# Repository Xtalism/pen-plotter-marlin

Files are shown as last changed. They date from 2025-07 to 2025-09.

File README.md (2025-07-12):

# Marlin CNC Pen Plotter

A custom Marlin firmware configuration for a 2-axis CNC pen plotter build. This project adapts the popular Marlin 3D printer firmware to control a pen plotting machine capable of drawing vector graphics and designs.

## Demonstration

https://github.com/user-attachments/assets/9c6dd8f6-1e95-47f4-82c9-25f74d2d10c8

## Features

- **2-Axis Control**: Precise X/Y movement for drawing applications
- **Servo Pen Control**: Automated pen lift/lower mechanism using servo motor
- **G-code Compatible**: Standard G-code interpretation for drawing commands
- **RAMPS 1.6 Based**: Uses standard 3D printer electronics (RAMPS 1.6 EFF)
- **PlatformIO Support**: Easy compilation and uploading using PlatformIO

## Hardware Requirements

- **Controller**: Arduino Mega 2560 with RAMPS 1.6 shield
- **Stepper Motors**: 2x stepper motors for X and Y axes
- **Servo Motor**: 1x servo for pen lift mechanism (connected to pin P0)
- **Stepper Drivers**: Compatible stepper motor drivers (A4988, DRV8825, etc.)
- **Power Supply**: 12V power supply for motors
- **Mechanical Frame**: Custom pen plotter frame (see blueprints/)

## Project Structure

```text
├── Marlin/                 # Modified Marlin firmware source code
├── gcode/                  # Example G-code files for testing
├── documentation/          # Project documentation (PDF)
├── blueprints/            # Hardware blueprints and schematics (PDF)
├── buildroot/             # Build tools and dependencies
├── platformio.ini         # PlatformIO configuration file
└── README.md              # This file
```

## Setup and Installation

### Prerequisites

1. Install [PlatformIO](https://platformio.org/) or use VS Code with PlatformIO extension
2. Clone this repository to your local machine

### Building and Uploading

1. Open the project in PlatformIO
2. Connect your Arduino Mega 2560 via USB
3. Build and upload the firmware:

   ```bash
   pio run --target upload
   ```

### Configuration

The main configuration is already set up for the pen plotter, but you may need to adjust:

- **Steps per mm**: Calibrate for your specific mechanical setup
- **Travel speeds**: Adjust drawing and travel speeds in `Configuration.h`
- **Servo angles**: Fine-tune pen up/down positions (currently S20 for down, S120 for up)

## Usage

### G-code Commands

The plotter responds to standard G-code commands:

- `G1 X## Y##`: Linear move to coordinates
- `G2/G3`: Circular/arc movements
- `M280 P0 S##`: Servo control (pen up/down)
  - `M280 P0 S20`: Pen down (drawing)
  - `M280 P0 S120`: Pen up (travel)
- `G28`: Home axes
- `G90`: Absolute positioning
- `G91`: Relative positioning

### Example Drawing Sequence

```gcode
M280 P0 S20        ; Pen up
G28 X Y            ; Home X and Y axes
G90                ; Absolute positioning
G1 F6000           ; Set feed rate
G1 X10 Y10         ; Move to start position
M280 P0 S120       ; Pen down
G1 X50 Y10         ; Draw line
G1 X50 Y50         ; Draw line
G1 X10 Y50         ; Draw line
G1 X10 Y10         ; Draw line (complete square)
M280 P0 S20        ; Pen up
```

## Sample Files

Check the `gcode/` directory for example drawing files. The included `UACJ.g` file demonstrates complex curved drawing using G2 arc commands.

## Documentation

- **Hardware Plans**: See `blueprints/blueprints.pdf` for mechanical drawings
- **Technical Documentation**: See `documentation/documentation.pdf` for detailed setup instructions

## Troubleshooting

### Common Issues

1. **Pen not lifting/lowering properly**
   - Check servo connections (should be connected to pin P0)
   - Adjust servo angle values in G-code (S20 for down, S120 for up)
   - Verify servo power supply

2. **Incorrect movement scaling**
   - Calibrate steps per mm in `Configuration.h`
   - Check belt tension and mechanical backlash

3. **Communication issues**
   - Verify baud rate settings (typically 250000)
   - Check USB cable and connections

## Contributing

This is a specialized firmware configuration. When making changes:

1. Test thoroughly with sample G-code
2. Document any configuration changes
3. Update this README if adding new features

## License

This project is based on Marlin firmware and inherits its GPL v3.0 license. See `LICENSE` file for details.

## Acknowledgments

- Based on [Marlin Firmware](https://github.com/MarlinFirmware/Marlin)
- Adapted for CNC pen plotting applications
- Thanks to the RepRap and maker communities for hardware designs

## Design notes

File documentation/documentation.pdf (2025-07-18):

# AUTONOMOUS UNIVERSITY OF CIUDAD JUAREZ ´

### MULTIDISCIPLINARY DIVISION OF CIUDAD UNIVERSITARIA

## DEPARTMENT OF INDUSTRIAL AND MANUFACTURING ENGINEERING

# Pen Plotter CNC

# Motors and Controllers

## Team Members:

## Manuel Pi˜na Olivas - 201060 Francisco Javier Hern´andez Guti´errez - 201215 Brenda Lizeth Mu˜noz Silva - 201820 Josu´e Jim´enez Ram´ırez - 201133 Luis Armando Enciso Nava - 215766

## Instructor:

## Mario Jim´enez Jim´enez

## July 15, 2025

# Contents

1 Introduction | 4
2 Objectives | 4
3 Theoretical Framework | 4
4 Requirements | 4
5 Implementation | 9
6 Results | 12
7 Conclusion | 13
8 Appendices | 14

# List of Figures

1 | WeMos Mega WiFi R3 ATmega2560 + ESP8266 32MB | | 4
2 | Ramps 1.6 | | 5
3 | 17HD48002H-22B | | 5
4 | SG90 | | 6
5 | RepRapDiscount 12864 | | 6
6 | DRV8825 | | 7
7 | Korad KD3005D | | 7
8 | Marlin Firmware | | 7
9 | PlatformIO | | 8
10 | VSCode | | 8
11 | Inkscape | | 8
12 | Pronterface | | 9
13 | Mini CNC Plotter Kit | | 9
14 | SolidWorks Design | 10
15 | Diagram made in Fritzing | 10
16 | Motor connections with Ramps 1.6 | 11
17 | Laser tool extension for Inkscape | 11
18 | Pronterface user interface | 12
19 | Results | 12
20 | Results | 13

# 1 Introduction

In this project, we will build a simple CNC machine to draw the logo of the Autonomous University of Ciudad Ju´arez (UACJ) on paper. We will use stepper motors to move a pencil, pen, or marker with precision, controlled by an Arduino board and configured with the respective Marlin firmware.

# 2 Objectives

Design and build a CNC machine controlled by Arduino and Marlin firmware, capable of autonomously drawing the UACJ logo on paper, using two stepper motors for the x and y axes, and a servomotor for the z axis.

## 2.1 Specific Objectives

- Design the mechanical structure of the CNC, ensuring stability and precision.
- Implement stepper motor control using Arduino.
- Configure the system using Marlin firmware.
- Generate G-code from a design in Inkscape.
- Test and calibrate the machine to ensure proper operation and precision.

# 3 Theoretical Framework

## 3.1 What is a CNC machine?

CNC (Computer Numerical Control) is an automated machine system that works with programmed commands or functions, whose instructions are stored on a storage disk. It is a machine tool used for:

- Machining parts from various materials.
- Automated processes.
- Computer programming.
- Computer control.

# 4 Requirements

## 4.1 Hardware

## 4.1.1 Microcontroller

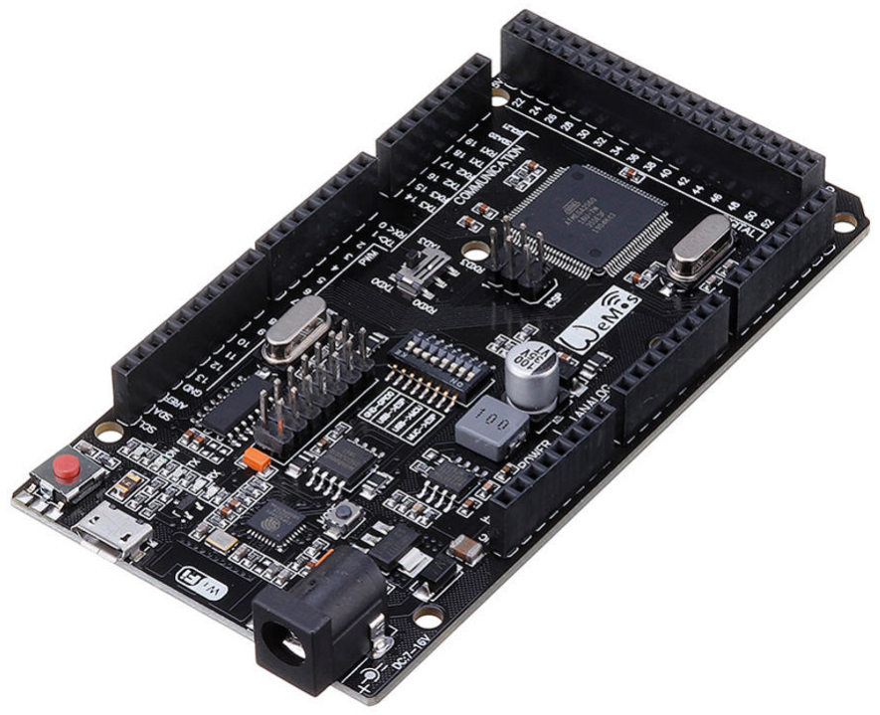
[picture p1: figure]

Figure 1: WeMos Mega WiFi R3 ATmega2560 + ESP8266 32MB.

The Arduino is an open-source electronic board based on a reprogrammable microcontroller. It is designed to facilitate the development of electronic projects through the connection of various sensors, actuators, and other devices through its digital and analog input and output pins.

## 4.1.2 Expansion Board

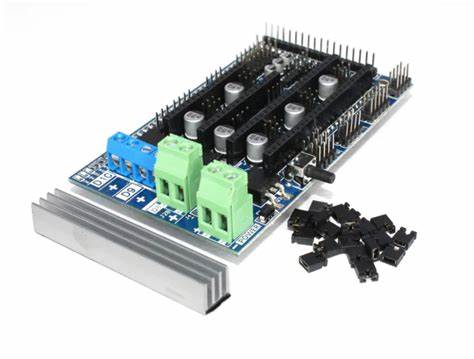
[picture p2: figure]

Figure 2: Ramps 1.6.

## The Ramps 1.6 expansion board is designed to be mounted on an Arduino Mega 2560. Its

main function is to facilitate the connection and control of up to five stepper motors independently, corresponding to the X, Y, Z axes and two extruders (E0 and E1). This board is commonly used in 3D printers and CNC machines, as it allows the integration of drivers such as A4988 or DRV8825, in addition to other components such as switches, fans, and thermistors.

## 4.1.3 Stepper Motor

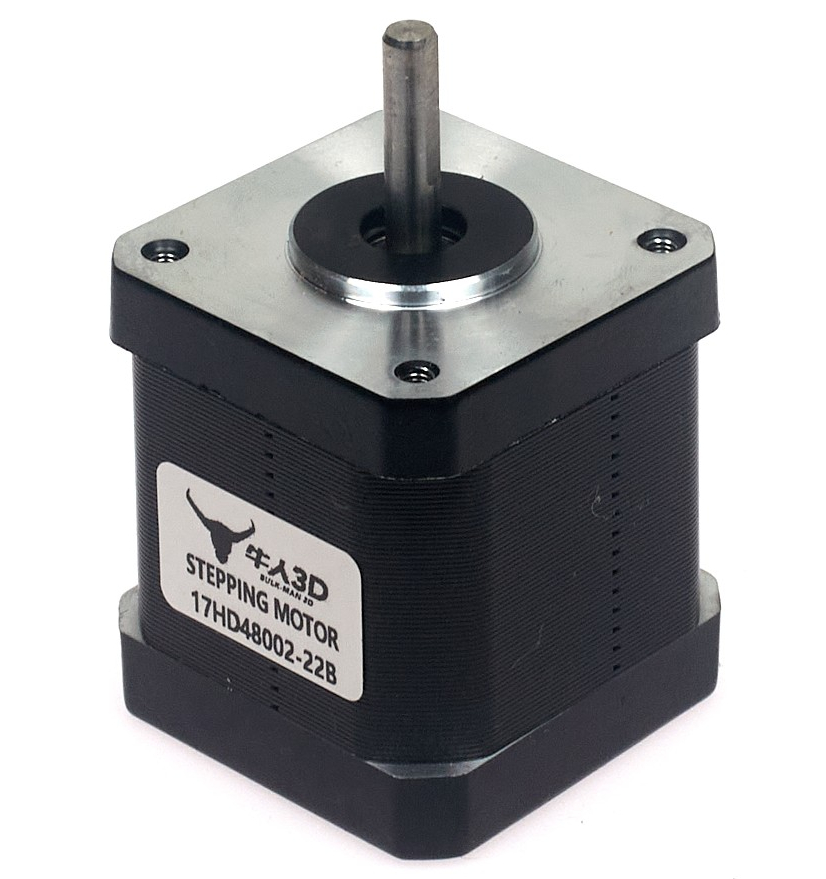
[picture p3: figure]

Figure 3: 17HD48002H-22B.

It is a NEMA 17 type stepper motor, ideal for precision applications such as CNC machines. It offers a step angle of 1.8° (200 steps per revolution) and operates with a current of 1.5 A per phase. Its compact size and good torque make it suitable for moving the x, y, and z axes of the project with high precision.

## 4.1.4 Servomotor

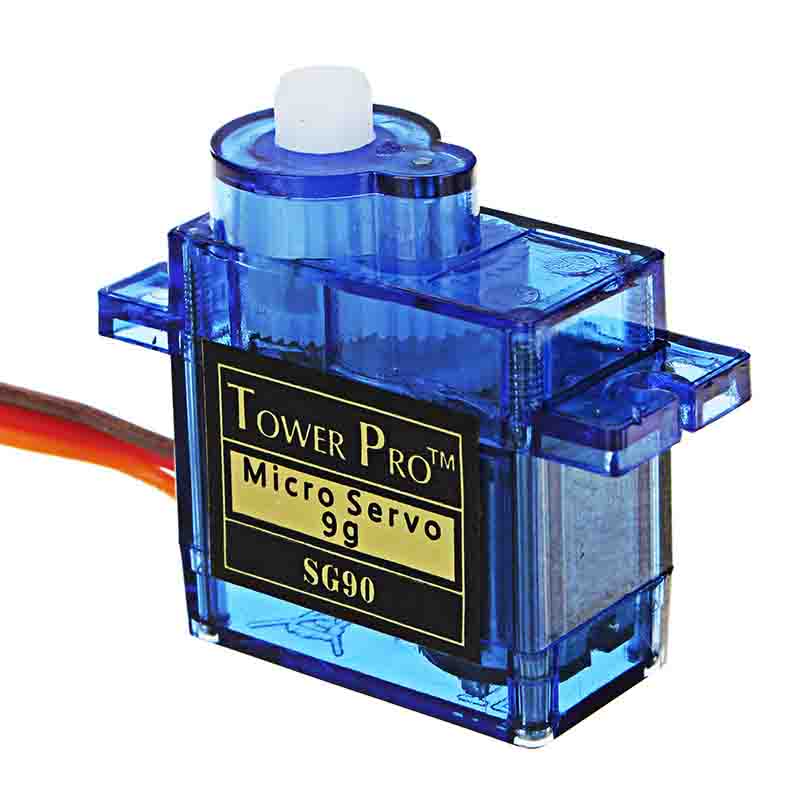
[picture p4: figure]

Figure 4: SG90.

The SG90 servomotor is a compact and lightweight actuator commonly used in robotics. It operates on 4.8–6V and rotates about 180°, controlled by PWM signals. In this project, it lifts and lowers the pen, allowing the CNC to draw or move without marking the paper.

## 4.1.5 Display Screen

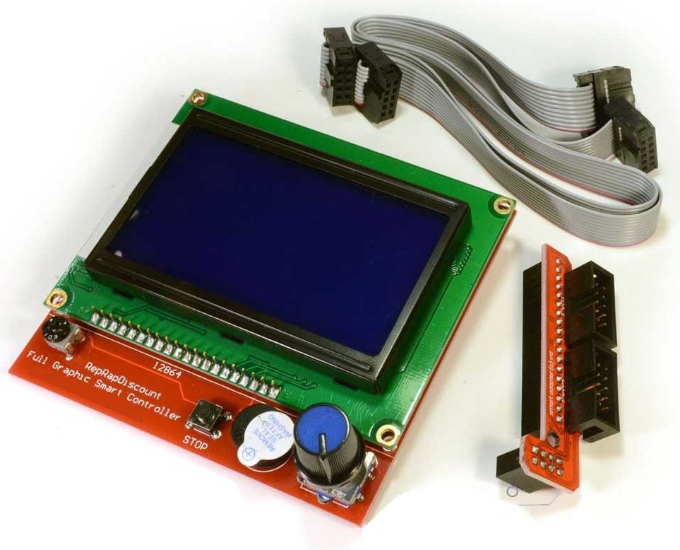
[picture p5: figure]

Figure 5: RepRapDiscount 12864.

It is a complete module that includes a 128×64 pixel dot matrix LCD screen, an SD card reader, and a rotary encoder. This device allows controlling a 3D printer or CNC machine autonomously, without the need for a computer, displaying process information and facilitating navigation through the firmware menu.

## 4.1.6 Drivers

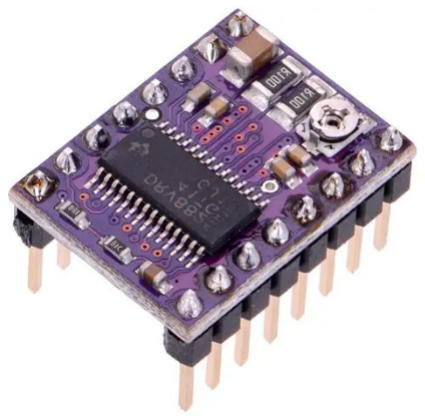
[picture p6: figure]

Figure 6: DRV8825.

The DRV8825 driver is a bipolar stepper motor controller, which is used to control stepper motors, especially in applications that require high precision and movement resolution, such as 3D printers and CNC machines.

## 4.1.7 Adjustable Power Supply

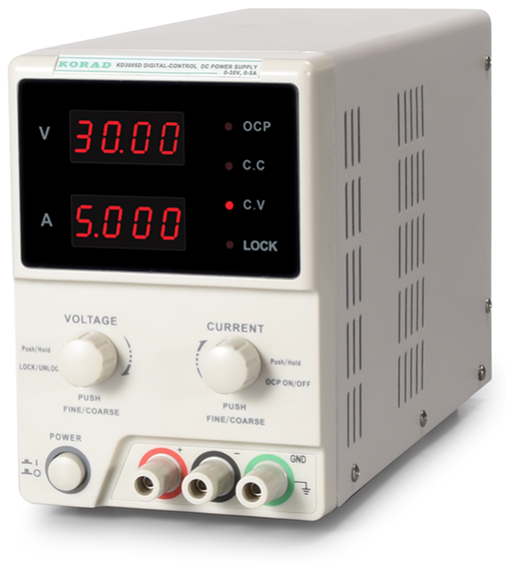
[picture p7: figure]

Figure 7: Korad KD3005D.

The Korad KD3005D power supply is a versatile instrument designed for various electronic applications. It features an adjustable voltage range of up to 30V and a maximum current of 5A.

## 4.2 Software

## 4.2.1 Marlin Firmware

Figure 8: Marlin Firmware.

Marlin is an open-source firmware widely used to control 3D printers, CNC machines, laser engravers, and plotters. It is responsible for interpreting G-code commands and converting them into physical movements, controlling motors, servos, and sensors. It is compatible with boards such as RAMPS or SKR, and allows easy configuration of parameters such as axes, limits, and servomotors.

## 4.2.2 PlatformIO

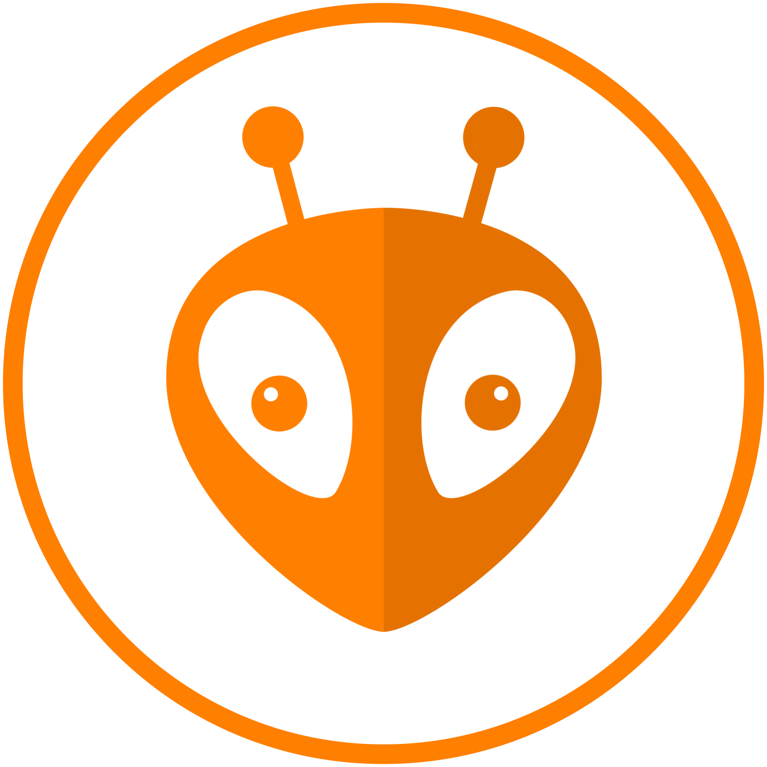
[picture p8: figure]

Figure 9: PlatformIO.

PlatformIO is an open-source development environment used with Visual Studio Code to program microcontrollers. It allows compiling and uploading firmware like Marlin quickly and in an organized manner.

## 4.2.3 VSCode

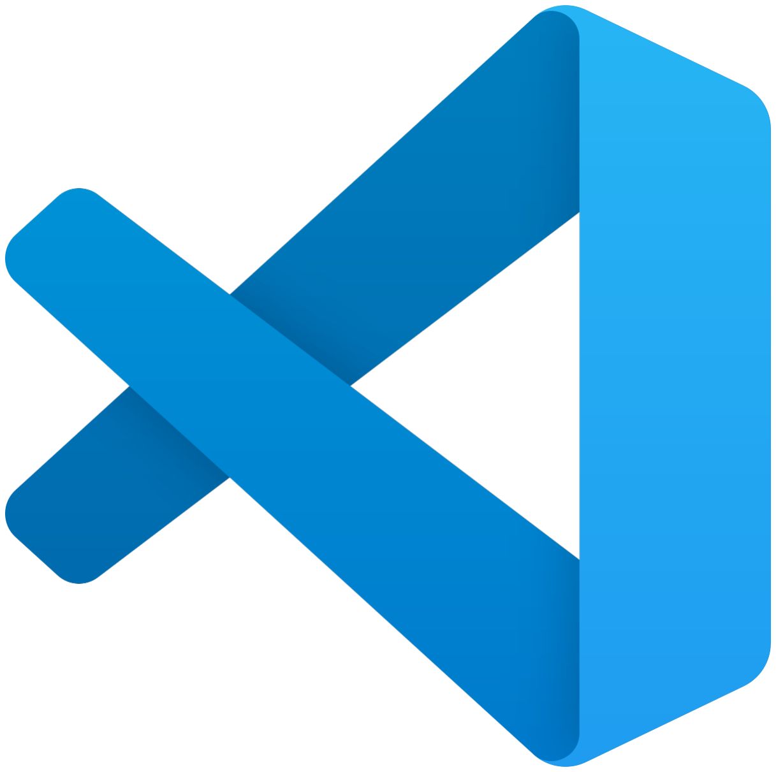
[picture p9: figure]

Figure 10: VSCode.

Visual Studio Code (VS Code) is a lightweight and cross-platform code editor developed by Microsoft. It is widely used by programmers thanks to its speed, customization, and support for extensions.

## 4.2.4 Inkscape

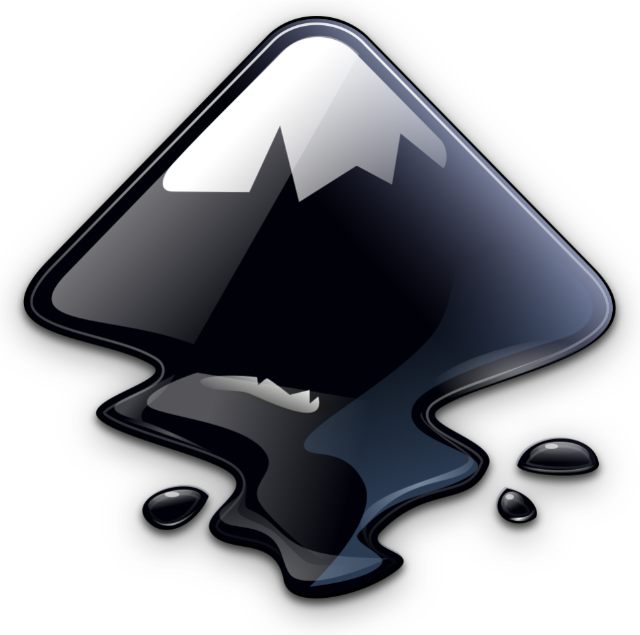
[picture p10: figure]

Figure 11: Inkscape.

Inkscape is an open-source vector graphics design software, used to create and edit images in SVG format.

## 4.2.5 Pronterface

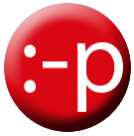
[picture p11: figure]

Figure 12: Pronterface.

Pronterface is a graphical interface of the Printrun program, used to control 3D printers and CNC machines from a computer. It allows sending G-code commands, moving axes, controlling temperature (in 3D printers), and monitoring the machine’s status in real time.

# 5 Implementation

## 5.1 Structure

We had an already built structure made of pressed wood, which was adapted according to the needs that arose during the project development. In particular, modifications were made to the axes and the arrangement of the motors within the structure was changed.

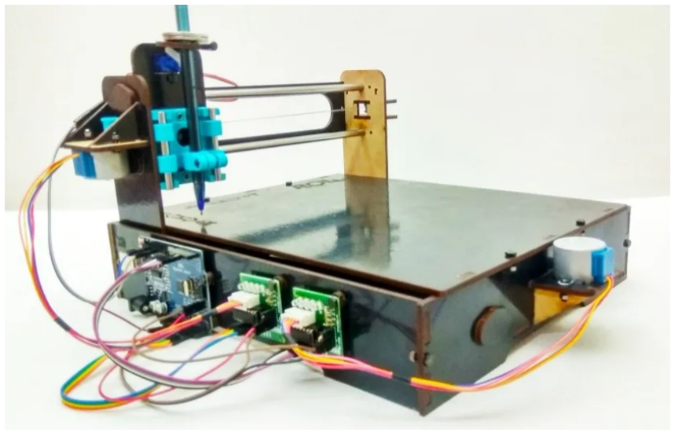
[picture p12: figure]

Figure 13: Mini CNC Plotter Kit.

## 5.2 Motor Assembly

The structure design was created in SolidWorks according to the requested structure.

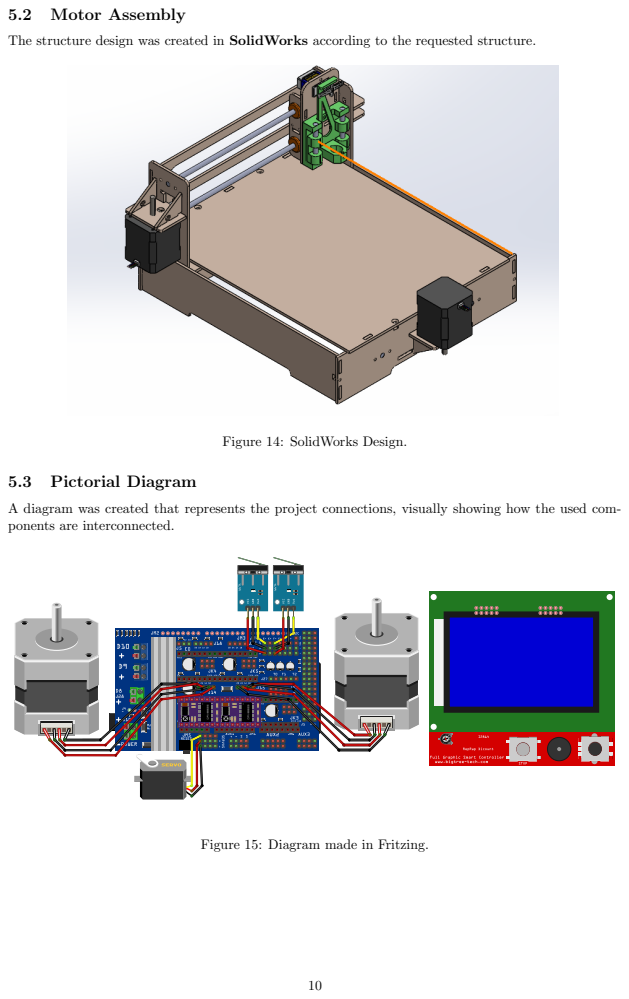
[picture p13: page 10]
5.3 Pictorial Diagram

Figure 14: SolidWorks Design.

A diagram was created that represents the project connections, visually showing how the used com-
ponents are interconnected.

Figure 15: Diagram made in Fritzing.

## 5.4 Motor Testing and Connection

After generating the G-code, a test was performed with the NEMA 17 stepper motors. Using the RepRapDiscount controller, it was possible to start and stop work directly from the SD card. Additionally, this controller allows easy adjustment of parameters such as motor position and speed.

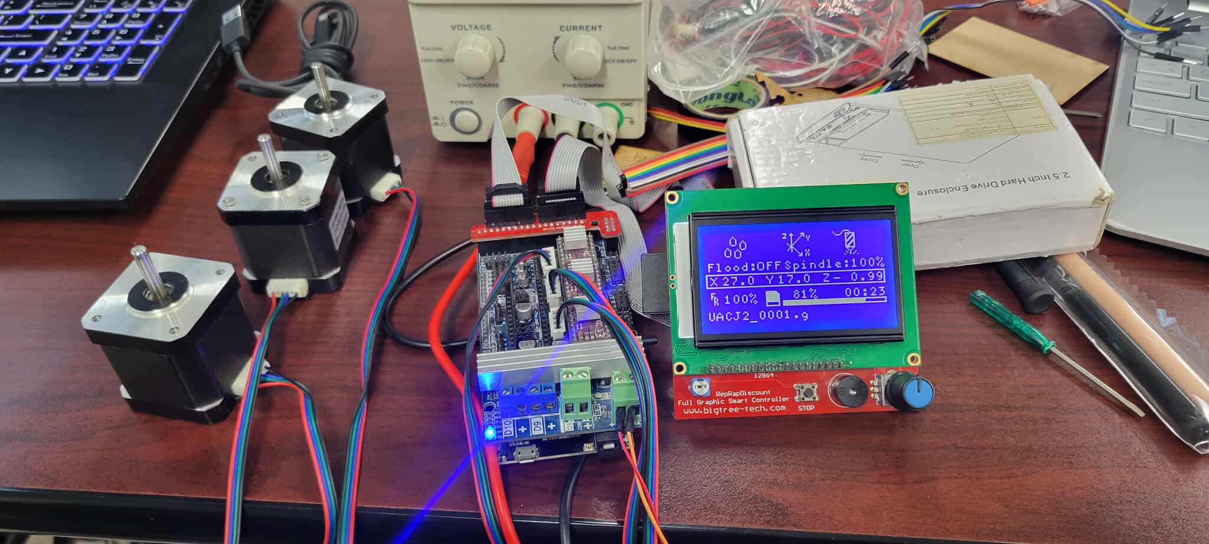
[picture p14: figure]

Figure 16: Motor connections with Ramps 1.6.

## 5.5 G-code Generation

During the project, Inkscape software was used to design vector graphics. Then, with the help of the J Tech Photonics Laser Tool extension, we converted these designs into G-code, which can be interpreted by the intelligent graphic controller RepRapDiscount 12864. This controller works together with stepper motors and Marlin firmware, allowing the motors to perform the necessary movements for engraving with precision.

At the bottom, the offset is defined, which corresponds to the distance difference between the limit switch and the tool tip (in this case, a pen).

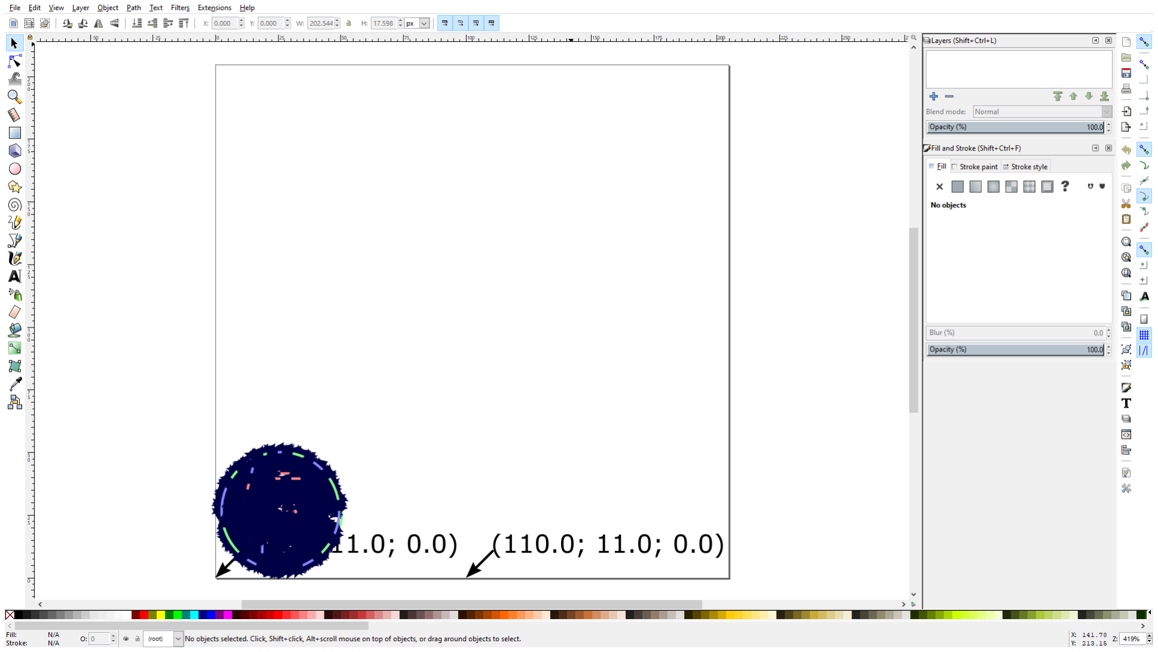
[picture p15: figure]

Figure 17: Laser tool extension for Inkscape.

## 5.6 Pronterface Graphical Interface

The Pronterface tool was used, which helps us manipulate our CNC machine in real time, usually used in 3D printer applications, since it has extruder calibration and other tools that conventional CNC does not have.

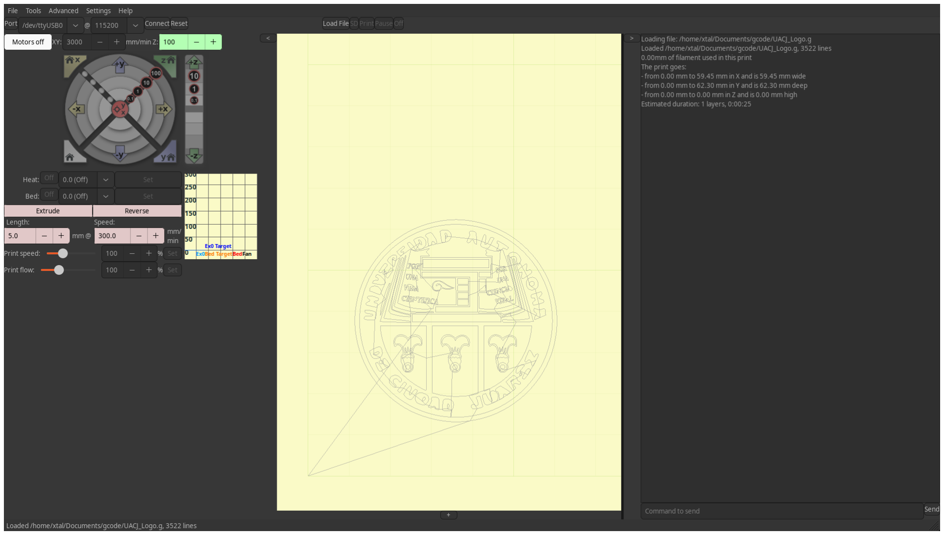
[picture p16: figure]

Figure 18: Pronterface user interface.

# 6 Results

In this project we were asked to build a machine capable of drawing our university’s logo on a sheet of paper. At first, we faced several problems related to the structure, motor calibration, Marlin firmware adjustment, and converting the logo design to G-code, so that the machine could interpret it correctly.

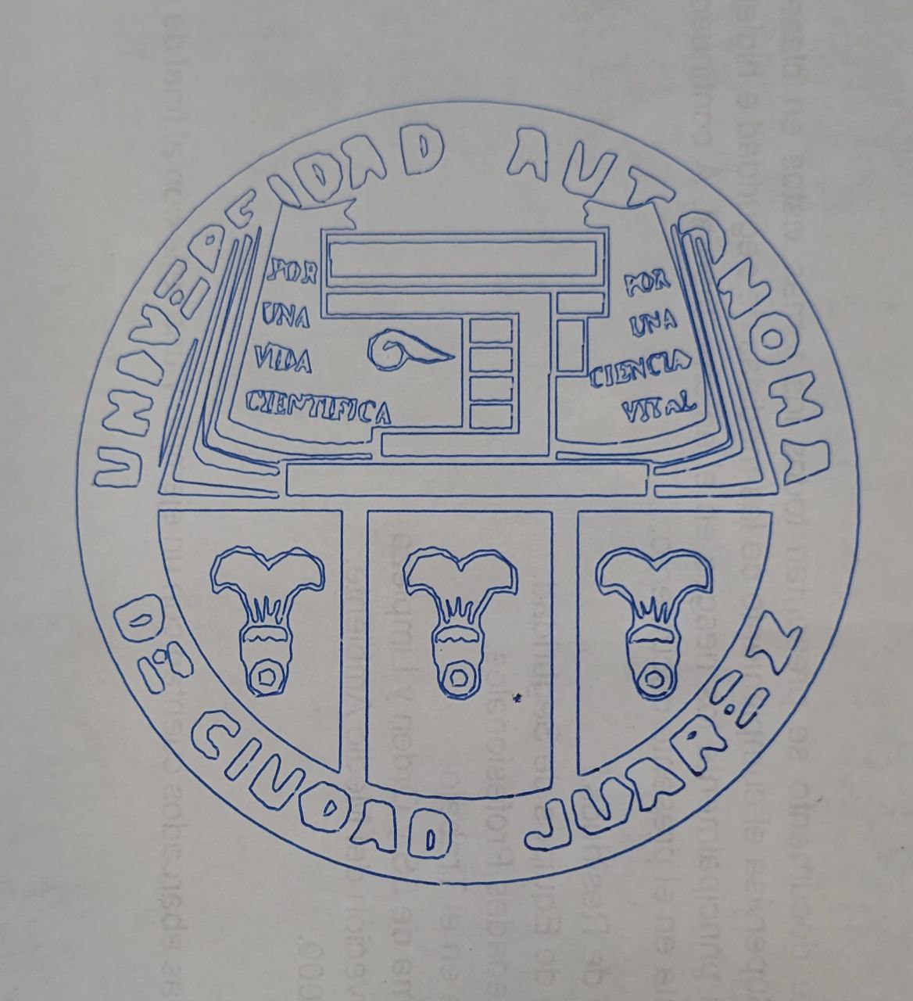
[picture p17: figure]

Figure 19: Results.

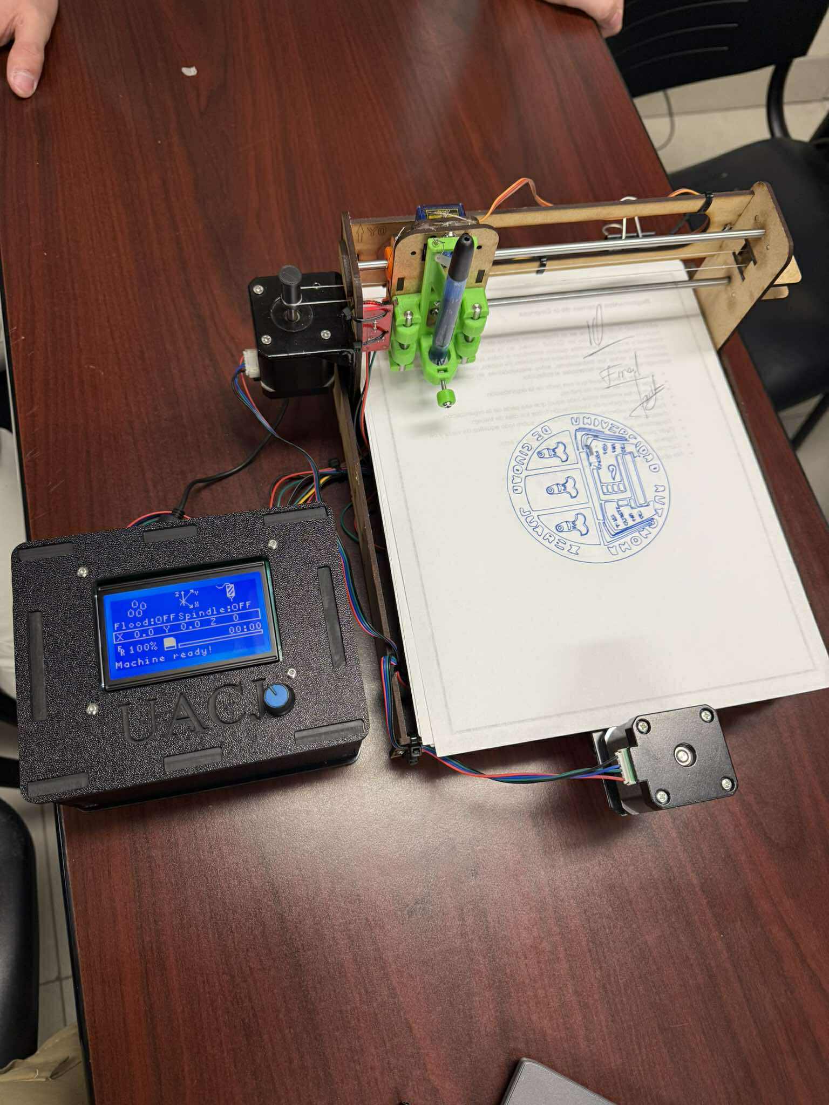
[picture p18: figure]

Figure 20: Results.

# 7 Conclusion

A favorable results were obtained, as the main objective of the project was met: tracing our university’s logo on a sheet of paper using a CNC machine. To achieve this, it was necessary to correctly calibrate the NEMA 17 motors, adjust the firmware, precisely define the auto-homing point, and configure the appropriate servomotor angle.

# 8 Appendices

## 8.1 Code

## 8.1.1 UACJ Logo.g

M280 P0 S20

G28 X Y
G90
G21
G1 F6000
G1 X34 .7377 Y14 .3117
G4 P0
M280 P0 S120
G4 P0
G1 F6000 .000000
G2 X26 .4091 Y16 .3335 I1 .334 J23 .6603 G2 X19 .3821 Y21 .1688 I9 .571 J21 .4332 G2 X12 .6272 Y35 .4445 I16 .5822 J16 .5823 G2 X16 .4597 Y50 .7368 I23 .2545 J2 .2983 G2 X21 .9957 Y56 .5497 I19 .5624 J -13.088 G2 X29 .1377 Y60 .1452 I13 .9169 J -18.7533 G2 X34 .9376 Y61 .1307 I6 .7886 J -22.3931 G2 X40 .8819 Y60 .6419 I1 .0162 J -24.0294 G2 X49 .1268 Y57 .1466 I -4.7447 J -22.6641 G2 X55 .4987 Y50 .7368 I -13.2307 J -19.5245 G2 X59 .4501 Y37 .7245 I -19.4494 J -13.0123 G2 X55 .4987 Y24 .7122 I -23.4008 J -0.
G2 X49 .0307 Y18 .2314 I -19.66 J13 .1532 G2 X40 .6969 Y14 .7669 I -12.8175 J19 .0766 G2 X37 .5845 Y14 .3401 I -5.1057 J25 .6673 G2 X34 .7377 Y14 .3117 I -1.6371 J21 .4313 G1 X34 .7377 Y14 .3117
G4 P0
M280 P0 S20
G1 F6000
G1 X35 .0065 Y16 .0285
G4 P0
M280 P0 S120
G4 P0
G1 F6000 .000000
G3 X35 .1255 Y16 .2189 I -0.6845 J0 .5602 G3 X35 .2755 Y16 .6132 I -2.8294 J1 .3021 G3 X35 .3128 Y17 .8567 I -2.2662 J0 .6904 G3 X34 .8347 Y18 .4489 I -0.8623 J -0.2071 G3 X33 .6066 Y18 .7623 I -1.3938 J -2.8994 G3 X33 .0325 Y18 .5414 I -0.039 J -0.7553 G3 X32 .8354 Y18 .1516 I0 .4932 J -0.4941 G3 X32 .6715 Y16 .1507 I14 .5893 J -2.2024 G1 X32 .758 Y16 .0081
G3 X33 .2686 Y15 .8505 I0 .7246 J1 .4416 G3 X34 .6362 Y15 .8293 I0 .7737 J5 .7772 G3 X35 .0065 Y16 .0282 I -0.0562 J0 .5486 G1 X35 .0065 Y16 .0285
G4 P0
M280 P0 S20
G1 F6000
G1 X33 .8685 Y16 .3294
G4 P0
M280 P0 S120
G4 P0
G1 F6000 .000000
G1 X33 .8441 Y16 .4179 F6000 .000000 G2 X33 .8757 Y16 .8033 I2 .9091 J -0.0446 G3 X33 .9285 Y17 .1948 I -13.3793 J2 .006 G3 X33 .9428 Y17 .3618 I -2.416 J0 .2904
G1 | X33 .9971 Y17 .4811
G1 | X34 .1168 Y17 .5294
G1 | X34 .2213 Y17 .4643
G2 X34 .3074 Y17 .1406 I -0.7731 J -0.3791

G2 X34 .1312 Y16 .3371 I -1.4841 J -0.0956
G1 | X33 .8684 Y16 .3295
G1 | X33 .8685 Y16 .3294
G4 P0
M280 P0 S20
G1 F6000
G1 X31 .9234 Y16 .2258
G4 P0
M280 P0 S120
G4 P0
G1 F6000 .000000
G3 X31 .8001 Y18 .6873 I -25.5462 J -0.0456 G3 X31 .6559 Y18 .9357 I -0.3445 J -0.034 G3 X31 .2165 Y19 .1315 I -0.7072 J -0.9959 G3 X30 .3642 Y19 .2261 I -0.8522 J -3.792 G3 X30 .0654 Y19 .0334 I0 . J -0.3281
G3 X30 .0285 Y18 .4853 I0 .7134 J -0.3233 G2 X30 .0193 Y18 .1896 I -0.4477 J -0.1341 G2 X29 .6592 Y17 .4834 I -3.1474 J1 .1599
G1 | X29 .1967 Y16 .7925
G1 | X29 .4523 Y16 .685
G3 X30 .0127 Y16 .6056 I0 .4312 J1 .0254 G3 X30 .302 Y16 .7844 I -0.0466 J0 .399 G2 X30 .7416 Y16 .937 I0 .3187 J -0.2088 G2 X30 .957 Y16 .5654 I -0.1029 J -0.3079 G3 X30 .9273 Y16 .343 I1 .698 J -0.3399
G1 | X30 .9408 Y16 .328
G1 | X30 .971 Y16 .3224
G2 X31 .3029 Y16 .2075 I -4.6817 J -14.0476 G3 X31 .8247 Y16 .1245 I0 .4788 J1 .329
G1 | X31 .9234 Y16 .2265
G1 | X31 .9234 Y16 .2258
G4 P0
M280 P0 S20
G1 F6000
G1 X28 .556 Y17 .4023
G4 P0
M280 P0 S120
G4 P0
G1 F6000 .000000
G3 X28 .7645 Y17 .5703 I -0.5352 J0 .8773 G3 X29 .0733 Y17 .9446 I -2.4472 J2 .3336 G3 X29 .3233 Y18 .6451 I -1.1155 J0 .793 G3 X29 .1716 Y19 .3948 I -1.4443 J0 .0979 G3 X28 .9186 Y19 .6898 I -0.7243 J -0.3652 G3 X28 .2819 Y20 .0299 I -1.6256 J -2.2774 G3 X27 .5769 Y20 .2892 I -15.0499 J -39.8365 G1 X27 .5301 Y20 .2989
G3 X26 .1743 Y19 .4646 I -0.1074 J -1.3442 G3 X26 .5103 Y17 .8202 I1 .3976 J -0.5709 G3 X26 .5947 Y17 .7602 I0 .2245 J0 .2264 G3 X27 .2473 Y17 .4594 I6 .8276 J13 .9536 G3 X28 .0559 Y17 .2734 I0 .9083 J2 .0973 G3 X28 .556 Y17 .4023 I0 .0386 J0 .8845 G1 X28 .556 Y17 .4023
G4 P0
M280 P0 S20
G1 F6000
G1 X27 .7025 Y18 .2689
G4 P0
M280 P0 S120
G4 P0
G1 F6000 .000000
G1 X27 .7092 Y18 .3035 F6000 .000000
G2 X27 .9177 Y18 .8011 I20 .1741 J -8.1607 G2 X28 .1642 Y19 .2228 I1 .8765 J -0.8137 G1 X28 .2576 Y19 .2495
G2 X28 .4956 Y18 .6796 I -0.1531 J -0.3985 G2 X27 .8122 Y18 .2329 I -0.6834 J0 .2995
G1 | X27 .7169 Y18 .2487
G1 | X27 .7025 Y18 .2687

G1 X27 .7025 Y18 .2689
G4 P0
M280 P0 S20
G1 F6000
G1 X25 .9498 Y19 .6144
G4 P0
M280 P0 S120
G4 P0
G1 F6000 .000000
G3 X26 .5964 Y20 .6586 I -7.1429 J5 .1454 G1 X26 .5777 Y20 .807
G3 X26 .4348 Y20 .9289 I -0.5434 J -0.4925 G3 X26 .2021 Y21 .0515 I -0.7764 J -1.1913 G1 X25 .9508 Y21 .0094
G3 X25 .3784 Y20 .3231 I1 .9616 J -2.2179 G2 X24 .9442 Y19 .7548 I -2.8184 J1 .7031 G2 X24 .7432 Y19 .6563 I -0.2337 J0 .2226 G1 X24 .5777 Y19 .8276
G2 X24 .8848 Y20 .696 I2 .2463 J -0.3059 G3 X25 .1138 Y21 .5274 I -1.3549 J0 .8204 G3 X24 .8766 Y21 .8797 I -0.3843 J -0.0027 G1 X24 .609 Y21 .8255
G3 X23 .7825 Y20 .7712 I4 .1923 J -4.1374
G1 | X23 .2317 Y19 .8745
G1 | X23 .3907 Y19 .6538
G3 X24 .2736 Y18 .7924 I2 .9027 J2 .092 G3 X24 .9788 Y18 .5677 I0 .7272 J1 .0632 G1 X25 .154 Y18 .6415
G3 X25 .9499 Y19 .6144 I -7.527 J6 .9689 G1 X25 .9498 Y19 .6144
G4 P0
M280 P0 S20
G1 F6000
G1 X23 .2241 Y21 .354
G4 P0
M280 P0 S120
G4 P0
G1 F6000 .000000
G3 X23 .985 Y22 .4049 I -12.6428 J9 .955 G1 X23 .9801 Y22 .4921
G3 X23 .8989 Y22 .5679 I -0.3429 J -0.2861 G3 X23 .6612 Y22 .7231 I -1.7558 J -2.4285
G1 | X23 .4145 Y22 .868
G1 | X22 .5692 Y21 .8273
G1 | X21 .7239 Y20 .7866
G1 | X21 .956 Y20 .5444
G3 X22 .2006 Y20 .3317 I1 .2837 J1 .2293
G1 | X22 .292 Y20 .3022
G1 | X22 .3773 Y20 .3406
G3 X23 .2241 Y21 .3541 I -17.0127 J15 .0761 G1 X23 .2241 Y21 .354
G4 P0
M280 P0 S20
G1 F6000
G1 X21 .2813 Y21 .5938
G4 P0
M280 P0 S120
G4 P0
G1 F6000 .000000
G1 X21 .3673 Y21 .6747 F6000 .000000 G3 X21 .4122 Y21 .8824 I -0.4591 J0 .2077 G3 X21 .3454 Y22 .084 I -0.3379 J0 .
G3 X21 .0779 Y22 .3318 I -0.799 J -0.5942 G2 X20 .6998 Y22 .7905 I0 .507 J0 .8032 G2 X20 .7192 Y23 .2536 I0 .5381 J0 .2094 G2 X21 .1257 Y23 .6114 I0 .6335 J -0.3098 G2 X21 .6458 Y23 .5687 I0 .2109 J -0.6202 G2 X21 .9111 Y23 .3696 I -0.5152 J -0.9627 G2 X22 .0685 Y23 .1368 I -0.5613 J -0.5492 G3 X22 .2232 Y22 .9235 I0 .5714 J0 .2516 G1 X22 .3688 Y22 .8678

G3 X22 .7444 Y23 .471 I0 . J0 .4185
G3 X21 .5931 Y24 .4456 I -1.6926 J -0.8322 G3 X20 .4753 Y24 .3138 I -0.4067 J -1.3574 G3 X19 .7619 Y23 .3832 I0 .7719 J -1.3306 G3 X19 .7026 Y23 .0392 I1 .8319 J -0.4931 G3 X19 .7192 Y22 .841 I0 .6133 J -0.0483 G3 X19 .9435 Y22 .4025 I1 .0613 J0 .2664 G3 X20 .6108 Y21 .7823 I2 .8637 J2 .4118 G3 X21 .025 Y21 .5819 I0 .7692 J1 .0619 G3 X21 .2812 Y21 .5938 I0 .1103 J0 .3922 G1 X21 .2813 Y21 .5938
G4 P0
M280 P0 S20
G1 F6000
G1 X23 .6592 Y25 .3258
G4 P0
M280 P0 S120
G4 P0
G1 F6000 .000000
G2 X23 .4116 Y25 .4962 I0 .4589 J0 .9321 G2 X23 .1754 Y25 .7744 I1 .0439 J1 .1255 G2 X23 .0349 Y26 .1042 I0 .8266 J0 .5469 G2 X22 .9968 Y26 .57 I1 .6431 J0 .3689
G3 X22 .9594 Y27 .033 I -1.683 J0 .097
G3 X22 .8358 Y27 .2937 I -0.6342 J -0.1411 G2 X22 .7019 Y27 .5524 I0 .6097 J0 .4797 G2 X22 .6522 Y27 .9115 I1 .152 J0 .3424 G3 X22 .6436 Y28 .2884 I -5.1362 J0 .0717 G3 X22 .6039 Y28 .7216 I -6.7752 J -0.4033 G2 X22 .6459 Y29 .1212 I0 .8812 J0 .1092 G2 X22 .8611 Y29 .4649 I0 .8547 J -0.2958
G1 | X23 .1719 Y29 .7757
G1 | X23 .0742 Y30 .3061
G3 X22 .5764 Y31 .4827 I -2.9046 J -0.5352 G3 X21 .9681 Y31 .8613 I -0.7571 J -0.5385 G3 X21 .6953 Y31 .84 I -0.0925 J -0.573 G3 X21 .4559 Y31 .6925 I0 .1868 J -0.5713 G2 X21 .2337 Y31 .4889 I -2.4357 J2 .4357
G1 | X21 .1975 Y31 .4758
G1 | X20 .9903 Y31 .6273
G2 X20 .8346 Y32 .6165 I3 .1534 J1 .003 G2 X21 .2956 Y33 .7747 I1 .6679 J0 .007 G2 X22 .4886 Y34 .3506 I1 .3631 J -1.3001 G2 X23 .2458 Y34 .247 I0 .154 J -1.6933 G2 X24 .0375 Y33 .763 I -0.8899 J -2.3451
G1 | X24 .3664 Y33 .4658
G1 | X24 .5551 Y33 .6667
G2 X26 .1692 Y34 .3058 I1 .4865 J -1.3964 G2 X27 .5534 Y33 .4788 I -0.1101 J -1.7561 G2 X27 .6781 Y33 .1536 I -0.7834 J -0.4872 G2 X27 .7439 Y32 .4109 I -4.1631 J -0.7427 G2 X27 .5359 Y31 .7328 I -1.2093 J -0.
G1 X27 .2471 Y31 .6774
G3 X26 .7261 Y31 .8498 I -0.5643 J -0.8315 G3 X26 .2278 Y31 .7214 I -0.0381 J -0.883 G3 X25 .8212 Y31 .2751 I0 .5601 J -0.9187 G3 X25 .4811 Y30 .1935 I3 .4098 J -1.6663 G3 X25 .4831 Y29 .7198 I1 .4789 J -0.2306 G3 X25 .6013 Y29 .4629 I0 .5264 J0 .0866 G2 X25 .8065 Y28 .9725 I -0.681 J -0.573 G2 X25 .6873 Y28 .5406 I -0.6296 J -0.0587 G1 X25 .6376 Y28 .3828
G3 X25 .6955 Y28 .148 I0 .5521 J0 .0116 G2 X25 .7579 Y27 .9059 I -0.5345 J -0.2667 G2 X25 .7154 Y27 .6666 I -0.564 J -0.0232 G2 X25 .5981 Y27 .4383 I -1.4462 J0 .5988 G2 X25 .5118 Y27 .3394 I -0.3485 J0 .2169 G1 X25 .4657 Y27 .2367
G3 X25 .5268 Y26 .8925 I1 .2337 J0 .0415 G2 X25 .1313 Y25 .5034 I -1.2231 J -0.4026 G2 X23 .6592 Y25 .3257 I -0.8723 J1 .0397

G1 X23 .6592 Y25 .3258
G4 P0
M280 P0 S20
G1 F6000
G1 X23 .8952 Y26 .0958
G4 P0
M280 P0 S120
G4 P0
G1 F6000 .000000
G2 X23 .8252 Y26 .8236 I0 .4063 J0 .4063 G2 X24 .5012 Y26 .9935 I0 .4328 J -0.2922 G2 X24 .7172 Y26 .7831 I -0.2476 J -0.47 G2 X24 .8044 Y26 .4522 I -0.5966 J -0.3342 G2 X24 .4796 Y25 .9738 I -0.5115 J -0.0023 G2 X23 .8952 Y26 .0958 I -0.199 J0 .5075 G1 X23 .8952 Y26 .0958
G4 P0
M280 P0 S20
G1 F6000
G1 X24 .9593 Y25 .6433
G4 P0
M280 P0 S120
G4 P0
G1 F6000 .000000
G3 X25 .3568 Y26 .4394 I -0.7217 J0 .8577 G3 X25 .0475 Y27 .2482 I -1.0597 J0 .0583 G3 X24 .334 Y27 .5566 I -0.7458 J -0.7458 G3 X23 .576 Y27 .2931 I -0.0344 J -1.1231 G3 X23 .211 Y26 .6299 I0 .677 J -0.8046 G3 X23 .3821 Y25 .8645 I1 .1186 J -0.1518 G3 X24 .1115 Y25 .3993 I0 .874 J0 .566 G3 X24 .9593 Y25 .6432 I0 .1505 J1 .0725 G1 X24 .9593 Y25 .6433
G4 P0
M280 P0 S20
G1 F6000
G1 X23 .0087 Y28 .6614
G4 P0
M280 P0 S120
G4 P0
G1 F6000 .000000
G1 | X23 .1416 Y28 .8079 F6000 .000000
G1 | X23 .2331 Y28 .7442
G1 | X23 .376 Y28 .6166
G1 | X23 .5941 Y28 .7856
G1 | X23 .7776 Y28 .9359
G1 | X23 .8952 Y28 .8366
G1 | X24 .0565 Y28 .6555
G1 | X24 .2816 Y28 .7918
G1 | X24 .4862 Y28 .9301
G1 | X24 .6929 Y28 .7858
G1 | X24 .8913 Y28 .6413
G1 | X25 .0763 Y28 .7653
G1 | X25 .1317 Y28 .7952
G2 X25 .2884 Y28 .7127 I -0.0894 J -0.3603
G1 | X25 .4425 Y28 .6462
G1 | X25 .5163 Y28 .6923
G3 X25 .5146 Y29 .0511 I -0.4616 J0 .1772 G3 X25 .2426 Y29 .3851 I -0.6625 J -0.2617 G3 X25 .0033 Y29 .4747 I -0.3179 J -0.4848 G3 X24 .1743 Y29 .5311 I -0.829 J -6.063 G3 X23 .3503 Y29 .4654 I -0. J -5.2016
G3 X23 .0965 Y29 .3582 I0 .0915 J -0.5703 G3 X22 .8298 Y29 .0142 I0 .487 J -0.653 G3 X22 .8026 Y28 .6414 I0 .556 J -0.228
G1 | X22 .9024 Y28 .571
G1 | X23 .0087 Y28 .6619
G1 | X23 .0087 Y28 .6614
G4 P0
M280 P0 S20
G1 F6000

G1 X25 .2195 Y30 .0622
G4 P0
M280 P0 S120
G4 P0
G1 F6000 .000000
G2 X25 .5445 Y31 .37 I2 .7936 J -0.
G2 X26 .2565 Y32 .0198 I1 .2632 J -0.6692 G2 X26 .866 Y32 .1407 I0 .6031 J -1.4434 G2 X27 .2594 Y32 .0148 I -0.0028 J -0.686 G3 X27 .429 Y31 .9319 I0 .3485 J0 .4982 G1 X27 .4847 Y31 .9458
G3 X27 .5802 Y32 .1996 I -0.2328 J0 .2325 G3 X27 .417 Y32 .9898 I -2.9071 J -0.1884 G3 X27 .1284 Y33 .467 I -1.3123 J -0.468 G3 X26 .6679 Y33 .8012 I -1.066 J -0.9842 G3 X25 .5581 Y33 .8921 I -0.6798 J -1.4806 G3 X24 .5825 Y33 .2305 I0 .4816 J -1.7605
G1 | X24 .3155 Y32 .8766
G1 | X24 .1923 Y33 .1148
G3 X23 .4879 Y33 .8065 I -1.4056 J -0.7269 G3 X22 .3571 Y34 .0218 I -0.953 J -1.9282 G3 X21 .4695 Y33 .563 I0 .1075 J -1.2958 G3 X21 .0842 Y32 .5085 I1 .2563 J -1.0567 G3 X21 .2367 Y32 .0452 I0 .7769 J -0.001 G1 X21 .4562 Y32 .006
G2 X21 .9517 Y32 .1472 I0 .4741 J -0.7236 G2 X22 .5143 Y31 .9799 I -0.0278 J -1.1229 G2 X22 .9569 Y31 .4953 I -0.6309 J -1.0208 G2 X23 .3976 Y30 .2117 I -4.5911 J -2.2935 G3 X23 .5341 Y29 .7858 I1 .9606 J0 .3935
G1 | X23 .6114 Y29 .7358
G1 | X23 .7765 Y29 .9089
G3 X23 .5608 Y30 .8034 I -2.4418 J -0.1156 G2 X23 .5027 Y31 .1419 I0 .6178 J0 .2803
G1 | X23 .595 Y31 .1997
G1 | X23 .6761 Y31 .12
G2 X23 .8087 Y30 .6722 I -2.2338 J -0.9052 G3 X24 .0064 Y29 .8581 I8 .6926 J1 .6797
G1 | X24 .0593 Y29 .8185
G1 | X24 .1015 Y29 .8556
G3 X24 .1612 Y30 .6052 I -7.5658 J0 .9795 G2 X24 .2232 Y31 .341 I6 .8404 J -0.2064
G1 | X24 .2676 Y31 .3708
G1 | X24 .3228 Y31 .3073
G2 X24 .3851 Y30 .2944 I -10.6732 J -1.1644
G1 | X24 .5536 Y30 .1901
G1 | X24 .7217 Y30 .456
G2 X24 .8431 Y31 .0238 I1 .4169 J -0.006
G1 | X25 .0258 Y31 .1427
G1 | X25 .1104 Y31 .0544
G2 X25 .0099 Y30 .7751 I -0.498 J0 .0216 G3 X24 .7753 Y30 .1473 I0 .9351 J -0.7072 G3 X24 .9378 Y29 .7138 I0 .5583 J -0.0379 G1 X25 .0993 Y29 .7221
G3 X25 .2194 Y30 .0605 I -0.4168 J0 .3384 G1 X25 .2195 Y30 .0622
G4 P0
M280 P0 S20
G1 F6000
G1 X28 .7785 Y28 .6622
G4 P0
M280 P0 S120
G4 P0
G1 F6000 .000000
G1 | X28 .7785 Y36 .5257
G1 | X23 .1726 Y36 .5045
G1 | X17 .5667 Y36 .4833
G1 | X17 .5905 Y36 .1108
G3 X17 .7333 Y34 .8766 I12 .0865 J0 .7724 G3 X18 .0644 Y33 .2902 I20 .3222 J3 .4142 G3 X21 .4959 Y26 .329 I17 .8191 J4 .4574

G3 X27 .5557 Y21 .3311 I14 .7376 J11 .6964 G3 X28 .5769 Y20 .8241 I14 .1951 J27 .3082
G1 | X28 .675 Y20 .801
G1 | X28 .7271 Y20 .8519
G3 X28 .7785 Y28 .6624 I -593.2552 J7 .8105 G1 X28 .7785 Y28 .6622
G4 P0
M280 P0 S20
G1 F6000
G1 X34 .4894 Y28 .6617
G4 P0
M280 P0 S120
G4 P0
G1 F6000 .000000
G1 | X34 .5308 Y28 .7859 F6000 .000000
G1 | X34 .6136 Y28 .8273
G1 | X34 .7088 Y28 .7984
G1 | X34 .7377 Y28 .7445
G1 | X34 .7694 Y28 .6932
G1 | X34 .9032 Y28 .6617
G1 | X35 .0274 Y28 .703
G1 | X35 .0688 Y28 .7858
G1 | X35 .1102 Y28 .8686
G1 | X35 .2343 Y28 .91
G2 X35 .371 Y28 .8811 I -0. J -0.3383
G1 | X35 .3998 Y28 .8369
G1 | X35 .552 Y28 .6662
G1 | X35 .7644 Y28 .7949
G1 | X35 .989 Y28 .9454
G1 | X36 .1448 Y28 .7859
G1 | X36 .2659 Y28 .6563
G3 X36 .5401 Y28 .7592 I0 .024 J0 .353
G1 X36 .6391 Y28 .7899
G2 X36 .7974 Y28 .7117 I -0.0589 J -0.3185
G1 | X36 .9305 Y28 .6665
G1 | X37 .0089 Y28 .7288
G3 X36 .9583 Y29 .1041 I -0.4226 J0 .1341 G3 X36 .5457 Y29 .4434 I -0.7405 J -0.48 G3 X35 .6326 Y29 .6224 I -0.9294 J -2.3228 G3 X34 .7829 Y29 .4552 I -0.0142 J -2.171 G3 X34 .344 Y29 .0959 I0 .3819 J -0.9143 G3 X34 .2749 Y28 .704 I0 .404 J -0.2732
G1 | X34 .3983 Y28 .5869
G1 | X34 .4894 Y28 .662
G1 | X34 .4894 Y28 .6617
G4 P0
M280 P0 S20
G1 F6000
G1 X34 .7377 Y28 .1838
G4 P0
M280 P0 S120
G4 P0
G1 F6000 .000000
G1 | X34 .6869 Y28 .242 F6000 .000000
G1 | X34 .5721 Y28 .2064
G1 | X34 .6723 Y28 .1047
G1 | X34 .7377 Y28 .1838
G1 | X34 .7377 Y28 .1838
G4 P0
M280 P0 S20
G1 F6000
G1 X35 .2178 Y29 .994
G4 P0
M280 P0 S120
G4 P0
G1 F6000 .000000
G3 X35 .2104 Y30 .2038 I -0.6933 J0 .0806 G3 X35 .1089 Y30 .5726 I -2.279 J -0.4291 G2 X34 .9595 Y31 .1641 I2 .7578 J1 .0108
G1 | X35 .0144 Y31 .2275
G1 | X35 .1344 Y31 .1441

G2 X35 .3779 Y30 .2507 I -4.8196 J -1.7937 G1 X35 .4987 Y30 .2214
G3 X35 .6188 Y30 .5661 I -0.4653 J0 .3553 G2 X35 .7225 Y31 .3746 I3 .7322 J -0.0679
G1 | X35 .818 Y31 .3907
G1 | X35 .8614 Y31 .2624
G2 X35 .8473 Y31 .0366 I -0.7802 J -0.0647 G3 X35 .8244 Y30 .8031 I1 .053 J -0.2213 G3 X35 .8555 Y30 .3124 I4 .7363 J0 .0541
G1 | X36 .0149 Y30 .174
G1 | X36 .1734 Y30 .3204
G2 X36 .2506 Y30 .8132 I4 .834 J -0.5049 G2 X36 .3122 Y30 .9825 I0 .6214 J -0.1303
G1 | X36 .523 Y31 .1257
G1 | X36 .6413 Y31 .0202
G1 | X36 .6133 Y30 .924
G1 | X36 .5624 Y30 .8961
G1 | X36 .4191 Y30 .7891
G3 X36 .3107 Y30 .0451 I2 .5332 J -0.7493 G3 X36 .4323 Y29 .7563 I0 .4017 J -0.0008
G1 | X36 .6063 Y29 .7575
G1 | X36 .6326 Y29 .8054
G3 X36 .7302 Y30 .315 I -8.6054 J1 .9112 G2 X37 .6199 Y31 .889 I2 .569 J -0.4137 G2 X38 .7402 Y32 .0131 I0 .6526 J -0.7725
G1 | X38 .9768 Y31 .8897
G1 | X38 .9465 Y32 .49
G3 X38 .8574 Y33 .0697 I -2.8765 J -0.1452 G3 X38 .718 Y33 .3684 I -0.8806 J -0.229 G3 X37 .8466 Y33 .9426 I -1.177 J -0.8381 G3 X36 .7336 Y33 .7978 I -0.3535 J -1.6336 G3 X36 .0314 Y33 .288 I1 .2651 J -2.4809 G3 X35 .8963 Y32 .9624 I0 .325 J -0.3256
G1 | X35 .8725 Y32 .9064
G1 | X35 .8136 Y32 .8826
G1 | X35 .7598 Y32 .9116
G1 | X35 .7308 Y33 .0089
G3 X35 .5139 Y33 .4812 I -0.6228 J0 .
G3 X34 .632 Y33 .9533 I -1.5043 J -1.7502 G3 X33 .2124 Y33 .7047 I -0.4501 J -1.6075 G3 X32 .587 Y32 .4943 I0 .8664 J -1.2144 G3 X32 .73 Y32 .0432 I0 .7768 J -0.0019 G1 X32 .935 Y32 .0033
G2 X33 .5174 Y32 .1432 I0 .4928 J -0.769 G2 X34 .1057 Y31 .888 I -0.1026 J -1.0421 G2 X34 .5748 Y31 .2482 I -1.2124 J -1.3809 G2 X34 .8794 Y30 .1323 I -3.5745 J -1.5753 G3 X34 .9765 Y29 .7972 I1 .0599 J0 .1255
G1 | X35 .0599 Y29 .755
G1 | X35 .1532 Y29 .8168
G3 X35 .2177 Y29 .9937 I -0.3397 J0 .224 G1 X35 .2178 Y29 .994
G4 P0
M280 P0 S20
G1 F6000
G1 X35 .4566 Y26 .0227
G4 P0
M280 P0 S120
G4 P0
G1 F6000 .000000
G2 X35 .1959 Y26 .5167 I0 .2651 J0 .4557 G2 X35 .5271 Y26 .9927 I0 .5669 J -0.0412 G2 X36 .0573 Y26 .9564 I0 .2316 J -0.5081 G2 X36 .3103 Y26 .4969 I -0.2908 J -0.4595 G2 X36 .0279 Y26 .0171 I -0.5489 J0 .
G2 X35 .4566 Y26 .0227 I -0.2807 J0 .5053 G1 X35 .4566 Y26 .0227
G4 P0
M280 P0 S20
G1 F6000
G1 X35 .0603 Y25 .3718

G4 P0
M280 P0 S120
G4 P0
G1 F6000 .000000
G2 X34 .8171 Y25 .5918 I0 .6068 J0 .9152 G2 X34 .5806 Y25 .9584 I1 .5026 J1 .2291 G2 X34 .4508 Y26 .3668 I1 .2627 J0 .6262 G2 X34 .4628 Y26 .7116 I0 .902 J0 .1411 G3 X34 .4652 Y27 .0395 I -0.7406 J0 .1694 G3 X34 .3509 Y27 .2361 I -0.3573 J -0.0762 G2 X34 .2212 Y27 .436 I0 .2994 J0 .3363 G2 X34 .1563 Y27 .8484 I1 .3174 J0 .4186 G3 X34 .1332 Y28 .2867 I -4.5132 J -0.0186 G3 X34 .0782 Y28 .6176 I -2.6408 J -0.2687 G2 X34 .121 Y29 .2005 I0 .9602 J0 .2226 G2 X34 .4545 Y29 .5756 I0 .6764 J -0.2657 G1 X34 .5793 Y29 .7268
G3 X34 .6059 Y30 .0635 I -0.732 J0 .2272 G3 X34 .2194 Y31 .2856 I -3.9075 J -0.5637 G3 X33 .7421 Y31 .7667 I -0.9843 J -0.4992 G3 X33 .2981 Y31 .8436 I -0.3436 J -0.6643 G3 X32 .918 Y31 .6553 I0 .089 J -0.6575
G1 | X32 .6837 Y31 .421
G1 | X32 .4927 Y31 .8289
G2 X32 .3229 Y32 .9681 I1 .8233 J0 .854 G2 X32 .788 Y33 .8924 I1 .6085 J -0.2302 G2 X33 .4104 Y34 .264 I1 .0629 J -1.0732 G2 X34 .2845 Y34 .3486 I0 .6465 J -2.1206 G2 X34 .9233 Y34 .1708 I -0.2032 J -1.9656 G2 X35 .5082 Y33 .7722 I -0.9586 J -2.0352
G1 | X35 .7982 Y33 .4986
G1 | X36 .0335 Y33 .6949
G2 X37 .9885 Y34 .1934 I1 .4996 J -1.7983 G2 X39 .2035 Y33 .0665 I -0.3072 J -1.5496 G2 X39 .2681 Y32 .7559 I -2.329 J -0.647 G2 X39 .2874 Y32 .469 I -1.9671 J -0.2764 G2 X39 .2132 Y31 .7194 I -4.0118 J0 .0189 G2 X39 .0999 Y31 .5066 I -0.405 J0 .0791 G1 X39 .058 Y31 .4997
G2 X38 .75 Y31 .6788 I1 .137 J2 .3096
G3 X37 .7962 Y31 .6375 I -0.4492 J -0.6619 G3 X36 .9654 Y30 .2276 I1 .4825 J -1.8233 G3 X36 .9453 Y29 .683 I1 .9236 J -0.3437 G1 X37 .038 Y29 .5253
G2 X37 .2774 Y29 .146 I -0.3333 J -0.4756 G2 X37 .1927 Y28 .6049 I -0.8537 J -0.1435 G3 X37 .1164 Y28 .3645 I0 .6624 J -0.3425 G1 X37 .1427 Y28 .2431
G2 X37 .231 Y27 .8482 I -0.5068 J -0.3207 G2 X37 .0438 Y27 .4496 I -0.7051 J0 .0879 G3 X36 .9439 Y27 .2472 I0 .282 J -0.265 G3 X36 .9714 Y27 .0088 I0 .4321 J -0.0709 G2 X37 .0654 Y26 .3381 I -1.2475 J -0.5167 G2 X36 .8217 Y25 .703 I -1.3541 J0 .1554 G2 X36 .0049 Y25 .1808 I -1.0562 J0 .7521 G2 X35 .0603 Y25 .372 I -0.2367 J1 .2595 G1 X35 .0603 Y25 .3718
G4 P0
M280 P0 S20
G1 F6000
G1 X36 .3216 Y25 .5638
G4 P0
M280 P0 S120
G4 P0
G1 F6000 .000000
G3 X36 .7642 Y26 .0471 I -0.4364 J0 .844 G3 X36 .8088 Y26 .751 I -1.0182 J0 .4178 G3 X36 .5099 Y27 .2707 I -1.1305 J -0.3044 G3 X36 .0137 Y27 .5535 I -0.755 J -0.7481 G3 X34 .9785 Y27 .2621 I -0.2633 J -1.0492 G3 X34 .6921 Y26 .2074 I0 .7972 J -0.7827

G3 X34 .7813 Y26 .0061 I0 .6261 J0 .1571 G3 X35 .024 Y25 .7103 I1 .6197 J1 .0814 G3 X35 .33 Y25 .505 I0 .6736 J0 .6737
G3 X35 .6853 Y25 .4337 I0 .3553 J0 .8496 G3 X36 .0609 Y25 .4717 I -0. J1 .8761
G3 X36 .3216 Y25 .5638 I -0.2012 J0 .9848 G1 X36 .3216 Y25 .5638
G4 P0
M280 P0 S20
G1 F6000
G1 X39 .083 Y19 .5488
G4 P0
M280 P0 S120
G4 P0
G1 F6000 .000000
G3 X40 .0724 Y19 .7434 I -5.2796 J29 .459 G3 X40 .7176 Y19 .8993 I -2.6722 J12 .4742
G1 | X41 .3591 Y20 .072
G1 | X41 .3591 Y28 .2983
G1 | X41 .3591 Y36 .5246
G1 | X35 .7723 Y36 .5246
G1 | X30 .1855 Y36 .5246
G1 | X30 .1855 Y28 .3746
G1 | X30 .1855 Y20 .2247
G1 | X30 .8683 Y20 .021
G3 X33 .317 Y19 .5059 I4 .3357 J14 .5334 G3 X36 .2689 Y19 .3438 I2 .6344 J21 .0077 G3 X38 .0847 Y19 .4235 I -0.4736 J31 .5224 G3 X39 .083 Y19 .5488 I -0.7 J9 .6139
G1 X39 .083 Y19 .5488
G4 P0
M280 P0 S20
G1 F6000
G1 X41 .1106 Y16 .3707
G4 P0
M280 P0 S120
G4 P0
G1 F6000 .000000
G3 X42 .4151 Y16 .75 I -1.8449 J8 .7775
G1 | X42 .5178 Y16 .8981
G1 | X42 .5109 Y16 .949
G3 X42 .1671 Y18 .1708 I -112.6354 J -31.0317
G1 | X41 .8165 Y19 .3917
G1 | X41 .5576 Y19 .3917
G3 X41 .3132 Y19 .3492 I0 . J -0.7226
G3 X41 .0815 Y19 .2211 I0 .2807 J -0.7815
G1 | X40 .8644 Y19 .0502
G1 | X41 .0198 Y18 .745
G2 X41 .3643 Y17 .4773 I -2.8694 J -1.4606 G2 X41 .1174 Y17 .1177 I -0.3543 J -0.0213 G2 X40 .6754 Y17 .1286 I -0.2052 J0 .6468
G1 | X40 .5314 Y17 .3358
G1 | X40 .445 Y17 .4194
G3 X39 .8789 Y17 .3135 I0 .0652 J -1.9154 G3 X39 .6792 Y17 .188 I0 .1739 J -0.4981 G1 X39 .6519 Y17 .0859
G2 X39 .6866 Y16 .9498 I -5.0681 J -1.3608 G2 X39 .7441 Y16 .7023 I -17.1158 J -4.1077 G3 X40 .0541 Y16 .3869 I0 .4089 J0 .0919 G3 X41 .1106 Y16 .3707 I0 .564 J2 .3248
G1 X41 .1106 Y16 .3707
G4 P0
M280 P0 S20
G1 F6000
G1 X44 .7417 Y17 .6835
G4 P0
M280 P0 S120
G4 P0
G1 F6000 .000000
G3 X45 .7438 Y18 .1372 I -20.8767 J47 .4515 G1 X45 .7988 Y18 .1757

G3 X46 .1604 Y19 .813 I -1.1007 J1 .1017 G3 X44 .8681 Y20 .7159 I -1.2924 J -0.4733 G1 X44 .8397 Y20 .7109
G3 X44 .5035 Y20 .5819 I4 .5406 J -12.3389 G3 X44 .1849 Y20 .2441 I0 .205 J -0.5125
G3 X44 .2268 Y19 .7524 I0 .5913 J -0.1972 G2 X44 .4416 Y19 .35 I -123.9638 J -66.4416 G2 X44 .6112 Y19 .0296 I -79.0127 J -42.0196 G2 X44 .7756 Y18 .3933 I -1.2654 J -0.6663 G2 X44 .6307 Y18 .1004 I -0.3536 J -0.0074 G1 X44 .3765 Y18 .1233
G2 X43 .7162 Y19 .0642 I2 .8477 J2 .7009
G3 X43 .2543 Y19 .9597 I -39.8254 J -19.9724 G1 X43 .2354 Y19 .9711
G3 X42 .5704 Y19 .8358 I0 . J -1.701
G1 X42 .435 Y19 .6312
G3 X42 .9008 Y17 .7056 I4 .2131 J -0.
G3 X43 .6639 Y17 .2398 I0 .7631 J0 .3921 G1 X43 .7301 Y17 .2529
G3 X44 .7417 Y17 .6836 I -17.558 J42 .6399 G1 X44 .7417 Y17 .6835
G4 P0
M280 P0 S20
G1 F6000
G1 X47 .1321 Y18 .8349
G4 P0
M280 P0 S120
G4 P0
G1 F6000 .000000
G3 X47 .4656 Y19 .1689 I -0.3696 J0 .7027 G3 X47 .4861 Y19 .5101 I -0.3685 J0 .1932
G1 | X47 .4839 Y19 .6965
G1 | X47 .608 Y19 .8546
G2 X47 .8116 Y19 .9054 I0 .1748 J -0.2672 G2 X48 .0973 Y19 .8102 I -0.0591 J -0.6534
G1 | X48 .384 Y19 .6331
G1 | X48 .8064 Y19 .9366
G3 X49 .1825 Y20 .2551 I -1.8023 J2 .5096
G1 | X49 .1998 Y20 .3276
G1 | X49 .098 Y20 .4609
G3 X47 .1768 Y21 .6776 I -26.4105 J -39.5773
G1 | X46 .8284 Y21 .8868
G1 | X46 .2866 Y21 .5838
G3 X45 .7684 Y21 .2546 I2 .6801 J -4.792
G3 X45 .6248 Y21 .1095 I0 .3536 J -0.4935 G1 X45 .5817 Y20 .9385
G3 X45 .6723 Y20 .7031 I0 .5041 J0 .0589 G3 X45 .8663 Y20 .5192 I0 .5657 J0 .4025 G3 X46 .0431 Y20 .4679 I0 .1768 J0 .279 G1 X46 .2275 Y20 .3424
G2 X46 .4928 Y19 .327 I -4.0822 J -1.609 G3 X46 .6184 Y18 .597 I10 .5907 J1 .4463
G1 X46 .6476 Y18 .5826
G3 X46 .6972 Y18 .6077 I -1.0768 J2 .1896 G3 X47 .1321 Y18 .8351 I -55.0326 J105 .7454 G1 X47 .1321 Y18 .8349
G4 P0
M280 P0 S20
G1 F6000
G1 X50 .1405 Y20 .9698
G4 P0
M280 P0 S120
G4 P0
G1 F6000 .000000
G3 X50 .3608 Y21 .1587 I -0.9297 J1 .3071 G3 X50 .4714 Y21 .31 I -0.4812 J0 .4679 G1 X50 .4735 Y21 .4614
G3 X50 .2643 Y21 .7241 I -0.7244 J -0.3623 G2 X50 .0306 Y22 .097 I0 .4428 J0 .5371 G2 X50 .1038 Y22 .3852 I0 .3089 J0 .075 G2 X50 .3776 Y22 .5026 I0 .2648 J -0.2397

G2 X51 .0013 Y22 .3626 I -0.0414 J -1.6437 G3 X51 .3845 Y22 .2778 I0 .4024 J0 .9099 G3 X51 .6118 Y22 .3508 I0 .0071 J0 .3682 G1 X51 .7091 Y22 .6515
G3 X51 .4222 Y22 .9559 I -0.4568 J -0.1432 G2 X50 .9635 Y23 .2599 I0 .4426 J1 .166 G2 X50 .8312 Y23 .5739 I0 .3457 J0 .3306 G3 X50 .7747 Y23 .8439 I -0.8115 J -0.0287 G3 X50 .6403 Y24 .0557 I -0.6217 J -0.2459 G3 X50 .1054 Y24 .4075 I -1.0026 J -0.9418 G3 X49 .7582 Y24 .3746 I -0.1388 J -0.3839 G3 X49 .6662 Y24 .307 I0 .3093 J -0.5175 G3 X48 .8911 Y23 .6008 I33 .0338 J -37.0347
G1 | X48 .1225 Y22 .8855
G1 | X48 .9412 Y21 .8439
G3 X49 .7728 Y20 .8277 I26 .2793 J20 .6558
G1 | X49 .8299 Y20 .8003
G1 | X49 .8946 Y20 .8161
G3 X50 .1405 Y20 .9697 I -1.1437 J2 .1043 G1 X50 .1405 Y20 .9698
G4 P0
M280 P0 S20
G1 F6000
G1 X49 .3047 Y22 .9858
G4 P0
M280 P0 S120
G4 P0
G1 F6000 .000000
G2 X49 .4513 Y23 .3004 I0 .4108 J -0.
G2 X49 .8539 Y23 .4471 I0 .4026 J -0.4792 G1 X49 .9113 Y23 .3587
G2 X49 .6901 Y23 .0788 I -0.6576 J0 .2925 G2 X49 .3762 Y22 .9294 I -0.5121 J0 .6714
G1 | X49 .3047 Y22 .9857
G1 | X49 .3047 Y22 .9858
G4 P0
M280 P0 S20
G1 F6000
G1 X51 .8746 Y24 .4839
G4 P0
M280 P0 S120
G4 P0
G1 F6000 .000000
G3 X52 .0669 Y24 .6962 I -0.1883 J0 .3637 G3 X52 .0686 Y24 .9716 I -0.3515 J0 .1398 G1 X51 .9071 Y25 .083
G3 X51 .5578 Y24 .9736 I -0.0023 J -0.6048 G3 X51 .3919 Y24 .7095 I0 .2306 J -0.3291
G1 | X51 .4732 Y24 .4569
G1 | X51 .6031 Y24 .4081
G3 X51 .8746 Y24 .4837 I -0.0458 J0 .6894 G1 X51 .8746 Y24 .4839
G4 P0
M280 P0 S20
G1 F6000
G1 X51 .5874 Y25 .5371
G4 P0
M280 P0 S120
G4 P0
G1 F6000 .000000
G2 X52 .0682 Y26 .1368 I451 .3219 J -361.3365 G2 X52 .3496 Y26 .4864 I144 .2567 J -115.8096
G1 | X52 .6313 Y26 .8358
G1 | X52 .3412 Y26 .9742
G3 X52 .0496 Y27 .0747 I -0.5864 J -1.2279 G1 X51 .9296 Y27 .0659
G3 X50 .9058 Y26 .2874 I0 .8251 J -2.1476 G3 X50 .5462 Y25 .1976 I1 .4716 J -1.0898 G1 X50 .6327 Y25 .0519
G3 X51 .0128 Y24 .9427 I0 .4339 J0 .794 G1 X51 .091 Y24 .9716

G3 X51 .5874 Y25 .5371 I -5.998 J5 .7649 G1 X51 .5874 Y25 .5371
G4 P0
M280 P0 S20
G1 F6000
G1 X53 .4364 Y24 .6187
G4 P0
M280 P0 S120
G4 P0
G1 F6000 .000000
G1 | X54 .2 Y25 .7075
G1 | X53 .9664 Y25 .8986
G3 X53 .7278 Y26 .077 I -2.1738 J -2.6579 G1 X53 .6817 Y26 .0927
G3 X53 .2225 Y25 .8702 I -0.0241 J -0.5355 G3 X52 .1351 Y23 .9351 I8 .098 J -5.8237 G1 X52 .1905 Y23 .6802
G3 X52 .577 Y23 .5299 I0 .3864 J0 .4216
G1 X52 .6536 Y23 .5671
G3 X53 .4364 Y24 .6187 I -18.1843 J14 .3537 G1 X53 .4364 Y24 .6187
G4 P0
M280 P0 S20
G1 F6000
G1 X55 .4663 Y28 .0731
G4 P0
M280 P0 S120
G4 P0
G1 F6000 .000000
G3 X56 .0523 Y29 .4497 I -10.8454 J5 .4298 G1 X56 .0116 Y29 .611
G3 X55 .6666 Y29 .6737 I -0.223 J -0.2464 G3 X55 .2833 Y29 .3238 I0 .2673 J -0.6777 G2 X55 .0813 Y28 .9678 I -3.6909 J1 .8593
G1 | X55 .0332 Y28 .9301
G1 | X54 .9867 Y28 .9472
G2 X54 .5809 Y29 .6937 I9 .9282 J5 .8796 G3 X54 .1437 Y30 .4198 I -4.6919 J -2.3307 G1 X53 .9787 Y30 .5319
G3 X53 .7727 Y30 .5674 I -0.3394 J -1.3526
G1 | X53 .743 Y30 .5545
G1 | X53 .7235 Y30 .5211
G3 X53 .1615 Y29 .213 I196 .8456 J -85.3516 G3 X52 .707 Y27 .9298 I10 .0949 J -4.2978
G1 | X52 .7543 Y27 .7879
G1 | X53 .0583 Y27 .755
G3 X53 .4809 Y28 .1236 I -0.4188 J0 .9067 G1 X53 .8969 Y28 .2241
G2 X54 .2655 Y27 .6666 I -0.3795 J -0.6515 G3 X54 .4992 Y26 .7989 I3 .2376 J0 .4065
G1 | X54 .686 Y26 .6752
G1 | X54 .745 Y26 .7098
G3 X55 .4663 Y28 .0731 I -29.9657 J16 .7266 G1 X55 .4663 Y28 .0731
G4 P0
M280 P0 S20
G1 F6000
G1 X48 .0729 Y25 .7551
G4 P0
M280 P0 S120
G4 P0
G1 F6000 .000000
G3 X48 .3202 Y26 .107 I -0.8836 J0 .8836 G3 X48 .394 Y26 .4379 I -0.7023 J0 .3302 G3 X48 .2304 Y27 .0632 I -1.2818 J -0.0012 G3 X47 .8227 Y27 .4575 I -0.8612 J -0.4825 G3 X46 .7712 Y27 .4071 I -0.4822 J -0.9325 G3 X46 .2426 Y26 .4379 I0 .6261 J -0.9702 G3 X46 .3164 Y26 .107 I0 .7762 J -0.0006 G3 X46 .5637 Y25 .7551 I1 .1308 J0 .5316 G3 X46 .9188 Y25 .5153 I0 .7964 J0 .7964

G3 X47 .3183 Y25 .4337 I0 .3995 J0 .9382 G3 X47 .7178 Y25 .5153 I0 . J1 .0198
G3 X48 .0729 Y25 .7551 I -0.4412 J1 .036 G1 X48 .0729 Y25 .7551
G4 P0
M280 P0 S20
G1 F6000
G1 X46 .9105 Y26 .1484
G4 P0
M280 P0 S120
G4 P0
G1 F6000 .000000
G2 X46 .7788 Y26 .5127 I0 .4844 J0 .3811 G2 X46 .8915 Y26 .8454 I0 .5067 J0 .0138 G2 X47 .5231 Y27 .0304 I0 .4496 J -0.364 G2 X47 .8976 Y26 .5117 I -0.172 J -0.5187 G2 X47 .7276 Y26 .1003 I -0.5828 J -0. G2 X47 .3182 Y25 .9303 I -0.4094 J0 .4079 G2 X47 .1076 Y25 .9831 I0 . J0 .4466
G2 X46 .9104 Y26 .1484 I0 .2959 J0 .5532 G1 X46 .9105 Y26 .1484
G4 P0
M280 P0 S20
G1 F6000
G1 X46 .6553 Y25 .3717
G4 P0
M280 P0 S120
G4 P0
G1 F6000 .000000
G2 X46 .2008 Y25 .8802 I0 .7947 J1 .1677 G2 X46 .0328 Y26 .5514 I1 .2857 J0 .6784 G3 X45 .9735 Y27 .0555 I -2.2768 J -0.0124 G3 X45 .8684 Y27 .2563 I -0.4402 J -0.1025 G2 X45 .7601 Y27 .4563 I0 .3558 J0 .3218 G2 X45 .6985 Y27 .9035 I1 .8276 J0 .4797 G3 X45 .6732 Y28 .37 I -6.2205 J -0.1038 G3 X45 .628 Y28 .6723 I -2.685 J -0.2472 G2 X45 .6801 Y29 .2198 I0 .9109 J0 .1895 G2 X46 .0057 Y29 .5784 I0 .6662 J -0.2777 G1 X46 .1056 Y29 .7125
G3 X46 .1284 Y30 .1809 I -1.5151 J0 .3084 G3 X46 .0331 Y30 .6773 I -2.9292 J -0.305 G3 X45 .8597 Y31 .131 I -2.615 J -0.7395 G3 X45 .0223 Y31 .8163 I -1.165 J -0.5693 G3 X44 .3581 Y31 .5231 I -0.1475 J -0.5648 G1 X44 .2751 Y31 .5044
G2 X44 .0904 Y31 .724 I0 .3819 J0 .5088 G2 X43 .9468 Y32 .096 I1 .7187 J0 .8767 G2 X43 .8676 Y32 .5457 I2 .4418 J0 .6618 G2 X43 .8959 Y32 .9936 I1 .5272 J0 .1285 G2 X44 .0631 Y33 .4622 I1 .8375 J -0.3915 G2 X44 .6087 Y34 .0552 I1 .35 J -0.6946 G2 X45 .4833 Y34 .3493 I1 .0542 J -1.6877 G2 X46 .3354 Y34 .2337 I0 .1738 J -1.9166 G2 X47 .0703 Y33 .7515 I -0.7083 J -1.8807
G1 | X47 .3408 Y33 .4725
G1 | X47 .6399 Y33 .7119
G2 X48 .3222 Y34 .0922 I1 .4724 J -1.8394 G2 X49 .0618 Y34 .218 I0 .7291 J -2.0482 G2 X50 .0489 Y33 .9609 I -0.0132 J -2.074 G2 X50 .6472 Y33 .3436 I -0.7065 J -1.2832 G2 X50 .7512 Y33 .0047 I -0.9123 J -0.4656 G2 X50 .7785 Y32 .2905 I -4.1311 J -0.5153 G2 X50 .7219 Y31 .5726 I -11.633 J0 .5567
G1 | X50 .6928 Y31 .512
G1 | X50 .638 Y31 .5019
G2 X50 .3265 Y31 .6752 I0 .8252 J1 .8488 G3 X49 .7206 Y31 .8397 I -0.5416 J -0.797 G3 X49 .1459 Y31 .5962 I0 .0636 J -0.9503 G3 X48 .7625 Y31 .0579 I1 .0279 J -1.1377 G3 X48 .505 Y30 .0874 I3 .2579 J -1.3837

G3 X48 .5232 Y29 .6736 I1 .2835 J -0.1509 G3 X48 .6307 Y29 .4827 I0 .3538 J0 .0735 G2 X48 .8785 Y28 .972 I -0.5366 J -0.5758 G2 X48 .711 Y28 .515 I -0.5766 J -0.0478 G1 X48 .6668 Y28 .4084
G3 X48 .711 Y28 .2049 I0 .4909 J -0.
G2 X48 .7714 Y27 .8051 I -0.6712 J -0.3058 G2 X48 .6143 Y27 .4525 I -0.6665 J0 .0856 G3 X48 .5055 Y27 .2167 I0 .3588 J -0.3087 G3 X48 .5415 Y26 .985 I0 .3813 J -0.0594 G2 X48 .6512 Y26 .3812 I -0.9837 J -0.4907 G2 X48 .4164 Y25 .7761 I -1.2226 J0 .1265 G2 X47 .9046 Y25 .3332 I -1.2465 J0 .9231 G2 X47 .3183 Y25 .1855 I -0.5864 J1 .0903 G2 X46 .9448 Y25 .2369 I -0. J1 .3826
G2 X46 .6553 Y25 .3718 I0 .2668 J0 .951 G1 X46 .6553 Y25 .3717
G4 P0
M280 P0 S20
G1 F6000
G1 X46 .0457 Y28 .6234
G4 P0
M280 P0 S120
G4 P0
G1 F6000 .000000
G1 | X46 .0506 Y28 .7268 F6000 .000000
G1 | X46 .1353 Y28 .8037
G1 | X46 .2521 Y28 .81
G1 | X46 .3063 Y28 .7594
G1 | X46 .4232 Y28 .6866
G1 | X46 .6158 Y28 .8014
G1 | X46 .7372 Y28 .864
G2 X46 .9967 Y28 .8064 I0 .0075 J -0.58 G3 X47 .2533 Y28 .7415 I0 .2854 J0 .5887
G1 | X47 .3424 Y28 .7912
G1 | X47 .5873 Y28 .9328
G1 | X47 .7322 Y28 .7862
G1 | X47 .8534 Y28 .6571
G3 X48 .1291 Y28 .7612 I0 .0226 J0 .3572
G1 | X48 .2225 Y28 .7855
G1 | X48 .3467 Y28 .6991
G1 | X48 .4521 Y28 .637
G1 | X48 .5191 Y28 .6768
G3 X48 .5259 Y29 .0277 I -0.4765 J0 .1848 G3 X48 .2853 Y29 .357 I -0.6523 J -0.2241 G3 X46 .8408 Y29 .7689 I -1.2664 J -1.7023 G3 X45 .9103 Y29 .157 I0 .0979 J -1.1623 G3 X45 .802 Y28 .762 I0 .8138 J -0.4356
G1 | X45 .8837 Y28 .5518
G1 | X46 .0064 Y28 .529
G1 | X46 .0457 Y28 .6238
G1 | X46 .0457 Y28 .6234
G4 P0
M280 P0 S20
G1 F6000
G1 X46 .7384 Y30 .1308
G4 P0
M280 P0 S120
G4 P0
G1 F6000 .000000
G3 X46 .7007 Y30 .5147 I -1.9972 J -0.0023 G3 X46 .6143 Y30 .761 I -0.8979 J -0.177 G2 X46 .4995 Y31 .1495 I0 .9337 J0 .4869
G1 | X46 .5705 Y31 .2274
G1 | X46 .6896 Y31 .1469
G2 X46 .9145 Y30 .3705 I -3.7661 J -1.5118 G1 X47 .0621 Y30 .3109
G3 X47 .1979 Y30 .5733 I -0.1891 J0 .2642 G2 X47 .2553 Y31 .4229 I6 .9032 J -0.0391
G1 | X47 .3153 Y31 .4757
G1 | X47 .3583 Y31 .4379

G2 X47 .4188 Y30 .6697 I -7.7805 J -0.9988 G3 X47 .5053 Y29 .9172 I4 .4585 J0 .1311
G1 | X47 .5873 Y29 .836
G1 | X47 .6715 Y29 .8816
G3 X47 .7322 Y30 .1894 I -0.7511 J0 .3079 G2 X47 .882 Y30 .9948 I2 .239 J -0.
G1 | X48 .1004 Y31 .1446
G1 | X48 .1687 Y31 .0734
G1 | X48 .089 Y30 .8791
G3 X47 .9942 Y30 .7056 I0 .3131 J -0.2839 G3 X47 .9136 Y30 .2311 I2 .4216 J -0.6555 G3 X47 .9503 Y29 .805 I1 .3543 J -0.0979
G1 | X48 .0365 Y29 .7376
G1 | X48 .139 Y29 .8043
G3 X48 .2952 Y30 .3211 I -2.0013 J0 .887 G2 X48 .5785 Y31 .2114 I3 .3401 J -0.5727 G2 X49 .0008 Y31 .7955 I1 .8194 J -0.8707 G2 X49 .6757 Y32 .1409 I0 .9117 J -0.9493 G2 X50 .2521 Y32 .0243 I0 .1424 J -0.7789 G3 X50 .4608 Y31 .8999 I1 .5605 J2 .3813
G1 | X50 .502 Y31 .8895
G1 | X50 .5252 Y31 .9106
G3 X50 .5463 Y32 .36 I -4.7758 J0 .4494 G3 X50 .3626 Y33 .1834 I -1.9372 J0 .
G3 X49 .9122 Y33 .7103 I -1.1838 J -0.5559 G3 X49 .5867 Y33 .8522 I -0.5432 J -0.8016 G3 X49 .0155 Y33 .9173 I -0.5712 J -2.476 G3 X48 .2398 Y33 .7325 I -0. J -1.7205
G3 X47 .6159 Y33 .2105 I0 .8076 J -1.5989
G1 | X47 .3778 Y32 .894
G1 | X47 .1719 Y33 .1974
G3 X46 .9534 Y33 .4892 I -3.2443 J -2.2014 G3 X46 .8318 Y33 .6101 I -0.6697 J -0.5518 G3 X45 .7432 Y34 .0732 I -1.3453 J -1.6512 G3 X44 .8289 Y33 .8533 I -0.1622 J -1.3362 G3 X44 .2364 Y33 .1259 I0 .9039 J -1.3412 G3 X44 .1388 Y32 .1712 I1 .5662 J -0.6426
G1 | X44 .2902 Y31 .9924
G1 | X44 .5467 Y32 .022
G2 X45 .0611 Y32 .169 I0 .4933 J -0.7527 G2 X45 .5701 Y31 .9982 I -0.0212 J -0.9072 G2 X46 .0258 Y31 .4582 I -0.85 J -1.1794 G2 X46 .4238 Y30 .2552 I -4.2006 J -2.0573
G1 | X46 .6025 Y30 .0383
G1 | X46 .7385 Y30 .131
G1 | X46 .7384 Y30 .1308
G4 P0
M280 P0 S20
G1 F6000
G1 X50 .629 Y37 .3997
G4 P0
M280 P0 S120
G4 P0
G1 F6000 .000000
G3 X53 .401 Y37 .4703 I -5.3122 J263 .0207 G3 X54 .1159 Y37 .5074 I -0.5241 J17 .0484
G1 | X54 .8301 Y37 .5589
G1 | X52 .7322 Y44 .5527
G3 X50 .1661 Y52 .7894 I -389.8638 J -116.9419 G1 X50 .0494 Y52 .8533
G3 X49 .9057 Y52 .7934 I0 .1421 J -0.5428
G1 | X49 .8841 Y52 .7554
G1 | X49 .8915 Y52 .7019
G3 X51 .9075 Y45 .5458 I3619 .0709 J1015 .7328 G2 X53 .869 Y38 .4148 I -495.4468 J -140.1102 G1 X53 .8361 Y38 .332
G2 X53 .6 Y38 .2435 I -0.3444 J0 .5597
G2 X51 .8705 Y38 .0041 I -5.135 J30 .7292
G2 X50 .9998 Y37 .9493 I -1.0191 J9 .2404 G2 X49 .1599 Y37 .9606 I -0.6637 J41 .5917 G1 X47 .3183 Y38 .0128

G1 X47 .3183 Y37 .696
G3 X47 .4329 Y37 .3792 I0 .4951 J0 .
G1 X47 .6454 Y37 .303
G2 X47 .858 Y37 .3265 I0 .2571 J -1.3553 G2 X50 .629 Y37 .3992 I7 .4593 J -231.3066 G1 X50 .629 Y37 .3997
G4 P0
M280 P0 S20
G1 F6000
G1 X49 .2802 Y38 .9326
G4 P0
M280 P0 S120
G4 P0
G1 F6000 .000000
G3 X50 .0641 Y39 .1214 I -3.6806 J17 .0042 G3 X50 .6983 Y39 .3089 I -3.0318 J11 .4192 G3 X52 .6104 Y40 .0241 I -7.4841 J22 .925
G1 X52 .699 Y40 .1554
G3 X52 .684 Y40 .288 I -0.5188 J0 .0084
G3 X51 .1049 Y46 .6581 I -2399.5032 J -591.4308 G3 X49 .5057 Y53 .0369 I -2395.8097 J -597.2738
G1 | X49 .4715 Y53 .1019
G1 | X49 .4099 Y53 .1184
G3 X49 .23 Y53 .0183 I0 .1872 J -0.5486
G1 | X49 .0461 Y52 .8693
G1 | X50 .5854 Y46 .7138
G2 X52 .1003 Y40 .565 I -884.3274 J -221.1428 G1 X52 .0882 Y40 .5218
G2 X51 .6838 Y40 .2588 I -0.8226 J0 .8223
G2 X49 .651 Y39 .5826 I -8.2546 J21 .42
G2 X47 .8948 Y39 .1479 I -7.6836 J27 .2836 G2 X47 .3489 Y39 .0902 I -0.5459 J2 .5529 G1 X47 .3326 Y39 .0761
G3 X47 .3183 Y38 .8714 I1 .4601 J -0.2047
G1 | X47 .3183 Y38 .6526
G1 | X47 .9049 Y38 .7071
G3 X48 .4883 Y38 .7819 I -0.775 J8 .3622 G3 X49 .2802 Y38 .9325 I -2.5568 J15 .5984 G1 X49 .2802 Y38 .9326
G4 P0
M280 P0 S20
G1 F6000
G1 X49 .1806 Y39 .6673
G4 P0
M280 P0 S120
G4 P0
G1 F6000 .000000
G3 X50 .7804 Y40 .1685 I -4.915 J18 .4945 G3 X51 .7129 Y40 .5842 I -2.4156 J6 .6718 G3 X51 .8333 Y40 .691 I -0.1638 J0 .3061
G1 X51 .8715 Y40 .8105
G3 X51 .8553 Y40 .9503 I -0.5727 J0 .0043 G3 X50 .289 Y47 .309 I -1206.3148 J -293.755 G3 X48 .6556 Y53 .5873 I -302.996 J -75.4783
G1 | X48 .5716 Y53 .6397
G1 | X48 .4667 Y53 .5851
G1 | X48 .4124 Y53 .4833
G1 | X48 .4154 Y53 .3532
G3 X49 .8806 Y47 .381 I669 .8897 J161 .1819
G2 X51 .3689 Y41 .4089 I -3682.3443 J -920.8613
G1 | X51 .3739 Y41 .368
G1 | X51 .2949 Y41 .2486
G2 X49 .4289 Y40 .5422 I -9.8638 J23 .2373
G2 X46 .2399 Y39 .8979 I -4.2006 J12 .5758 G2 X42 .2732 Y39 .9946 I -1.5049 J19 .6658 G3 X41 .661 Y40 .0494 I -1.0651 J -8.4454
G1 | X41 .5904 Y40 .0316
G1 | X41 .5496 Y39 .977
G3 X41 .5246 Y39 .7889 I0 .6946 J -0.1881
G1 | X41 .5246 Y39 .5869
G1 | X44 .4215 Y39 .5869

G2 X47 .2525 Y39 .5203 I0 . J -60.2312
G1 | X47 .3183 Y39 .4513
G1 | X47 .3771 Y39 .3818
G3 X47 .7942 Y39 .3709 I0 .2466 J1 .4599 G3 X48 .2658 Y39 .4483 I -0.5666 J4 .9272 G3 X49 .1806 Y39 .6677 I -4.0175 J18 .7668 G1 X49 .1806 Y39 .6673
G4 P0
M280 P0 S20
G1 F6000
G1 X46 .9872 Y38 .3866
G4 P0
M280 P0 S120
G4 P0
G1 F6000 .000000
G1 | X46 .9872 Y39 .3384
G1 | X36 .1447 Y39 .3384
G1 | X25 .3022 Y39 .3384
G1 | X25 .3022 Y38 .3866
G1 | X25 .3022 Y37 .4348
G1 | X36 .1447 Y37 .4348
G1 | X46 .9872 Y37 .4348
G1 | X46 .9872 Y38 .3866
G4 P0
M280 P0 S20
G1 F6000
G1 X45 .2451 Y40 .5826
G4 P0
M280 P0 S120
G4 P0
G1 F6000 .000000
G3 X47 .0607 Y40 .8464 I -1.4421 J16 .3042 G3 X48 .6982 Y41 .2838 I -2.7829 J13 .7025 G3 X50 .4531 Y41 .9668 I -6.0192 J18 .0623 G1 X50 .5462 Y42 .1105
G3 X50 .0393 Y46 .2597 I -17.2343 J -0.
G3 X47 .3609 Y54 .9631 I -79.7958 J -19.7933 G1 X47 .2944 Y54 .9997
G3 X46 .9269 Y54 .871 I0 .318 J -1.4971
G2 X46 .524 Y54 .6973 I -1.7129 J3 .4189
G2 X46 .2372 Y54 .6196 I -0.599 J1 .6428 G2 X45 .5438 Y54 .6226 I -0.3388 J1 .868 G2 X43 .53 Y55 .1345 I3 .184 J16 .7438 G1 X43 .1889 Y54 .7895
G3 X43 .511 Y54 .2581 I1 .5569 J0 .5804 G1 X43 .4789 Y54 .1969
G2 X43 .3148 Y54 .1226 I -0.288 J0 .4176 G1 X43 .2583 Y53 .7297
G3 X43 .7137 Y53 .4918 I0 .4554 J0 .3168
G1 | X44 .7525 Y53 .4918
G1 | X44 .7525 Y50 .8018
G1 | X44 .7525 Y48 .1119
G1 | X44 .0904 Y48 .1119
G1 | X43 .4283 Y48 .1119
G1 | X43 .4283 Y46 .3324
G1 | X43 .4283 Y44 .5529
G1 | X42 .4749 Y44 .5529
G1 | X41 .5215 Y44 .5529
G1 | X41 .5438 Y42 .6751
G1 | X41 .566 Y40 .7974
G1 | X41 .8164 Y40 .7326
G3 X42 .3246 Y40 .6424 I0 .8304 J3 .2024 G3 X44 .0904 Y40 .5096 I3 .8353 J39 .1906 G3 X44 .2971 Y40 .5107 I0 .0938 J1 .7791 G3 X45 .2451 Y40 .5829 I -2.394 J37 .6983 G1 X45 .2451 Y40 .5826
G4 P0
M280 P0 S20
G1 F6000
G1 X45 .9941 Y41 .8885
G4 P0

M280 P0 S120
G4 P0
G1 F6000 .000000
G1 X45 .9785 Y41 .9513 F6000 .000000
G3 X45 .7133 Y42 .4216 I -8.3397 J -4.3925 G2 X45 .4697 Y42 .8833 I3 .9676 J2 .389 G1 X45 .4788 Y42 .9341
G2 X45 .7982 Y43 .0522 I0 .2879 J -0.2877 G1 X45 .8737 Y42 .9035
G3 X45 .8509 Y42 .5613 I0 .3114 J -0.1926
G1 | X46 .0988 Y42 .4007
G1 | X46 .1388 Y42 .4354
G3 X46 .1455 Y42 .7302 I -1.2405 J0 .1759
G1 | X46 .1141 Y43 .0598
G1 | X46 .7178 Y43 .194
G2 X47 .7428 Y43 .3045 I1 .0056 J -4.5195
G1 | X47 .8835 Y43 .189
G1 | X47 .8545 Y43 .1299
G1 | X47 .7811 Y43 .1385
G3 X47 .6468 Y43 .2199 I -0.3395 J -0.4087 G1 X47 .6059 Y43 .2119
G3 X47 .4824 Y42 .7799 I0 .3263 J -0.327 G3 X47 .815 Y42 .3173 I0 .7228 J0 .1688 G1 X47 .8169 Y42 .2461
G2 X47 .5252 Y42 .116 I -0.4883 J0 .7027 G2 X47 .3789 Y42 .1147 I -0.076 J0 .3203
G1 | X47 .3683 Y42 .1503
G1 | X47 .4137 Y42 .2578
G3 X47 .3817 Y42 .6735 I -2.0395 J0 .0523 G3 X47 .2223 Y43 .0276 I -0.7919 J -0.1435
G1 | X47 .1047 Y43 .0255
G1 | X47 .0232 Y42 .9748
G1 | X46 .9873 Y43 .005
G1 | X46 .9573 Y43 .1148
G1 | X46 .9045 Y43 .1449
G1 | X46 .8528 Y43 .0926
G3 X46 .9113 Y42 .5696 I2 .6444 J0 .0313 G3 X47 .0294 Y42 .1869 I2 .2278 J0 .4778
G1 | X47 .0818 Y42 .1517
G1 | X47 .1198 Y42 .1279
G1 | X47 .1173 Y42 .0783
G2 X46 .7561 Y41 .8418 I -0.4334 J0 .2678
G1 | X46 .5734 Y42 .0002
G1 | X46 .5939 Y42 .0481
G1 | X46 .6449 Y42 .0685
G1 | X46 .8455 Y42 .3044
G3 X46 .4919 Y43 .0086 I -1.2988 J -0.2114 G1 X46 .383 Y42 .9872
G3 X46 .2054 Y42 .2961 I2 .5362 J -1.0202 G2 X46 .1168 Y41 .855 I -2.8891 J0 .3505
G1 | X46 .0708 Y41 .8202
G1 | X46 .015 Y41 .8412
G1 | X45 .994 Y41 .8873
G1 | X45 .9941 Y41 .8885
G4 P0
M280 P0 S20
G1 F6000
G1 X48 .1711 Y42 .7527
G4 P0
M280 P0 S120
G4 P0
G1 F6000 .000000
G2 X48 .4083 Y43 .1589 I0 .6211 J -0.0902 G1 X48 .6375 Y43 .1133
G3 X49 .049 Y42 .5777 I2 .1719 J1 .2426 G1 X49 .1783 Y42 .578
G3 X49 .2697 Y42 .8926 I -0.2394 J0 .2402 G3 X48 .9648 Y43 .5259 I -1.5212 J -0.3424 G1 X48 .9751 Y43 .6436
G2 X49 .1918 Y43 .7252 I0 .2167 J -0.2468 G1 X49 .3156 Y43 .6793

G1 X49 .335 Y43 .6021
G3 X49 .2779 Y42 .8576 I1 .2208 J -0.4682
G1 | X49 .5406 Y42 .6506
G1 | X49 .6841 Y42 .7098
G3 X49 .8426 Y42 .939 I -0.4802 J0 .5017
G1 | X49 .8971 Y42 .9655
G1 | X49 .9467 Y42 .9113
G2 X49 .9595 Y42 .7245 I -0.8929 J -0.1547
G1 | X49 .9385 Y42 .6761
G1 | X49 .8893 Y42 .6476
G2 X49 .2254 Y42 .4846 I -4.1408 J15 .4272 G2 X48 .6526 Y42 .4253 I -0.5406 J2 .4251
G1 | X48 .604 Y42 .4926
G1 | X48 .5833 Y42 .5981
G1 | X48 .4731 Y42 .6498
G1 | X48 .3595 Y42 .5979
G1 | X48 .3343 Y42 .4896
G1 | X48 .2942 Y42 .318
G1 | X48 .1144 Y42 .2359
G1 | X48 .1064 Y42 .2448
G2 X48 .1713 Y42 .7532 I14 .7248 J -1.622 G1 X48 .1711 Y42 .7527
G4 P0
M280 P0 S20
G1 F6000
G1 X48 .4322 Y42 .8091
G4 P0
M280 P0 S120
G4 P0
G1 F6000 .000000
G1 | X48 .4417 Y42 .8772 F6000 .000000
G1 | X48 .3957 Y42 .9382
G1 | X48 .3433 Y42 .9333
G1 | X48 .3115 Y42 .8611
G1 | X48 .3606 Y42 .7866
G1 | X48 .4322 Y42 .8091
G1 | X48 .4322 Y42 .8091
G4 P0
M280 P0 S20
G1 F6000
G1 X47 .1359 Y44 .7808
G4 P0
M280 P0 S120
G4 P0
G1 F6000 .000000
G2 X46 .9429 Y45 .4588 I0 .6314 J0 .5462 G2 X47 .3059 Y45 .8447 I0 .4657 J -0.0744 G3 X47 .5248 Y45 .8956 I -2.9228 J13 .0597 G3 X47 .8149 Y45 .9678 I -5.0506 J20 .9128 G2 X48 .1515 Y45 .9978 I0 .2601 J -1.0151 G1 X48 .2011 Y45 .9394
G3 X48 .2614 Y45 .1019 I2 .6011 J -0.2337
G1 | X48 .4322 Y44 .9669
G1 | X48 .5483 Y45 .0612
G3 X48 .6426 Y45 .9716 I -4.3476 J0 .9105 G2 X48 .6698 Y46 .1799 I0 .8116 J0 .
G1 X48 .7047 Y46 .2055
G2 X49 .6726 Y45 .6034 I -0.0591 J -1.1741 G2 X49 .3472 Y45 .0497 I -0.3254 J -0.1812 G3 X49 .2376 Y45 .0384 I0 . J -0.5383
G3 X49 .1037 Y44 .9992 I0 .1779 J -0.8557
G1 | X49 .0369 Y45 .0135
G1 | X49 .0227 Y45 .0811
G1 | X48 .939 Y45 .278
G1 | X48 .7214 Y45 .2086
G1 | X48 .6979 Y45 .1063
G1 | X48 .7387 Y45 .0414
G1 | X48 .7352 Y44 .9668
G2 X48 .3229 Y44 .8348 I -0.6389 J1 .2861 G2 X48 .0621 Y44 .8484 I -0.0986 J0 .6166 G1 X48 .0289 Y44 .9137

G3 X48 .0811 Y45 .659 I -1.194 J0 .4581
G1 | X47 .8068 Y45 .8773
G1 | X47 .762 Y45 .8475
G3 X47 .7322 Y45 .6988 I0 .3562 J -0.1486
G1 | X47 .6811 Y45 .636
G1 | X47 .5719 Y45 .6656
G3 X47 .4074 Y45 .7648 I -0.3375 J -0.374 G1 X47 .3236 Y45 .7562
G3 X47 .1642 Y45 .4443 I0 .1778 J -0.2876 G3 X47 .3868 Y44 .8812 I1 .0079 J0 .0728
G1 | X47 .5379 Y44 .6946
G1 | X47 .7178 Y44 .8877
G1 | X47 .7976 Y44 .8896
G1 | X47 .8121 Y44 .7957
G2 X47 .5142 Y44 .6126 I -0.3057 J0 .1636 G2 X47 .136 Y44 .7805 I -0.011 J0 .4855 G1 X47 .1359 Y44 .7808
G4 P0
M280 P0 S20
G1 F6000
G1 X48 .846 Y45 .4579
G4 P0
M280 P0 S120
G4 P0
G1 F6000 .000000
G1 | X48 .8555 Y45 .5261 F6000 .000000
G1 | X48 .8095 Y45 .5871
G1 | X48 .7571 Y45 .5821
G1 | X48 .7254 Y45 .51
G1 | X48 .7744 Y45 .4354
G1 | X48 .846 Y45 .458
G1 | X48 .846 Y45 .4579
G4 P0
M280 P0 S20
G1 F6000
G1 X48 .0426 Y47 .6889
G4 P0
M280 P0 S120
G4 P0
G1 F6000 .000000
G2 X48 .0893 Y48 .0702 I9 .9941 J -1.0301 G2 X48 .1371 Y48 .3547 I5 .5899 J -0.7931
G1 | X48 .1922 Y48 .6381
G1 | X48 .5347 Y48 .0919
G2 X48 .7882 Y47 .5754 I -2.353 J -1.4754
G1 | X48 .7531 Y47 .4981
G1 | X48 .5572 Y47 .499
G1 | X48 .453 Y47 .6165
G1 | X48 .3782 Y47 .7209
G1 | X48 .2779 Y47 .7318
G1 | X48 .1559 Y47 .5721
G1 | X48 .2474 Y47 .4306
G1 | X48 .2553 Y47 .3998
G1 | X48 .176 Y47 .3516
G1 | X48 .0827 Y47 .3989
G2 X48 .0426 Y47 .6889 I0 .5733 J0 .2269 G1 X48 .0426 Y47 .6889
G4 P0
M280 P0 S20
G1 F6000
G1 X48 .3116 Y47 .9472
G4 P0
M280 P0 S120
G4 P0
G1 F6000 .000000
G1 | X48 .2873 Y48 .0057 F6000 .000000
G1 | X48 .2288 Y48 .03
G1 | X48 .1703 Y48 .0058
G1 | X48 .146 Y47 .9472
G1 | X48 .1703 Y47 .8886
G1 | X48 .2288 Y47 .8644

G1 | X48 .2873 Y47 .8886
G1 | X48 .3116 Y47 .9472
G1 | X48 .3116 Y47 .9472
G4 P0
M280 P0 S20
G1 F6000
G1 X47 .526 Y49 .8531
G4 P0
M280 P0 S120
G4 P0
G1 F6000 .000000
G3 X47 .6406 Y50 .5553 I -0.7921 J0 .4897 G3 X47 .2918 Y50 .8519 I -0.3753 J -0.088 G1 X47 .2856 Y50 .8751
G2 X47 .4705 Y50 .9792 I0 .6044 J -0.8572 G2 X47 .8987 Y50 .9729 I0 .2071 J -0.4745 G1 X48 .046 Y50 .7076
G3 X48 .0719 Y50 .4402 I0 .6317 J -0.0737 G3 X48 .2034 Y50 .2149 I0 .572 J0 .1828 G2 X48 .383 Y50 .0044 I -2.4982 J -2.3139
G1 | X48 .3943 Y49 .9718
G1 | X48 .2964 Y49 .8986
G2 X47 .929 Y50 .1096 I0 .2607 J0 .8793
G1 | X47 .7427 Y50 .2846
G1 | X47 .7885 Y50 .1096
G3 X47 .8594 Y49 .9652 I0 .3907 J0 .1022
G1 | X47 .9281 Y49 .9288
G1 | X47 .94 Y49 .8606
G2 X47 .5825 Y49 .7749 I -0.4132 J0 .9357
G1 | X47 .5277 Y49 .8003
G1 | X47 .526 Y49 .853
G1 | X47 .526 Y49 .8531
G4 P0
M280 P0 S20
G1 F6000
G1 X47 .1033 Y49 .8312
G4 P0
M280 P0 S120
G4 P0
G1 F6000 .000000
G3 X47 .1224 Y50 .3186 I -0.9126 J0 .2798 G3 X46 .9075 Y50 .7097 I -0.7797 J -0.1738 G1 X46 .7586 Y50 .6814
G3 X46 .6983 Y50 .2285 I0 .7643 J -0.3321 G3 X46 .9235 Y49 .7856 I0 .7703 J0 .1128
G1 | X47 .1033 Y49 .8312
G1 | X47 .1033 Y49 .8312
G4 P0
M280 P0 S20
G1 F6000
G1 X46 .1205 Y50 .3414
G4 P0
M280 P0 S120
G4 P0
G1 F6000 .000000
G1 | X46 .0278 Y50 .3686 F6000 .000000
G1 | X45 .9745 Y50 .2204
G1 | X46 .0407 Y50 .0874
G1 | X46 .0958 Y50 .086
G1 | X46 .1381 Y50 .1755
G3 X46 .1205 Y50 .3413 I -0.4137 J0 .04 G1 X46 .1205 Y50 .3414
G4 P0
M280 P0 S20
G1 F6000
G1 X45 .796 Y49 .8252
G4 P0
M280 P0 S120
G4 P0
G1 F6000 .000000
G3 X45 .7129 Y50 .2838 I -3.7138 J -0.4366

G1 | X45 .6544 Y50 .3997
G1 | X45 .7478 Y50 .654
G2 X46 .2867 Y50 .5111 I0 .1151 J -0.6536 G3 X46 .4072 Y50 .4326 I0 .3995 J0 .4818 G1 X46 .4306 Y50 .4397
G3 X46 .4488 Y50 .4713 I -0.8635 J0 .5196 G2 X46 .5411 Y50 .6377 I128 .8961 J -71.339 G1 X46 .6621 Y50 .7537
G2 X46 .8722 Y50 .8033 I0 .2101 J -0.4201 G2 X47 .4283 Y50 .3623 I0 . J -0.5712
G2 X47 .14 Y49 .659 I -0.6378 J -0.1493 G2 X46 .7654 Y49 .6222 I -0.2239 J0 .3548 G2 X46 .5244 Y49 .8941 I0 .1417 J0 .3685
G1 | X46 .4059 Y50 .018
G1 | X46 .2217 Y49 .9846
G3 X46 .0373 Y49 .6642 I0 .2871 J -0.3784
G1 | X46 .1645 Y49 .5204
G1 | X46 .2049 Y49 .4941
G1 | X46 .201 Y49 .4376
G1 | X46 .1349 Y49 .3815
G2 X46 .0006 Y49 .3548 I -0.1344 J0 .3255 G1 X45 .9063 Y49 .4166
G2 X45 .796 Y49 .8253 I1 .3288 J0 .5778 G1 X45 .796 Y49 .8252
G4 P0
M280 P0 S20
G1 F6000
G1 X44 .4214 Y48 .9816
G4 P0
M280 P0 S120
G4 P0
G1 F6000 .000000
G1 | X44 .4214 Y49 .6024
G1 | X43 .0143 Y49 .6024
G1 | X41 .6073 Y49 .6024
G1 | X41 .6073 Y48 .9816
G1 | X41 .6073 Y48 .3608
G1 | X43 .0143 Y48 .3608
G1 | X44 .4214 Y48 .3608
G1 | X44 .4214 Y48 .9816
G4 P0
M280 P0 S20
G1 F6000
G1 X44 .5042 Y51 .5885
G4 P0
M280 P0 S120
G4 P0
G1 F6000 .000000
G1 | X44 .5042 Y53 .161
G1 | X36 .1033 Y53 .161
G1 | X27 .7024 Y53 .161
G1 | X27 .7024 Y51 .5885
G1 | X27 .7024 Y50 .0159
G1 | X36 .1033 Y50 .0159
G1 | X44 .5042 Y50 .0159
G1 | X44 .5042 Y51 .5885
G4 P0
M280 P0 S20
G1 F6000
G1 X47 .8149 Y50 .721
G4 P0
M280 P0 S120
G4 P0
G1 F6000 .000000
G3 X47 .7815 Y50 .8945 I -0.4669 J -0.
G1 | X47 .7322 Y50 .9279
G1 | X47 .6128 Y50 .8173
G3 X47 .7046 Y50 .5692 I0 .3156 J -0.0243
G1 | X47 .7672 Y50 .5741
G1 | X47 .8149 Y50 .7209
G1 | X47 .8149 Y50 .721

G4 P0
M280 P0 S20
G1 F6000
G1 X51 .5464 Y51 .7915
G4 P0
M280 P0 S120
G4 P0
G1 F6000 .000000
G3 X51 .7481 Y52 .4717 I -1.3353 J0 .7659 G3 X51 .6186 Y53 .0855 I -1.2014 J0 .067 G3 X51 .1162 Y53 .8204 I -3.108 J -1.5857 G3 X50 .6352 Y54 .1896 I -1.2088 J -1.0766 G3 X49 .7189 Y54 .3769 I -0.8034 J -1.596 G3 X48 .9685 Y54 .0841 I0 .0837 J -1.3227 G1 X48 .8682 Y53 .9068
G3 X48 .8874 Y53 .5068 I1 .0635 J -0.1494 G3 X49 .0159 Y53 .1112 I2 .569 J0 .6162
G1 | X49 .0649 Y53 .0784
G1 | X49 .1361 Y53 .0931
G3 X49 .4486 Y53 .244 I -1.643 J3 .8037 G2 X49 .9901 Y53 .4012 I0 .6411 J -1.1964 G2 X50 .4068 Y53 .3144 I0 .0567 J -0.7709 G2 X50 .6101 Y53 .0956 I -0.2097 J -0.3987 G2 X50 .7105 Y52 .6173 I -1.1063 J -0.4819 G3 X50 .7441 Y52 .2026 I2 .6706 J0 .0077
G3 X50 .8429 Y51 .7897 I2 .753 J0 .4409
G2 X50 .9738 Y51 .3817 I -246.8361 J -79.3924 G2 X51 .0095 Y51 .269 I -18.3597 J -5.8718 G1 X51 .1194 Y51 .2412
G3 X51 .5464 Y51 .7915 I -1.7499 J1 .7987
G1 X51 .5464 Y51 .7915
G4 P0
M280 P0 S20
G1 F6000
G1 X53 .2919 Y48 .5763
G4 P0
M280 P0 S120
G4 P0
G1 F6000 .000000
G3 X54 .3542 Y49 .4201 I -3.0103 J4 .8803 G1 X54 .4096 Y49 .7039
G3 X54 .2588 Y49 .971 I -1.1987 J -0.5008 G3 X54 .1003 Y50 .1261 I -0.5488 J -0.4021 G1 X53 .9177 Y50 .1606
G3 X53 .6334 Y50 .0128 I0 .1583 J -0.6519 G2 X53 .2845 Y49 .8332 I -0.5333 J0 .6074
G1 | X53 .1129 Y49 .8908
G1 | X53 .0682 Y50 .0272
G2 X53 .1546 Y50 .6006 I3 .1917 J -0.1876 G3 X53 .2445 Y51 .1823 I -3.2908 J0 .8064 G3 X53 .2069 Y51 .388 I -0.4269 J0 .0284 G3 X53 .0978 Y51 .5612 I -0.6941 J -0.3164
G1 | X53 .0389 Y51 .5887
G1 | X52 .9698 Y51 .5667
G3 X52 .1474 Y50 .9559 I13 .7987 J -19.439 G2 X51 .3321 Y50 .3235 I -577.9588 J744 .2594 G2 X51 .3156 Y50 .3114 I -0.2332 J0 .301
G3 X51 .1396 Y49 .7767 I0 .2649 J -0.3835
G3 X51 .6155 Y49 .4368 I0 .4759 J0 .1632
G1 X51 .6708 Y49 .4557
G3 X51 .8291 Y49 .6023 I -0.7481 J0 .9658 G1 X52 .0549 Y49 .5578
G2 X52 .0342 Y49 .0346 I -0.6535 J -0.2361 G3 X51 .8926 Y48 .669 I3 .1589 J -1.4333 G3 X51 .8704 Y48 .5284 I0 .4345 J -0.1406 G3 X52 .0021 Y48 .0786 I0 .8344 J0 .
G1 | X52 .2427 Y47 .947
G1 | X52 .2695 Y47 .9544
G3 X53 .2919 Y48 .5762 I -48.9593 J81 .6537 G1 X53 .2919 Y48 .5763
G4 P0

M280 P0 S20
G1 F6000
G1 X53 .954 Y46 .3177
G4 P0
M280 P0 S120
G4 P0
G1 F6000 .000000
G2 X53 .8284 Y46 .5989 I0 .3422 J0 .3215 G2 X53 .8991 Y46 .9555 I0 .6516 J0 .0562 G2 X54 .4577 Y47 .3239 I0 .6083 J -0.3146 G2 X54 .9756 Y47 .034 I0 .0392 J -0.5377 G2 X55 .052 Y46 .6001 I -0.6555 J -0.339 G2 X54 .8802 Y46 .2978 I -0.456 J0 .0591 G2 X54 .3766 Y46 .1295 I -0.4868 J0 .6189 G2 X53 .954 Y46 .3176 I0 .0128 J0 .5975 G1 X53 .954 Y46 .3177
G4 P0
M280 P0 S20
G1 F6000
G1 X55 .2639 Y45 .4061
G4 P0
M280 P0 S120
G4 P0
G1 F6000 .000000
G3 X55 .8136 Y45 .887 I -0.6145 J1 .2571 G3 X56 .0074 Y46 .5213 I -0.9601 J0 .6402 G3 X55 .8287 Y47 .3161 I -1.8179 J0 .0087 G3 X55 .2641 Y48 .0712 I -2.1945 J -1.0523 G3 X54 .6044 Y48 .3186 I -0.6442 J -0.7145 G3 X53 .6748 Y48 .0458 I0 .0292 J -1.8197 G3 X53 .1153 Y47 .2363 I0 .6489 J -1.0466 G3 X53 .271 Y45 .9877 I1 .9755 J -0.3876 G3 X53 .6582 Y45 .48 I1 .3869 J0 .6561 G3 X54 .1623 Y45 .2221 I0 .7861 J0 .9151 G3 X54 .6374 Y45 .2055 I0 .2786 J1 .1607 G3 X55 .2639 Y45 .4061 I -0.3761 J2 .2529 G1 X55 .2639 Y45 .4061
G4 P0
M280 P0 S20
G1 F6000
G1 X56 .133 Y41 .8099
G4 P0
M280 P0 S120
G4 P0
G1 F6000 .000000
G3 X57 .3043 Y42 .1863 I -2.3519 J9 .3305 G1 X57 .4016 Y42 .3091
G3 X57 .2877 Y42 .7013 I -0.4879 J0 .0709 G3 X56 .8579 Y42 .9418 I -0.5436 J -0.4671 G2 X56 .2437 Y43 .1108 I0 .4651 J2 .8902
G1 | X56 .1744 Y43 .2129
G1 | X56 .2134 Y43 .343
G2 X56 .5591 Y43 .7973 I3 .4946 J -2.3001
G1 | X56 .9437 Y44 .237
G1 | X56 .8119 Y44 .5134
G1 | X56 .68 Y44 .7899
G1 | X55 .7444 Y44 .5057
G2 X54 .8073 Y44 .2268 I -25.9355 J85 .4289 G2 X54 .4509 Y44 .1285 I -3.4913 J11 .9701 G1 X54 .2413 Y43 .9114
G3 X54 .2837 Y43 .3754 I0 .8954 J -0.1988 G1 X54 .462 Y43 .2245
G3 X54 .7674 Y43 .2719 I0 .0906 J0 .4234 G2 X55 .0627 Y43 .3043 I0 .185 J -0.3236 G1 X55 .1532 Y43 .1523
G3 X55 .1707 Y42 .9476 I0 .361 J -0.0722
G1 | X55 .267 Y42 .857
G1 | X55 .3175 Y42 .6977
G2 X54 .9894 Y42 .4912 I -0.4384 J0 .3326 G3 X54 .707 Y42 .2708 I0 .0809 J -0.3948 G3 X54 .6725 Y41 .8311 I0 .5507 J -0.2644

G3 X54 .7929 Y41 .5187 I2 .0924 J0 .6268
G1 | X54 .8328 Y41 .4945
G1 | X54 .8907 Y41 .5022
G3 X56 .133 Y41 .8097 I -36.4985 J150 .1014 G1 X56 .133 Y41 .8099
G4 P0
M280 P0 S20
G1 F6000
G1 X56 .4666 Y38 .5456
G4 P0
M280 P0 S120
G4 P0
G1 F6000 .000000
G1 | X57 .7884 Y39 .077
G1 | X57 .7812 Y39 .5595
G3 X57 .7577 Y40 .0404 I -7.0526 J -0.1036 G3 X57 .7153 Y40 .3524 I -3.0259 J -0.2516 G3 X57 .59 Y40 .5823 I -0.4185 J -0.0791 G1 X57 .3883 Y40 .6628
G3 X57 .1284 Y40 .6271 I -0. J -0.9658
G3 X56 .7951 Y40 .4972 I0 .4856 J -1.7381 G2 X56 .3461 Y40 .3979 I -0.4161 J0 .8162 G2 X55 .6444 Y40 .5387 I0 .0798 J2 .216
G3 X55 .0923 Y40 .7331 I -4.8369 J -12.8565
G1 | X55 .0138 Y40 .7457
G1 | X54 .9694 Y40 .7091
G3 X54 .9329 Y40 .3305 I1 .9426 J -0.3786 G3 X55 .0254 Y39 .9751 I0 .7286 J0 .
G3 X55 .2432 Y39 .7751 I0 .4123 J0 .2304 G2 X55 .5851 Y39 .3568 I -0.2499 J -0.553 G2 X55 .4193 Y39 .0023 I -0.3106 J -0.0707 G3 X55 .1908 Y38 .7821 I0 .2477 J -0.4856 G3 X55 .0984 Y38 .4265 I0 .6381 J -0.3555 G3 X55 .1096 Y38 .0256 I7 .1536 J -0.
G1 | X55 .1216 Y38 .0143
G1 | X55 .144 Y38 .0186
G3 X56 .4666 Y38 .5458 I -87.8272 J222 .2699 G1 X56 .4666 Y38 .5456
G4 P0
M280 P0 S20
G1 F6000
G1 X45 .1369 Y44 .2027
G4 P0
M280 P0 S120
G4 P0
G1 F6000 .000000
G3 X45 .2822 Y44 .5004 I -0.1727 J0 .2686 G3 X45 .0448 Y45 .2113 I -1.628 J -0.1487 G1 X45 .071 Y45 .2862
G2 X45 .8995 Y45 .5151 I1 .9951 J -5.6083 G2 X46 .1479 Y45 .4976 I0 .0924 J -0.4604 G2 X46 .4123 Y45 .3354 I -0.2451 J -0.696 G3 X46 .6001 Y45 .2333 I0 .2813 J0 .2936 G1 X46 .6562 Y45 .2777
G3 X46 .6276 Y45 .4378 I -0.4631 J -0.
G1 | X46 .5721 Y45 .5058
G1 | X46 .5396 Y45 .6265
G1 | X46 .6818 Y45 .7119
G1 | X46 .74 Y45 .6714
G2 X46 .7816 Y45 .4429 I -0.6239 J -0.2316 G3 X46 .796 Y45 .1751 I2 .7279 J0 .0122 G3 X46 .8477 Y44 .8014 I5 .3964 J0 .5568
G1 | X46 .9126 Y44 .429
G1 | X46 .5255 Y44 .8014
G1 | X46 .1384 Y45 .1739
G1 | X46 .1874 Y44 .8495
G3 X46 .2662 Y44 .5447 I1 .5169 J0 .2294
G1 | X46 .3292 Y44 .4678
G1 | X46 .337 Y44 .4233
G1 | X46 .2474 Y44 .3649
G1 | X46 .1192 Y44 .3686

G1 X46 .0916 Y44 .4154
G3 X46 .097 Y44 .5121 I -0.3517 J0 .0683 G3 X46 .0498 Y44 .9428 I -7.2275 J -0.575 G3 X45 .9147 Y45 .2698 I -0.7018 J -0.0985
G1 | X45 .826 Y45 .2408
G1 | X45 .7868 Y45 .147
G1 | X45 .7391 Y45 .1531
G3 X45 .4702 Y45 .3143 I -0.281 J -0.1636 G1 X45 .3645 Y45 .1666
G2 X45 .4052 Y45 .0337 I -0.9365 J -0.3596 G2 X45 .4173 Y44 .9389 I -0.4631 J -0.1075
G1 | X45 .4456 Y44 .9222
G1 | X45 .5415 Y45 .0028
G1 | X45 .6205 Y45 .037
G1 | X45 .663 Y44 .9896
G3 X45 .6771 Y44 .8174 I1 .0626 J0 .
G3 X45 .7166 Y44 .6634 I0 .8893 J0 .1461
G1 | X45 .703 Y44 .6141
G1 | X45 .6586 Y44 .6153
G1 | X45 .5118 Y44 .6414
G1 | X45 .4608 Y44 .5325
G1 | X45 .5975 Y44 .4247
G1 | X45 .7942 Y44 .5116
G1 | X45 .9932 Y44 .7599
G1 | X45 .9937 Y44 .5362
G1 | X45 .9234 Y44 .3661
G2 X45 .6837 Y44 .2262 I -0.3857 J0 .3858 G2 X45 .1558 Y44 .1426 I -0.6292 J2 .2628
G1 | X45 .1369 Y44 .2024
G1 | X45 .1369 Y44 .2027
G4 P0
M280 P0 S20
G1 F6000
G1 X44 .5575 Y44 .0619
G4 P0
M280 P0 S120
G4 P0
G1 F6000 .000000
G3 X44 .6449 Y44 .3546 I -0.321 J0 .2553 G3 X44 .4651 Y45 .0706 I -2.3861 J -0.2185
G1 | X44 .4662 Y45 .1741
G1 | X44 .53 Y45 .2154
G3 X44 .654 Y45 .228 I -0. J0 .6177
G3 X44 .8079 Y45 .2724 I -0.2035 J0 .9936
G1 | X44 .8618 Y45 .259
G1 | X44 .8629 Y45 .2102
G3 X44 .7844 Y44 .9485 I0 .2793 J -0.2264 G3 X44 .9624 Y44 .2017 I2 .8258 J0 .2791
G1 | X44 .9582 Y44 .0982
G1 | X44 .8923 Y44 .0569
G3 X44 .7684 Y44 .0444 I0 . J -0.6195
G3 X44 .6145 Y43 .9999 I0 .2008 J -0.9836
G1 | X44 .5592 Y44 .0131
G1 | X44 .5574 Y44 .062
G1 | X44 .5575 Y44 .0619
G4 P0
M280 P0 S20
G1 F6000
G1 X43 .6399 Y44 .0751
G4 P0
M280 P0 S120
G4 P0
G1 F6000 .000000
G2 X43 .5409 Y44 .7489 I0 .6217 J0 .4355 G2 X43 .9747 Y45 .0873 I0 .4702 J -0.1555 G3 X44 .1297 Y45 .1148 I -0.05 J0 .7328 G3 X44 .2367 Y45 .1621 I -0.1225 J0 .4217 G1 X44 .2938 Y45 .1451
G2 X44 .3362 Y44 .9512 I -0.4032 J -0.1898
G1 | X44 .2957 Y44 .8206
G1 | X44 .2493 Y44 .8221

G1 | X44 .1431 Y44 .9289
G1 | X44 .0035 Y44 .967
G1 | X43 .8824 Y44 .9231
G1 | X43 .8296 Y44 .8221
G3 X43 .8557 Y44 .2834 I2 .0064 J -0.173 G3 X43 .97 Y44 .062 I0 .4225 J0 .078
G1 | X44 .0877 Y44 .0175
G1 | X44 .2392 Y44 .0825
G1 | X44 .3597 Y44 .1167
G1 | X44 .3801 Y44 .0564
G2 X43 .988 Y43 .8883 I -0.3792 J0 .3432 G2 X43 .6399 Y44 .0753 I0 .011 J0 .438 G1 X43 .6399 Y44 .0751
G4 P0
M280 P0 S20
G1 F6000
G1 X43 .1799 Y46 .4158
G4 P0
M280 P0 S120
G4 P0
G1 F6000 .000000
G1 | X43 .1799 Y47 .947
G1 | X42 .3936 Y47 .947
G1 | X41 .6073 Y47 .947
G1 | X41 .6073 Y46 .4158
G1 | X41 .6073 Y44 .8846
G1 | X42 .3936 Y44 .8846
G1 | X43 .1799 Y44 .8846
G1 | X43 .1799 Y46 .4158
G4 P0
M280 P0 S20
G1 F6000
G1 X41 .1935 Y44 .7184
G4 P0
M280 P0 S120
G4 P0
G1 F6000 .000000
G1 | X41 .1935 Y49 .6016
G1 | X34 .448 Y49 .6016
G1 | X27 .7025 Y49 .6016
G1 | X27 .7025 Y48 .9809
G1 | X27 .7025 Y48 .3601
G1 | X33 .5376 Y48 .3601
G1 | X39 .3727 Y48 .3601
G1 | X39 .3727 Y44 .7597
G1 | X39 .3727 Y41 .1594
G1 | X35 .1929 Y41 .1594
G1 | X31 .0132 Y41 .1594
G1 | X31 .0132 Y40 .4972
G1 | X31 .0132 Y39 .8351
G1 | X36 .1033 Y39 .8351
G1 | X41 .1935 Y39 .8351
G1 | X41 .1935 Y44 .7184
G4 P0
M280 P0 S20
G1 F6000
G1 X38 .9588 Y43 .8514
G4 P0
M280 P0 S120
G4 P0
G1 F6000 .000000
G1 | X38 .9588 Y44 .5549
G1 | X37 .6759 Y44 .5549
G1 | X36 .3931 Y44 .5549
G1 | X36 .3931 Y43 .8514
G1 | X36 .3931 Y43 .1478
G1 | X37 .6759 Y43 .1478
G1 | X38 .9588 Y43 .1478
G1 | X38 .9588 Y43 .8514
G4 P0
M280 P0 S20

G1 F6000
G1 X38 .9588 Y42 .196
G4 P0
M280 P0 S120
G4 P0
G1 F6000 .000000
G1 | X38 .9588 Y42 .8995
G1 | X37 .6759 Y42 .8995
G1 | X36 .3931 Y42 .8995
G1 | X36 .3931 Y42 .196
G1 | X36 .3931 Y41 .4925
G1 | X37 .6759 Y41 .4925
G1 | X38 .9588 Y41 .4925
G1 | X38 .9588 Y42 .196
G4 P0
M280 P0 S20
G1 F6000
G1 X38 .9587 Y45 .5881
G4 P0
M280 P0 S120
G4 P0
G1 F6000 .000000
G1 | X38 .9587 Y46 .2917
G1 | X37 .6758 Y46 .2917
G1 | X36 .393 Y46 .2917
G1 | X36 .393 Y45 .5881
G1 | X36 .393 Y44 .8846
G1 | X37 .6758 Y44 .8846
G1 | X38 .9587 Y44 .8846
G1 | X38 .9587 Y45 .5881
G4 P0
M280 P0 S20
G1 F6000
G1 X38 .9587 Y47 .3263
G4 P0
M280 P0 S120
G4 P0
G1 F6000 .000000
G1 | X38 .9587 Y48 .0298
G1 | X37 .6758 Y48 .0298
G1 | X36 .393 Y48 .0298
G1 | X36 .393 Y47 .3263
G1 | X36 .393 Y46 .6227
G1 | X37 .6758 Y46 .6227
G1 | X38 .9587 Y46 .6227
G1 | X38 .9587 Y47 .3263
G4 P0
M280 P0 S20
G1 F6000
G1 X46 .2549 Y47 .0988
G4 P0
M280 P0 S120
G4 P0
G1 F6000 .000000
G2 X46 .1958 Y47 .2493 I0 .6513 J0 .3425 G2 X46 .1206 Y47 .5954 I3 .4282 J0 .9267 G3 X46 .0329 Y47 .9125 I -1.5382 J -0.2547
G1 | X45 .9819 Y47 .9472
G1 | X45 .9569 Y48 .0161
G2 X46 .2046 Y48 .1336 I0 .35 J -0.418
G1 | X46 .3436 Y48 .1126
G1 | X46 .3684 Y48 .0463
G3 X46 .345 Y47 .9155 I0 .3303 J -0.1268 G3 X46 .3739 Y47 .5536 I2 .6544 J0 .0304 G3 X46 .562 Y47 .176 I0 .6769 J0 .1015 G1 X46 .745 Y47 .1751
G3 X46 .8907 Y47 .6461 I -0.3737 J0 .3737 G3 X46 .5688 Y48 .1154 I -0.692 J -0.1297 G1 X46 .5672 Y48 .1653
G2 X46 .7854 Y48 .269 I0 .4047 J -0.5704 G2 X47 .0835 Y48 .2665 I0 .1446 J -0.5246

G2 X47 .3781 Y48 .0947 I -0.2008 J -0.683 G3 X47 .5925 Y47 .966 I0 .383 J0 .3952
G1 X47 .6493 Y48 .0074
G3 X47 .6174 Y48 .1701 I -0.4305 J -0.
G3 X47 .5282 Y48 .3045 I -0.3783 J -0.1544
G1 | X47 .4979 Y48 .4009
G1 | X47 .5573 Y48 .4649
G1 | X47 .6555 Y48 .4352
G1 | X47 .7142 Y48 .2876
G3 X47 .7343 Y48 .0726 I1 .689 J0 .0496 G3 X47 .8073 Y47 .6984 I5 .3385 J0 .8462
G1 | X47 .7234 Y47 .5093
G1 | X47 .5167 Y47 .5363
G1 | X47 .1357 Y47 .9053
G1 | X47 .1957 Y47 .6156
G3 X47 .2791 Y47 .346 I1 .4447 J0 .2994
G1 | X47 .3284 Y47 .2984
G1 | X47 .3724 Y47 .1977
G1 | X47 .2562 Y47 .1195
G1 | X47 .1666 Y47 .1783
G2 X47 .0893 Y47 .5 I0 .8563 J0 .3759
G3 X46 .9538 Y48 .1185 I -2.0127 J -0.1168
G1 | X46 .831 Y48 .1595
G1 | X46 .8011 Y48 .1035
G3 X46 .8483 Y47 .6642 I3 .0641 J0 .107 G2 X46 .879 Y47 .2228 I -1.985 J -0.3598 G1 X46 .8247 Y47 .0814
G2 X46 .5097 Y46 .9392 I -0.3033 J0 .2518
G1 | X46 .2548 Y47 .0985
G1 | X46 .2549 Y47 .0988
G4 P0
M280 P0 S20
G1 F6000
G1 X46 .7956 Y54 .904
G4 P0
M280 P0 S120
G4 P0
G1 F6000 .000000
G3 X47 .0118 Y55 .0165 I -0.353 J0 .9424 G3 X47 .2181 Y55 .1937 I -0.7121 J1 .0381 G2 X47 .5393 Y55 .3297 I0 .314 J -0.2943 G2 X48 .0096 Y55 .1803 I -0.0144 J -0.8601
G1 | X48 .3256 Y54 .9656
G1 | X48 .5255 Y55 .1534
G3 X48 .6893 Y55 .3567 I -0.6502 J0 .6916
G1 | X48 .7253 Y55 .4867
G1 | X48 .6678 Y55 .6006
G3 X47 .4322 Y56 .4399 I -11.5356 J -15.6521 G3 X46 .1623 Y57 .1272 I -6.1504 J -9.8473 G1 X46 .0251 Y57 .0918
G3 X45 .9146 Y56 .7079 I0 .4689 J -0.3429 G1 X46 .0658 Y56 .5158
G2 X46 .2074 Y56 .4465 I -0.162 J -0.5103 G2 X46 .3586 Y56 .3142 I -0.4903 J -0.7123 G1 X46 .3993 Y56 .1499
G2 X46 .1637 Y55 .5507 I -2.5102 J0 .6406 G3 X45 .8439 Y54 .9363 I15 .9321 J -8.6842
G1 | X45 .8296 Y54 .8777
G1 | X45 .9667 Y54 .7415
G3 X46 .7956 Y54 .9031 I -0.0645 J2 .5368 G1 X46 .7956 Y54 .904
G4 P0
M280 P0 S20
G1 F6000
G1 X44 .3781 Y56 .203
G4 P0
M280 P0 S120
G4 P0
G1 F6000 .000000
G2 X44 .863 Y57 .0909 I119 .3041 J -64.5694 G2 X45 .0595 Y57 .4397 I18 .6384 J -10.2679

G1 | X45 .2592 Y57 .7867
G1 | X45 .0265 Y57 .9052
G3 X44 .5519 Y57 .9709 I -0.3324 J -0.653 G3 X44 .3044 Y57 .7622 I0 .0649 J -0.328 G2 X43 .6899 Y56 .6028 I -5.0117 J1 .914 G2 X43 .3121 Y56 .3425 I -0.5373 J0 .3755 G2 X43 .1103 Y56 .3159 I -0.2168 J0 .8633
G1 | X43 .0303 Y56 .3375
G1 | X42 .9997 Y56 .4039
G2 X43 .2029 Y57 .4712 I14 .5209 J -2.2116 G3 X43 .2238 Y58 .4984 I -2.4616 J0 .5638
G1 | X42 .9761 Y58 .6864
G1 | X42 .8061 Y58 .5712
G3 X42 .3391 Y57 .4234 I6 .8622 J -3.4605 G3 X41 .964 Y56 .1815 I50 .1377 J -15.8208 G1 X41 .9636 Y56 .1222
G3 X42 .3799 Y55 .6273 I0 .7419 J0 .2016 G3 X43 .6831 Y55 .3187 I1 .3949 J2 .9839 G1 X43 .8485 Y55 .3958
G3 X44 .3781 Y56 .2026 I -4.4723 J3 .5137 G1 X44 .3781 Y56 .203
G4 P0
M280 P0 S20
G1 F6000
G1 X40 .9859 Y57 .486
G4 P0
M280 P0 S120
G4 P0
G1 F6000 .000000
G3 X40 .9123 Y58 .6639 I -48.397 J -2.433 G3 X40 .8738 Y58 .9862 I -3.6642 J -0.2738 G3 X40 .7276 Y59 .2218 I -0.3578 J -0.0589 G3 X40 .2048 Y59 .4671 I -0.9183 J -1.2775 G3 X39 .3922 Y59 .4868 I -0.4484 J -1.727 G1 X39 .2071 Y59 .259
G3 X39 .2415 Y58 .998 I1 .0054 J0 .
G3 X39 .3228 Y58 .8285 I0 .4953 J0 .1332 G1 X39 .3512 Y58 .663
G2 X39 .0331 Y57 .8623 I -4.7535 J1 .4252 G3 X38 .6443 Y57 .0505 I21 .7876 J -10.9333
G1 | X38 .6277 Y56 .9741
G1 | X38 .825 Y56 .7242
G3 X39 .3619 Y56 .7989 I0 .1729 J0 .7248 G1 X39 .4629 Y56 .8942
G3 X39 .5839 Y57 .1475 I -0.9805 J0 .624 G2 X39 .824 Y57 .3878 I0 .3625 J -0.122 G2 X40 .1661 Y57 .3441 I0 .1261 J -0.3733 G2 X40 .3049 Y57 .1762 I -0.2025 J -0.3089 G2 X40 .3482 Y56 .9029 I -0.5504 J -0.2272 G3 X40 .4081 Y56 .644 I0 .4411 J -0.0343 G3 X40 .6141 Y56 .4517 I0 .4282 J0 .2523 G3 X40 .9069 Y56 .3199 I1 .7777 J3 .5584
G1 | X40 .9745 Y56 .3067
G1 | X41 .0091 Y56 .3409
G3 X40 .9858 Y57 .486 I -19.1317 J0 .1839 G1 X40 .9859 Y57 .486
G4 P0
M280 P0 S20
G1 F6000
G1 X33 .3824 Y58 .3023
G4 P0
M280 P0 S120
G4 P0
G1 F6000 .000000
G3 X33 .3243 Y58 .8765 I -35.6135 J -3.3115 G3 X33 .3091 Y58 .9733 I -1.0284 J -0.1124 G1 X33 .43 Y59 .0909
G2 X33 .6982 Y58 .8816 I -0.0935 J -0.3964 G2 X33 .8302 Y58 .1253 I -1.137 J -0.588 G2 X33 .551 Y57 .7716 I -0.4371 J0 .058 G1 X33 .4835 Y57 .8042

G2 X33 .3824 Y58 .3023 I2 .2571 J0 .7173 G1 X33 .3824 Y58 .3023
G4 P0
M280 P0 S20
G1 F6000
G1 X33 .3481 Y56 .8366
G4 P0
M280 P0 S120
G4 P0
G1 F6000 .000000
G3 X33 .8868 Y56 .991 I -0.793 J3 .7851 G3 X34 .1573 Y57 .1335 I -0.3954 J1 .078 G3 X34 .6497 Y57 .6937 I -0.9452 J1 .3272 G3 X34 .8204 Y58 .3763 I -1.2792 J0 .6826 G3 X34 .5017 Y59 .2727 I -1.4201 J -0.
G3 X33 .7052 Y59 .7465 I -1.0449 J -0.8505 G3 X32 .8201 Y59 .7671 I -0.5062 J -2.7137 G3 X32 .1683 Y59 .5323 I0 .2301 J -1.6605 G1 X32 .1258 Y59 .4468
G3 X32 .2922 Y58 .1995 I15 .678 J1 .4568 G3 X32 .5207 Y56 .929 I118 .7551 J20 .7024 G3 X32 .5472 Y56 .8239 I0 .8337 J0 .1546 G1 X32 .6397 Y56 .7577
G3 X33 .3481 Y56 .8373 I -0.062 J3 .744 G1 X33 .3481 Y56 .8366
G4 P0
M280 P0 S20
G1 F6000
G1 X29 .7716 Y56 .0824
G4 P0
M280 P0 S120
G4 P0
G1 F6000 .000000
G3 X30 .0437 Y56 .3227 I -0.3031 J0 .6175 G3 X30 .1184 Y56 .6114 I -0.388 J0 .2544 G2 X30 .1539 Y56 .924 I0 .8437 J0 .0625
G1 | X30 .2518 Y57 .0427
G1 | X30 .461 Y57 .0345
G2 X30 .798 Y56 .6924 I -0.5858 J -0.9141 G3 X30 .9743 Y56 .5325 I0 .3676 J0 .2281
G1 | X31 .1646 Y56 .5117
G1 | X31 .3354 Y56 .7825
G3 X30 .8735 Y57 .9065 I -3.2491 J -0.6781 G3 X30 .1227 Y59 .0086 I -23.1895 J -14.9924 G1 X30 .0334 Y59 .0779
G3 X29 .5171 Y59 .0999 I -0.2903 J -0.7428 G3 X28 .6436 Y58 .668 I0 .8068 J -2.7303
G1 X28 .5549 Y58 .3722
G3 X28 .9219 Y57 .9211 I0 .8498 J0 .3166
G1 | X29 .1859 Y57 .755
G1 | X29 .1891 Y56 .879
G3 X29 .2656 Y55 .9635 I5 .769 J0 .0214
G1 | X29 .3509 Y55 .8961
G1 | X29 .397 Y55 .9077
G3 X29 .7716 Y56 .0824 I -4.1927 J9 .4814 G1 X29 .7716 Y56 .0824
G4 P0
M280 P0 S20
G1 F6000
G1 X27 .5783 Y55 .1266
G4 P0
M280 P0 S120
G4 P0
G1 F6000 .000000
G3 X28 .4399 Y55 .8315 I -1.1133 J2 .2395 G3 X28 .6938 Y56 .5622 I -0.9535 J0 .7409 G3 X28 .4798 Y57 .3979 I -1.6842 J0 .014 G3 X27 .928 Y57 .9321 I -1.1648 J -0.651 G3 X27 .2254 Y58 .0642 I -0.5715 J -1.1055 G3 X26 .2206 Y57 .7512 I0 .2841 J -2.6811 G3 X25 .8077 Y57 .5057 I3 .0693 J -5.6315

G3 X25 .7176 Y57 .4257 I0 .2161 J -0.3342 G1 X25 .7044 Y57 .3251
G3 X26 .3172 Y56 .1157 I15 .5389 J7 .1138 G3 X27 .1227 Y55 .1731 I2 .7459 J1 .5312 G3 X27 .5783 Y55 .1266 I0 .2647 J0 .3374 G1 X27 .5783 Y55 .1266
G4 P0
M280 P0 S20
G1 F6000
G1 X26 .1864 Y54 .8786
G4 P0
M280 P0 S120
G4 P0
G1 F6000 .000000
G3 X26 .1497 Y54 .9402 I -2.7342 J -1.5876 G3 X25 .5538 Y55 .9132 I -642.6466 J -392.899 G3 X24 .7627 Y56 .7244 I -2.1871 J -1.3417 G3 X24 .3462 Y56 .6962 I -0.1894 J -0.2921
G1 | X24 .1259 Y56 .5068
G1 | X24 .5096 Y55 .8748
G3 X24 .9488 Y55 .3032 I2 .8142 J1 .7086 G3 X25 .3209 Y55 .0297 I0 .9747 J0 .9358 G3 X26 .1106 Y54 .7701 I1 .2847 J2 .5778
G1 | X26 .1864 Y54 .8788
G1 | X26 .1864 Y54 .8786
G4 P0
M280 P0 S20
G1 F6000
G1 X27 .1577 Y56 .676
G4 P0
M280 P0 S120
G4 P0
G1 F6000 .000000
G2 X26 .8748 Y57 .2811 I6 .0534 J3 .1994
G1 | X26 .8863 Y57 .3388
G1 | X27 .1365 Y57 .3729
G2 X27 .483 Y57 .0013 I -0.4155 J -0.7348 G2 X27 .6622 Y56 .3276 I -1.7115 J -0.8161
G1 | X27 .5502 Y56 .1077
G1 | X27 .4956 Y56 .1192
G2 X27 .1577 Y56 .676 I4 .5316 J3 .1303 G1 X27 .1577 Y56 .676
G4 P0
M280 P0 S20
G1 F6000
G1 X22 .9953 Y53 .8441
G4 P0
M280 P0 S120
G4 P0
G1 F6000 .000000
G3 X23 .3037 Y54 .4475 I -0.9126 J0 .8468 G1 X23 .1381 Y54 .5605
G2 X22 .7179 Y54 .358 I -1.0385 J1 .6184
G1 | X22 .5873 Y54 .3735
G1 | X22 .5124 Y54 .55
G2 X22 .6749 Y54 .7955 I0 .3885 J -0.0806 G3 X22 .9376 Y54 .9887 I -3.2418 J4 .6852 G3 X23 .2742 Y55 .2629 I -6.3093 J8 .0872 G3 X23 .4773 Y55 .5528 I -0.4551 J0 .535 G1 X23 .445 Y55 .7214
G3 X23 .2736 Y55 .8516 I -0.4324 J -0.391 G1 X23 .1754 Y55 .8564
G3 X23 .0752 Y55 .7989 I0 .1366 J -0.3544 G3 X22 .3275 Y55 .1797 I16 .5927 J -20.7965
G1 | X21 .5891 Y54 .545
G1 | X21 .7224 Y54 .329
G3 X22 .2523 Y53 .6904 I2 .5392 J1 .5678 G3 X22 .5504 Y53 .5751 I0 .2981 J0 .3273 G3 X22 .7246 Y53 .6236 I -0. J0 .3366
G3 X22 .9953 Y53 .8441 I -0.6504 J1 .0753 G1 X22 .9953 Y53 .8441

G4 P0
M280 P0 S20
G1 F6000
G1 X21 .2979 Y52 .2554
G4 P0
M280 P0 S120
G4 P0
G1 F6000 .000000
G1 | X21 .6081 Y53 .433
G1 | X21 .4182 Y53 .5868
G3 X20 .9469 Y53 .7558 I -0.4775 J -0.5897 G3 X20 .4108 Y53 .5948 I -0.0078 J -0.9467 G3 X19 .6171 Y52 .9281 I2 .6893 J -4.0072 G3 X19 .3057 Y52 .4425 I1 .0789 J -1.0347 G1 X19 .3267 Y52 .3099
G3 X20 .0601 Y51 .5309 I6 .4536 J5 .3409 G3 X20 .8441 Y50 .8966 I4 .8271 J5 .1645 G1 X20 .9309 Y50 .9238
G3 X20 .981 Y51 .0795 I -1.8019 J0 .6664 G3 X21 .2979 Y52 .255 I -102.4242 J28 .2405 G1 X21 .2979 Y52 .2554
G4 P0
M280 P0 S20
G1 F6000
G1 X20 .4189 Y52 .6614
G4 P0
M280 P0 S120
G4 P0
G1 F6000 .000000
G2 X20 .5828 Y53 .0446 I0 .53 J0 .
G1 | X20 .8832 Y53 .1049
G1 | X20 .9467 Y52 .9965
G2 X20 .8268 Y52 .7172 I -0.5833 J0 .085 G2 X20 .5419 Y52 .554 I -0.3442 J0 .2707
G1 | X20 .4189 Y52 .6614
G1 | X20 .4189 Y52 .6614
G4 P0
M280 P0 S20
G1 F6000
G1 X20 .6672 Y50 .0311
G4 P0
M280 P0 S120
G4 P0
G1 F6000 .000000
G1 X20 .6332 Y50 .1239 F6000 .000000
G3 X20 .3807 Y50 .3689 I -1.3844 J -1.1738
G1 | X20 .0942 Y50 .5975
G1 | X19 .4703 Y49 .6406
G3 X18 .8655 Y48 .6779 I28 .2164 J -18.3983
G1 | X18 .8463 Y48 .6092
G1 | X18 .8694 Y48 .5447
G3 X19 .1093 Y48 .289 I2 .0557 J1 .6882
G1 | X19 .3722 Y48 .0433
G1 | X20 .0197 Y48 .9826
G3 X20 .6387 Y49 .9308 I -18.5146 J12 .7629
G1 | X20 .6672 Y50 .0311
G1 | X20 .6672 Y50 .0311
G4 P0
M280 P0 S20
G1 F6000
G1 X18 .8257 Y49 .1045
G4 P0
M280 P0 S120
G4 P0
G1 F6000 .000000
G3 X19 .0507 Y49 .4669 I -0.2463 J0 .404 G1 X18 .8831 Y49 .7546
G3 X18 .6778 Y49 .7867 I -0.16 J -0.3509 G3 X18 .4693 Y49 .7057 I0 .0524 J -0.4435 G3 X18 .2115 Y49 .349 I0 .4052 J -0.5645 G1 X18 .2679 Y49 .0628

G1 X18 .4524 Y48 .9844
G3 X18 .8257 Y49 .1043 I -0.0622 J0 .8347 G1 X18 .8257 Y49 .1045
G4 P0
M280 P0 S20
G1 F6000
G1 X18 .5437 Y50 .2374
G4 P0
M280 P0 S120
G4 P0
G1 F6000 .000000
G3 X19 .2236 Y51 .0932 I -12.4413 J10 .5828 G1 X19 .2602 Y51 .2039
G3 X19 .1098 Y51 .5209 I -0.4091 J -0.
G3 X18 .6879 Y51 .6712 I -0.4219 J -0.5168 G1 X18 .5794 Y51 .6194
G3 X17 .8735 Y50 .6632 I10 .6024 J -8.5652
G1 | X17 .1953 Y49 .6551
G1 | X17 .4208 Y49 .5095
G3 X17 .6514 Y49 .3888 I0 .7649 J1 .1812
G1 | X17 .7367 Y49 .3794
G1 | X17 .8128 Y49 .4207
G3 X18 .5437 Y50 .2375 I -15.8846 J14 .9503 G1 X18 .5437 Y50 .2374
G4 P0
M280 P0 S20
G1 F6000
G1 X18 .7336 Y46 .854
G4 P0
M280 P0 S120
G4 P0
G1 F6000 .000000
G3 X18 .8179 Y47 .1242 I -1.2288 J0 .5316 G1 X18 .8034 Y47 .2045
G3 X17 .5651 Y48 .643 I -5.1581 J -3.1881 G3 X16 .7545 Y48 .9402 I -0.8105 J -0.9567 G1 X16 .5595 Y48 .8268
G3 X16 .4461 Y48 .3984 I0 .7527 J -0.4284
G1 | X16 .4731 Y48 .3053
G1 | X16 .5225 Y48 .2782
G2 X16 .9354 Y48 .1055 I0 . J -0.58
G2 X17 .1082 Y47 .6842 I -0.4272 J -0.4212 G1 X17 .0427 Y47 .5971
G2 X16 .7564 Y47 .5822 I -0.1749 J0 .6031 G3 X16 .1057 Y47 .5435 I -0.2455 J -1.3591 G3 X15 .8058 Y47 .2905 I0 .1468 J -0.4783 G3 X15 .6516 Y46 .9287 I2 .7377 J -1.3808
G1 | X15 .6621 Y46 .8825
G1 | X15 .7111 Y46 .8556
G3 X17 .0472 Y46 .5775 I12 .9553 J58 .9056 G3 X18 .353 Y46 .5571 I0 .7096 J3 .6163 G3 X18 .7336 Y46 .854 I -0.0814 J0 .4968 G1 X18 .7336 Y46 .854
G4 P0
M280 P0 S20
G1 F6000
G1 X17 .6971 Y44 .4317
G4 P0
M280 P0 S120
G4 P0
G1 F6000 .000000
G3 X17 .823 Y44 .8085 I -1.936 J0 .8563 G1 X17 .8173 Y44 .9489
G3 X16 .6142 Y46 .1207 I -1.7002 J -0.5422 G3 X15 .1106 Y45 .7342 I -0.4249 J -1.4652 G1 X15 .0516 Y45 .6372
G3 X14 .9824 Y45 .3253 I1 .7969 J -0.5623
G1 | X14 .9389 Y45 .001
G1 | X16 .1684 Y44 .5352
G3 X17 .3998 Y44 .0778 I36 .0803 J95 .2477 G1 X17 .4646 Y44 .0632

G1 X17 .5137 Y44 .0862
G3 X17 .6971 Y44 .4316 I -2.3129 J1 .4494 G1 X17 .6971 Y44 .4317
G4 P0
M280 P0 S20
G1 F6000
G1 X18 .8459 Y42 .9766
G4 P0
M280 P0 S120
G4 P0
G1 F6000 .000000
G3 X19 .9728 Y46 .815 I -332.2357 J99 .6211
G1 | X19 .9614 Y46 .8589
G1 | X19 .7344 Y46 .8177
G3 X18 .4439 Y43 .5053 I30 .3644 J -13.7379 G3 X17 .8968 Y41 .5164 I19 .708 J -6.4908 G3 X17 .6465 Y39 .9179 I12 .4619 J -2.7698 G2 X17 .594 Y39 .3803 I -49.1346 J4 .5267 G2 X17 .5612 Y39 .0902 I -14.3843 J1 .4842 G1 X17 .6172 Y39 .0776
G3 X18 .8459 Y42 .9766 I -138.8535 J45 .9023 G1 X18 .8459 Y42 .9766
G4 P0
M280 P0 S20
G1 F6000
G1 X16 .8512 Y41 .407
G4 P0
M280 P0 S120
G4 P0
G1 F6000 .000000
G3 X16 .9249 Y41 .8129 I -2.8031 J0 .7183
G1 | X16 .9048 Y41 .9012
G1 | X16 .834 Y41 .9558
G3 X16 .4499 Y42 .0383 I -0.7068 J -2.3539 G2 X16 .0925 Y42 .1437 I0 .1573 J1 .1918
G1 | X16 .0055 Y42 .2487
G1 | X16 .0931 Y42 .4367
G2 X16 .6802 Y42 .569 I0 .5871 J -1.2366 G3 X17 .0443 Y42 .7158 I -0. J0 .525
G3 X17 .1911 Y43 .0609 I -0.3323 J0 .3451 G1 X17 .0921 Y43 .2158
G3 X15 .9434 Y43 .6385 I -3.1794 J -6.8669 G3 X14 .6859 Y43 .7719 I -1.0265 J -3.6848 G1 X14 .4277 Y43 .5468
G3 X14 .5172 Y43 .1833 I0 .4322 J -0.0865 G3 X14 .9124 Y42 .9473 I0 .5181 J0 .4189
G1 | X15 .075 Y42 .7429
G1 | X14 .893 Y42 .4826
G3 X14 .1961 Y42 .0762 I1 .1416 J -2.7589 G3 X14 .0616 Y41 .8328 I0 .2185 J -0.2795
G1 | X14 .1098 Y41 .6333
G1 | X14 .2616 Y41 .5248
G3 X16 .1263 Y41 .0887 I14 .2855 J56 .8827 G3 X16 .6581 Y41 .005 I0 .9934 J4 .5843 G1 X16 .7169 Y41 .0372
G3 X16 .8512 Y41 .407 I -1.8248 J0 .8721 G1 X16 .8512 Y41 .407
G4 P0
M280 P0 S20
G1 F6000
G1 X16 .2561 Y38 .0348
G4 P0
M280 P0 S120
G4 P0
G1 F6000 .000000
G3 X16 .4321 Y38 .427 I -0.76 J0 .5767 G3 X16 .5289 Y39 .4184 I -5.0274 J0 .9914 G3 X16 .2634 Y39 .8772 I -0.5292 J0 .
G3 X15 .0972 Y40 .2411 I -1.4 J -2.4363 G3 X13 .9615 Y40 .3102 I -2.098 J -25.1008 G1 X13 .8764 Y40 .2878

G1 X13 .8295 Y40 .2213
G3 X13 .7976 Y39 .9218 I1 .3917 J -0.2995 G1 X13 .9619 Y39 .6604
G3 X14 .7908 Y39 .4437 I0 .9689 J2 .0127 G2 X15 .6755 Y39 .2794 I -0.2338 J -3.7238
G1 | X15 .784 Y39 .1315
G1 | X15 .6517 Y38 .9635
G2 X14 .6606 Y38 .8599 I -0.8825 J3 .6492 G3 X13 .9008 Y38 .8143 I -0.1245 J -4.284 G1 X13 .7494 Y38 .7224
G3 X13 .6279 Y38 .4005 I0 .5202 J -0.3802 G3 X13 .6954 Y38 .1273 I0 .4291 J -0.039 G1 X13 .8501 Y38 .0297
G3 X15 .1324 Y37 .941 I1 .3805 J10 .6462 G3 X16 .1543 Y37 .9788 I0 .1146 J10 .7244
G1 | X16 .2561 Y38 .0348
G1 | X16 .2561 Y38 .0348
G4 P0
M280 P0 S20
G1 F6000
G1 X15 .9139 Y29 .5627
G4 P0
M280 P0 S120
G4 P0
G1 F6000 .000000
G1 | X15 .9072 Y29 .6295 F6000 .000000
G1 | X15 .9711 Y29 .7193
G2 X16 .8846 Y30 .2089 I1 .7334 J -2.1373 G2 X17 .2515 Y30 .1185 I0 .1088 J -0.3485 G1 X17 .2686 Y29 .8873
G2 X16 .8535 Y29 .5822 I -0.7033 J0 .5218 G2 X16 .1208 Y29 .4502 I -0.7846 J2 .2552
G1 | X15 .9139 Y29 .5627
G1 | X15 .9139 Y29 .5627
G4 P0
M280 P0 S20
G1 F6000
G1 X17 .463 Y28 .8436
G4 P0
M280 P0 S120
G4 P0
G1 F6000 .000000
G3 X17 .9396 Y29 .3338 I -0.5602 J1 .0215 G3 X18 .067 Y30 .0222 I -1.087 J0 .5571 G3 X17 .7857 Y31 .0666 I -3.4756 J -0.376 G3 X17 .4688 Y31 .3676 I -0.5215 J -0.2319 G3 X16 .9945 Y31 .3678 I -0.2374 J -0.6165 G3 X15 .0238 Y30 .4292 I5 .0308 J -13.1014 G1 X14 .945 Y30 .2216
G3 X15 .5031 Y29 . I6 .0753 J2 .0373
G3 X15 .6689 Y28 .7806 I1 .0467 J0 .6183 G3 X15 .8188 Y28 .668 I0 .4099 J0 .3898 G3 X16 .4971 Y28 .5408 I0 .5506 J1 .0644 G3 X17 .463 Y28 .8436 I -0.2756 J2 .5713 G1 X17 .463 Y28 .8436
G4 P0
M280 P0 S20
G1 F6000
G1 X18 .0808 Y27 .3603
G4 P0
M280 P0 S120
G4 P0
G1 F6000 .000000
G3 X18 .2056 Y27 .6321 I -0.1975 J0 .2553 G3 X18 .0473 Y28 .0137 I -0.6149 J -0.0316 G3 X17 .546 Y28 .1029 I -0.3082 J -0.2789 G3 X17 .2883 Y27 .6156 I0 .2263 J -0.4314 G3 X17 .571 Y27 .271 I0 .4089 J0 .0472
G3 X18 .0808 Y27 .3603 I0 .1701 J0 .5283 G1 X18 .0808 Y27 .3603
G4 P0

M280 P0 S20
G1 F6000
G1 X19 .5992 Y26 .5689
G4 P0
M280 P0 S120
G4 P0
G1 F6000 .000000
G3 X19 .8088 Y26 .7286 I -0.5726 J0 .9693 G1 X19 .8396 Y26 .801
G3 X19 .7112 Y27 .2538 I -0.8629 J0 .
G3 X18 .7831 Y28 .5149 I -8.1291 J -5.0109 G1 X18 .6458 Y28 .5779
G3 X18 .4214 Y28 .5169 I -0.0025 J -0.4343 G3 X18 .2051 Y28 .3649 I0 .8561 J -1.4486 G1 X18 .1842 Y28 .3206
G3 X18 .5939 Y26 .8356 I2 .8966 J0 .
G3 X19 .3153 Y26 .4261 I0 .7214 J0 .4308 G1 X19 .3562 Y26 .4357
G3 X19 .5992 Y26 .5681 I -1.7734 J3 .5452 G1 X19 .5992 Y26 .5689
G4 P0
M280 P0 S20
G1 F6000
G1 X17 .8573 Y25 .56
G4 P0
M280 P0 S120
G4 P0
G1 F6000 .000000
G3 X18 .0719 Y25 .7042 I -0.5196 J1 .0056
G1 | X18 .1015 Y25 .7681
G1 | X18 .0808 Y25 .8437
G3 X17 .5123 Y26 .7617 I -24.0808 J -14.276 G3 X16 .889 Y27 .5796 I -5.5773 J -3.6042 G1 X16 .7467 Y27 .6194
G3 X16 .4396 Y27 .43 I0 .2085 J -0.6817
G1 X16 .4054 Y27 .262
G3 X17 .2171 Y25 .611 I8 .9299 J3 .3652 G3 X17 .5351 Y25 .4337 I0 .318 J0 .1965 G1 X17 .6097 Y25 .4478
G3 X17 .8573 Y25 .56 I -0.9437 J2 .4122 G1 X17 .8573 Y25 .56
G4 P0
M280 P0 S20
G1 F6000
G1 X24 .9712 Y37 .4697
G4 P0
M280 P0 S120
G4 P0
G1 F6000 .000000
G1 X24 .8738 Y37 .5846 F6000 .000000
G3 X22 .4054 Y37 .8956 I -5.2048 J -31.3656 G2 X18 .6386 Y38 .2855 I9 .6103 J111 .2161
G1 | X18 .4613 Y38 .3718
G1 | X18 .4483 Y38 .4211
G2 X20 .4509 Y45 .597 I1041 .3235 J -286.7393 G3 X22 .4701 Y52 .777 I -2475.3274 J700 .0146
G1 | X22 .4645 Y52 .7971
G1 | X22 .4444 Y52 .8081
G3 X22 .2828 Y52 .8426 I -0.5909 J -2.3704
G1 X22 .1762 Y52 .7783
G3 X19 .816 Y45 .2266 I364 .676 J -118.1174 G3 X17 .5398 Y37 .5887 I1292 .7508 J -389.4247
G1 | X17 .5511 Y37 .544
G1 | X17 .5969 Y37 .5239
G3 X21 .1767 Y37 .3995 I14 .2359 J358 .1978 G2 X24 .7639 Y37 .2888 I -43.9889 J -1483.7202 G2 X24 .8677 Y37 .2812 I -0.0406 J -1.2655
G1 X24 .9312 Y37 .3144
G3 X24 .9712 Y37 .4697 I -0.2818 J0 .1553
G1 X24 .9712 Y37 .4697
G4 P0

M280 P0 S20
G1 F6000
G1 X24 .9712 Y38 .8795
G4 P0
M280 P0 S120
G4 P0
G1 F6000 .000000
G1 X24 .9027 Y39 .0252 F6000 .000000
G3 X24 .6608 Y39 .1371 I -0.3316 J -0.3995 G2 X23 .4242 Y39 .3914 I3 .746 J21 .3508 G2 X22 .364 Y39 .6796 I3 .7662 J15 .946 G2 X20 .3638 Y40 .4116 I6 .051 J19 .6332 G1 X20 .2534 Y40 .5786
G2 X20 .689 Y44 .1584 I14 .9282 J -0.
G2 X23 .2739 Y52 .8082 I90 .8864 J -22.4495 G1 X23 .2582 Y52 .8904
G3 X23 .0814 Y53 .0293 I -0.452 J -0.3934
G1 | X22 .8527 Y53 .1476
G1 | X21 .2629 Y46 .7603
G3 X19 .6891 Y40 .3712 I1319 .4179 J -328.4066 G3 X19 .6736 Y40 .2405 I0 .5282 J -0.1288
G3 X20 .2846 Y39 .4129 I0 .8701 J0 .003
G3 X24 .6608 Y38 .6849 I4 .8184 J15 .4477
G3 X24 .8995 Y38 .7499 I0 .0123 J0 .4255
G1 | X24 .9712 Y38 .8795
G1 | X24 .9712 Y38 .8795
G4 P0
M280 P0 S20
G1 F6000
G1 X24 .9712 Y39 .5041
G4 P0
M280 P0 S120
G4 P0
G1 F6000 .000000
G1 X25 .0515 Y39 .5893 F6000 .000000
G2 X27 .7439 Y39 .6696 I2 .6924 J -45.1099
G1 | X30 .5166 Y39 .6696
G1 | X30 .5166 Y39 .8466
G1 | X30 .4395 Y39 .9387
G3 X29 .8751 Y39 .962 I -0.3667 J -2.0374 G2 X26 .7371 Y39 .8496 I -2.5065 J26 .1163 G2 X24 .609 Y40 .0889 I0 .2935 J12 .1913 G2 X21 .2558 Y41 .0305 I4 .6761 J23 .094
G2 X20 .9983 Y41 .3976 I0 .1331 J0 .3671
G2 X21 .0082 Y41 .4793 I0 .3444 J -0.
G2 X22 .489 Y47 .5015 I1903 .913 J -464.9596 G3 X23 .8268 Y53 .5179 I -125.207 J30 .9976
G1 | X23 .6992 Y53 .6322
G1 | X23 .6654 Y53 .5965
G3 X22 .0469 Y47 .2761 I1698 .7824 J -438.4048 G3 X20 .462 Y40 .9908 I1708 .8132 J -434.222 G3 X20 .4223 Y40 .7362 I1 .3862 J -0.3468
G1 X20 .6179 Y40 .4353
G3 X23 .763 Y39 .5042 I8 .6655 J23 .4934
G3 X24 .8498 Y39 .3829 I1 .0864 J4 .8064
G1 | X24 .9712 Y39 .5043
G1 | X24 .9712 Y39 .5041
G4 P0
M280 P0 S20
G1 F6000
G1 X24 .5987 Y42 .3723
G4 P0
M280 P0 S120
G4 P0
G1 F6000 .000000
G2 X23 .7551 Y42 .5224 I0 .884 J7 .4119 G1 X23 .7478 Y42 .5747
G3 X24 .0984 Y43 .0847 I -0.3414 J0 .6101 G3 X23 .9055 Y43 .6649 I -0.6753 J0 .0976
G1 | X23 .8528 Y43 .6605
G1 | X23 .8124 Y43 .5345

G2 X23 .7785 Y43 .345 I -0.546 J0 .
G1 | X23 .7296 Y43 .311
G1 | X23 .6749 Y43 .3389
G1 | X23 .6469 Y43 .4251
G1 | X23 .6192 Y43 .5259
G3 X23 .5132 Y43 .65 I -0.4126 J -0.2449 G1 X23 .2574 Y43 .6155
G3 X23 .0675 Y43 .0122 I0 .8631 J -0.6033 G3 X23 .1393 Y42 .7207 I0 .6281 J0 .
G1 X23 .2579 Y42 .6489
G3 X23 .436 Y42 .6787 I -0. J0 .5484
G1 | X23 .5476 Y42 .7482
G1 | X23 .619 Y42 .7798
G1 | X23 .6469 Y42 .7532
G1 | X23 .6172 Y42 .6745
G2 X23 .4868 Y42 .5712 I -0.3504 J0 .3082 G2 X22 .9099 Y42 .7117 I -0.2099 J0 .3923 G2 X22 .8621 Y43 .4816 I0 .6193 J0 .4249 G2 X23 .1306 Y43 .7168 I0 .4338 J -0.2243 G2 X23 .6932 Y43 .7807 I0 .4163 J -1.1569 G3 X24 .0197 Y43 .7453 I1 .9177 J16 .1488 G3 X24 .7022 Y43 .6821 I5 .8736 J59 .7392 G2 X25 .3019 Y43 .5464 I -0.1966 J -2.2615
G1 | X25 .385 Y43 .4265
G1 | X25 .3006 Y43 .3273
G1 | X25 .1955 Y43 .3957
G1 | X25 .0148 Y43 .5891
G1 | X24 .8873 Y43 .4992
G2 X24 .8805 Y43 .4378 I -0.3433 J0 .0066 G2 X24 .8329 Y43 .2302 I -3.9994 J0 .8081
G1 | X24 .7796 Y43 .0233
G1 | X24 .9712 Y43 .1888
G1 | X25 .1627 Y43 .3543
G1 | X25 .1094 Y43 .1474
G3 X25 .066 Y42 .9392 I2 .1958 J -0.5663 G3 X25 .0498 Y42 .775 I1 .3568 J -0.217
G1 | X25 .0183 Y42 .7554
G1 | X24 .9616 Y42 .8143
G1 | X24 .8703 Y42 .9153
G1 | X24 .8026 Y42 .8971
G3 X24 .7373 Y42 .5927 I0 .381 J -0.2409
G1 | X24 .8612 Y42 .4852
G1 | X24 .9887 Y42 .5141
G3 X25 .1649 Y42 .6301 I -0.3324 J0 .6969
G1 | X25 .251 Y42 .6589
G1 | X25 .2749 Y42 .6221
G3 X25 .2284 Y42 .4689 I1 .3379 J -0.4897
G1 | X25 .2195 Y42 .3945
G1 | X25 .1752 Y42 .3487
G2 X24 .5987 Y42 .3728 I -0.1311 J3 .7678 G1 X24 .5987 Y42 .3723
G4 P0
M280 P0 S20
G1 F6000
G1 X24 .4244 Y42 .6146
G4 P0
M280 P0 S120
G4 P0
G1 F6000 .000000
G3 X24 .6157 Y43 .5025 I -2.7588 J1 .0587
G1 | X24 .4839 Y43 .6421
G1 | X24 .3672 Y43 .5623
G3 X24 .1825 Y42 .869 I3 .006 J -1.1719 G3 X24 .1863 Y42 .5365 I1 .0301 J -0.1545
G1 | X24 .2494 Y42 .4834
G1 | X24 .3509 Y42 .5173
G1 | X24 .4244 Y42 .6145
G1 | X24 .4244 Y42 .6146
G4 P0
M280 P0 S20
G1 F6000

G1 X24 .6608 Y45 .0274
G4 P0
M280 P0 S120
G4 P0
G1 F6000 .000000
G2 X24 .3011 Y45 .144 I0 .0549 J0 .7824
G1 | X24 .3013 Y45 .2513
G1 | X24 .3498 Y45 .3148
G3 X24 .4304 Y45 .6907 I -2.4799 J0 .7281 G3 X24 .4533 Y46 .2063 I -2.7758 J0 .3818
G1 | X24 .4025 Y46 .2733
G1 | X24 .3376 Y46 .2521
G3 X24 .0032 Y45 .7181 I3 .9649 J -2.8545 G2 X23 .6753 Y45 .1558 I -8.685 J4 .6873
G1 | X23 .6359 Y45 .1333
G1 | X23 .6057 Y45 .1574
G2 X23 .5242 Y45 .6906 I5 .7471 J1 .1509 G3 X23 .4362 Y46 .2372 I -5.0731 J -0.5371
G1 | X23 .3803 Y46 .3527
G1 | X23 .3935 Y46 .4098
G2 X23 .6055 Y46 .4562 I0 .2121 J -0.4612 G2 X23 .806 Y46 .4047 I -0. J -0.4163
G1 | X23 .8184 Y46 .3393
G1 | X23 .7679 Y46 .212
G3 X23 .794 Y45 .9462 I0 .8379 J -0.0519
G1 | X23 .8667 Y45 .67
G1 | X24 .0085 Y45 .9415
G3 X24 .1084 Y46 .2113 I -1.0079 J0 .5267
G1 | X24 .0929 Y46 .3056
G1 | X24 .3009 Y46 .6426
G2 X25 .6954 Y46 .1596 I -0.2719 J -3.0396 G2 X25 .9503 Y45 .4154 I -0.347 J -0.5346 G2 X25 .2853 Y44 .9819 I -0.6129 J0 .2134 G3 X25 .0953 Y44 .9962 I -8.1588 J -106.571 G3 X24 .6608 Y45 .0277 I -6.6808 J -89.3583 G1 X24 .6608 Y45 .0274
G4 P0
M280 P0 S20
G1 F6000
G1 X24 .9643 Y45 .5499
G4 P0
M280 P0 S120
G4 P0
G1 F6000 .000000
G3 X25 .0137 Y46 .1338 I -2.2645 J0 .4856
G1 | X24 .9364 Y46 .2079
G1 | X24 .8556 Y46 .1501
G3 X24 .6751 Y45 .4423 I4 .3666 J -1.4903 G3 X24 .6829 Y45 .1836 I0 .6392 J -0.1101
G1 | X24 .7482 Y45 .1319
G1 | X24 .833 Y45 .1836
G3 X24 .9643 Y45 .5499 I -1.3032 J0 .674 G1 X24 .9643 Y45 .5499
G4 P0
M280 P0 S20
G1 F6000
G1 X25 .5424 Y45 .3927
G4 P0
M280 P0 S120
G4 P0
G1 F6000 .000000
G3 X25 .6332 Y45 .9269 I -1.5383 J0 .5363
G1 | X25 .5434 Y46 .0883
G1 | X25 .42 Y46 .0553
G3 X25 .2616 Y45 .5666 I1 .2511 J -0.6756 G3 X25 .2653 Y45 .1857 I1 .3385 J -0.1774
G1 | X25 .3278 Y45 .132
G1 | X25 .4205 Y45 .1758
G3 X25 .5425 Y45 .3927 I -0.5459 J0 .4497 G1 X25 .5424 Y45 .3927
G4 P0

M280 P0 S20
G1 F6000
G1 X26 .4081 Y45 .5044
G4 P0
M280 P0 S120
G4 P0
G1 F6000 .000000
G3 X26 .3538 Y45 .6187 I -0.7677 J -0.2948
G1 | X26 .3368 Y45 .6285
G1 | X26 .3198 Y45 .6187
G3 X26 .2655 Y45 .5044 I0 .7069 J -0.4058
G1 | X26 .2722 Y45 .4176
G1 | X26 .3368 Y45 .3802
G1 | X26 .4015 Y45 .4176
G1 | X26 .4081 Y45 .5044
G1 | X26 .4081 Y45 .5044
G4 P0
M280 P0 S20
G1 F6000
G1 X26 .5734 Y44 .8581
G4 P0
M280 P0 S120
G4 P0
G1 F6000 .000000
G1 | X26 .4611 Y44 .9336 F6000 .000000
G1 | X26 .4401 Y45 .061
G1 | X26 .4098 Y45 .1632
G1 | X26 .2863 Y45 .2013
G1 | X26 .1458 Y45 .1314
G1 | X26 .1128 Y45 .0285
G1 | X26 .0206 Y44 .8909
G1 | X25 .8402 Y44 .9664
G1 | X25 .8309 Y45 .0259
G1 | X25 .8607 Y45 .0492
G1 | X25 .9137 Y45 .079
G3 X26 .2127 Y45 .6286 I -5.6133 J3 .4097 G2 X26 .5068 Y46 .1859 I8 .0718 J -3.9046
G1 | X26 .545 Y46 .208
G1 | X26 .5763 Y46 .1836
G2 X26 .6862 Y45 .6493 I -5.926 J -1.4975 G3 X26 .7887 Y45 .0943 I11 .4211 J1 .8216 G3 X26 .8339 Y44 .9458 I0 .8587 J0 .1803
G1 | X26 .8503 Y44 .8345
G1 | X26 .8216 Y44 .8121
G2 X26 .7508 Y44 .8242 I0 .3339 J2 .1713 G2 X26 .5733 Y44 .8579 I6 .3947 J34 .1229 G1 X26 .5734 Y44 .8581
G4 P0
M280 P0 S20
G1 F6000
G1 X26 .2984 Y47 .6599
G4 P0
M280 P0 S120
G4 P0
G1 F6000 .000000
G1 | X26 .3487 Y47 .785 F6000 .000000
G1 | X26 .3141 Y47 .8779
G1 | X26 .0727 Y47 .9239
G1 | X25 .9946 Y47 .7385
G1 | X25 .9802 Y47 .6576
G1 | X25 .8866 Y47 .6151
G1 | X25 .8386 Y47 .6791
G2 X26 .067 Y48 .2331 I2 .696 J -0.7871 G2 X26 .4153 Y48 .8043 I5 .9029 J -3.2077
G1 | X26 .4624 Y48 .8144
G1 | X26 .4988 Y48 .7626
G2 X26 .5806 Y48 .2592 I -5.1338 J -1.0935 G3 X26 .668 Y47 .7531 I4 .3874 J0 .4965
G1 | X26 .7258 Y47 .6366
G1 | X26 .713 Y47 .5792
G2 X26 .5024 Y47 .5324 I -0.2106 J0 .4507

G2 X26 .3099 Y47 .5878 I0 . J0 .3622
G1 | X26 .2984 Y47 .6601
G1 | X26 .2984 Y47 .6599
G4 P0
M280 P0 S20
G1 F6000
G1 X26 .2955 Y48 .1579
G4 P0
M280 P0 S120
G4 P0
G1 F6000 .000000
G1 | X26 .264 Y48 .2306 F6000 .000000
G1 | X26 .2127 Y48 .2357
G1 | X26 .1495 Y48 .1737
G1 | X26 .1299 Y48 .1066
G1 | X26 .1534 Y48 .0523
G1 | X26 .2127 Y48 .0288
G1 | X26 .2662 Y48 .058
G1 | X26 .2955 Y48 .1579
G1 | X26 .2955 Y48 .1579
G4 P0
M280 P0 S20
G1 F6000
G1 X25 .3038 Y48 .0844
G4 P0
M280 P0 S120
G4 P0
G1 F6000 .000000
G3 X25 .1126 Y48 .3704 I -0.8139 J -0.3373 G1 X25 .0345 Y48 .3534
G3 X24 .9875 Y48 .1501 I0 .7561 J -0.2822 G3 X24 .9925 Y47 .9256 I0 .9302 J -0.0914
G1 | X24 .9518 Y47 .7616
G1 | X24 .8268 Y47 .698
G1 | X24 .743 Y47 .7455
G1 | X24 .7524 Y47 .8222
G3 X25 .0862 Y48 .4625 I -0.8491 J0 .85 G3 X24 .9453 Y48 .9103 I -0.5002 J0 .0887 G1 X24 .8358 Y48 .8964
G3 X24 .6829 Y48 .4647 I1 .0355 J -0.6099 G2 X24 .4596 Y47 .9211 I -1.2177 J0 .1826 G2 X24 .1835 Y47 .7809 I -0.276 J0 .2016 G1 X23 .9344 Y47 .9533
G2 X23 .8923 Y48 .5544 I0 .9851 J0 .3709 G3 X23 .9528 Y48 .9456 I -2.878 J0 .6451
G1 | X23 .9332 Y49 .0277
G1 | X23 .9476 Y49 .0703
G2 X24 .1386 Y49 .1052 I0 .191 J -0.5037 G2 X24 .3569 Y49 .0705 I0 . J -0.7031
G1 | X24 .3918 Y49 .0224
G1 | X24 .3694 Y48 .9621
G1 | X24 .3204 Y48 .9396
G3 X23 .9812 Y48 .6648 I0 . J -0.3468
G3 X24 .1079 Y47 .9371 I0 .9711 J -0.2058 G1 X24 .2715 Y47 .872
G3 X24 .4778 Y48 .0353 I -0.0849 J0 .3192 G3 X24 .5405 Y48 .2147 I -0.5437 J0 .2909 G3 X24 .5841 Y48 .614 I -2.7062 J0 .4974
G1 | X24 .5987 Y49 .0212
G1 | X24 .9138 Y49 .0219
G2 X25 .1702 Y48 .9321 I0 .0008 J -0.4088 G2 X25 .4036 Y48 .6294 I -0.5062 J -0.6316
G1 | X25 .5784 Y48 .2362
G1 | X25 .6443 Y48 .4796
G3 X25 .6673 Y48 .7137 I -0.6858 J0 .1856
G1 | X25 .6203 Y48 .8313
G1 | X25 .625 Y48 .8953
G1 | X25 .741 Y48 .9397
G1 | X25 .8442 Y48 .8726
G1 | X25 .8417 Y48 .7121
G3 X25 .7563 Y48 .4772 I1 .1063 J -0.5353

G3 X25 .6747 Y48 .05 I3 .6135 J -0.911 G2 X25 .5938 Y47 .6428 I -3.1199 J0 .4087
G1 | X25 .5581 Y47 .6154
G1 | X25 .5153 Y47 .6409
G2 X25 .3038 Y48 .0846 I4 .1686 J2 .259 G1 X25 .3038 Y48 .0844
G4 P0
M280 P0 S20
G1 F6000
G1 X25 .2926 Y50 .439
G4 P0
M280 P0 S120
G4 P0
G1 F6000 .000000
G2 X25 .1812 Y50 .6357 I0 .2996 J0 .2996 G2 X25 .1631 Y50 .9563 I0 .8294 J0 .2077 G3 X25 .1585 Y51 .1483 I -0.6121 J0 .0816
G1 | X25 .1272 Y51 .1536
G1 | X25 .0212 Y51 .0506
G2 X24 .8519 Y51 .0087 I -0.1693 J0 .322
G1 | X24 .7013 Y50 .9532
G1 | X24 .6052 Y50 .798
G3 X24 .5781 Y50 .5913 I0 .8748 J -0.2196
G1 | X24 .6009 Y50 .5083
G1 | X24 .5863 Y50 .4648
G2 X24 .3965 Y50 .4293 I -0.1898 J0 .4899 G2 X24 .1781 Y50 .4641 I0 . J0 .7031
G1 | X24 .1433 Y50 .5121
G1 | X24 .1658 Y50 .5724
G1 | X24 .2153 Y50 .5949
G3 X24 .5729 Y50 .8876 I0 . J0 .3648
G3 X24 .4324 Y51 .6718 I -1.0626 J0 .2144 G1 X24 .4619 Y51 .7291
G2 X24 .8754 Y51 .7024 I0 .1071 J -1.5571 G2 X25 .0943 Y51 .6093 I -0.1163 J -0.5774
G1 | X25 .1829 Y51 .4894
G1 | X25 .2609 Y51 .426
G1 | X25 .3896 Y51 .4682
G2 X25 .9157 Y51 .544 I0 .3194 J -0.353 G2 X26 .2125 Y51 .0715 I -0.2278 J -0.4725 G2 X25 .8527 Y50 .3875 I -0.8301 J0 .
G2 X25 .2924 Y50 .4389 I -0.2492 J0 .3625 G1 X25 .2926 Y50 .439
G4 P0
M280 P0 S20
G1 F6000
G1 X25 .9225 Y51 .0059
G4 P0
M280 P0 S120
G4 P0
G1 F6000 .000000
G3 X25 .8933 Y51 .4093 I -0.8402 J0 .1419 G1 X25 .7614 Y51 .5053
G3 X25 .3992 Y51 .228 I0 . J -0.3753
G3 X25 .4844 Y50 .4811 I0 .9837 J -0.2661
G1 | X25 .5837 Y50 .4258
G1 | X25 .7202 Y50 .4963
G3 X25 .8349 Y50 .6922 I -0.5837 J0 .4733 G3 X25 .9225 Y51 .0056 I -1.4385 J0 .5712 G1 X25 .9225 Y51 .0059
G4 P0
M280 P0 S20
G1 F6000
G1 X26 .2955 Y50 .2638
G4 P0
M280 P0 S120
G4 P0
G1 F6000 .000000
G2 X26 .1785 Y50 .32 I0 .141 J0 .4432
G1 X26 .1832 Y50 .3384
G3 X26 .5478 Y50 .6624 I -0.0364 J0 .4081

G3 X26 .4126 Y51 .434 I -1.0333 J0 .2166 G1 X26 .4882 Y51 .5662
G2 X27 .0458 Y51 .4188 I -0.0272 J -1.2313 G1 X27 .1927 Y51 .1917
G2 X27 .0818 Y50 .8955 I -0.3809 J -0.0262 G1 X27 .0045 Y50 .7112
G3 X27 .0775 Y50 .4078 I0 .6432 J -0.0057
G1 | X27 .0902 Y50 .2445
G1 | X27 .0008 Y50 .1802
G1 | X26 .8549 Y50 .2418
G2 X26 .7484 Y50 .4395 I0 .2932 J0 .2855 G3 X26 .6723 Y50 .5888 I -0.3237 J -0.0711
G1 | X26 .6195 Y50 .5844
G1 | X26 .5787 Y50 .4658
G3 X26 .5927 Y50 .3251 I0 .3503 J -0.0362 G1 X26 .5485 Y50 .2498
G2 X26 .2956 Y50 .263 I -0.1015 J0 .4857 G1 X26 .2955 Y50 .2638
G4 P0
M280 P0 S20
G1 F6000
G1 X26 .8748 Y51 .0501
G4 P0
M280 P0 S120
G4 P0
G1 F6000 .000000
G2 X26 .877 Y51 .1741 I3 .568 J -0.
G2 X26 .881 Y51 .2343 I0 .9299 J -0.0323
G1 | X26 .8031 Y51 .2876
G1 | X26 .6897 Y51 .1363
G3 X26 .7017 Y50 .969 I0 .3198 J -0.0611
G1 | X26 .7621 Y50 .9259
G1 | X26 .8402 Y50 .9604
G1 | X26 .8748 Y51 .0501
G1 | X26 .8748 Y51 .0501
G4 P0
M280 P0 S20
G1 F6000
G1 X27 .9507 Y51 .63
G4 P0
M280 P0 S120
G4 P0
G1 F6000 .000000
G1 | X27 .9507 Y52 .6646
G1 | X35 .9792 Y52 .6646
G1 | X44 .0076 Y52 .6646
G1 | X44 .0076 Y51 .63
G1 | X44 .0076 Y50 .5954
G1 | X35 .9792 Y50 .5954
G1 | X27 .9507 Y50 .5954
G1 | X27 .9507 Y51 .63
G4 P0
M280 P0 S20
G1 F6000
G1 X24 .8884 Y51 .3861
G4 P0
M280 P0 S120
G4 P0
G1 F6000 .000000
G3 X24 .8552 Y51 .5548 I -0.4454 J0 .
G1 | X24 .8056 Y51 .5881
G1 | X24 .7577 Y51 .5533
G3 X24 .7229 Y51 .3349 I0 .6675 J -0.2184 G3 X24 .7597 Y51 .1478 I0 .4935 J -0.
G1 | X24 .8056 Y51 .1329
G1 | X24 .8588 Y51 .2004
G3 X24 .8884 Y51 .3861 I -0.5682 J0 .1857 G1 X24 .8884 Y51 .3861
G4 P0
M280 P0 S20
G1 F6000

G1 X30 .8402 Y45 .0111
G4 P0
M280 P0 S120
G4 P0
G1 F6000 .000000
G2 X30 .1819 Y45 .7854 I0 .4533 J1 .0523 G2 X30 .3737 Y46 .8765 I1 .3208 J0 .3303 G2 X31 .474 Y47 .4629 I1 .1023 J -0.7428 G2 X33 .2239 Y46 .8815 I0 .0045 J -2.9106 G3 X34 .143 Y46 .2892 I4 .6025 J6 .132 G3 X34 .9837 Y45 .9175 I2 .6026 J4 .7513
G1 | X35 .524 Y45 .7317
G1 | X35 .2757 Y45 .632
G2 X33 .8491 Y45 .3582 I -1.4148 J3 .5182 G2 X32 .733 Y45 .64 I0 .0074 J2 .3805
G1 | X32 .577 Y45 .6746
G1 | X32 .5162 Y45 .6282
G2 X32 .4641 Y45 .5295 I -0.3278 J0 .1097 G2 X32 .2174 Y45 .2332 I -3.2525 J2 .4583 G2 X31 .9215 Y45 .015 I -0.7047 J0 .6458 G2 X31 .546 Y44 .9156 I -0.4561 J0 .9641 G2 X31 .1445 Y44 .9281 I -0.1427 J1 .883 G2 X30 .8402 Y45 .0127 I0 .1621 J1 .1719 G1 X30 .8402 Y45 .0111
G4 P0
M280 P0 S20
G1 F6000
G1 X31 .9434 Y45 .2286
G4 P0
M280 P0 S120
G4 P0
G1 F6000 .000000
G3 X32 .217 Y45 .5043 I -0.2865 J0 .5578 G3 X32 .3375 Y46 .0111 I -1.0059 J0 .5068 G3 X31 .9886 Y46 .4812 I -0.4912 J0 .
G3 X31 .4139 Y46 .2906 I -0.1522 J -0.5028 G2 X31 .1944 Y46 .1593 I -0.2673 J0 .1976 G1 X31 .0959 Y46 .2445
G2 X31 .4236 Y46 .6868 I0 .4624 J0 .
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

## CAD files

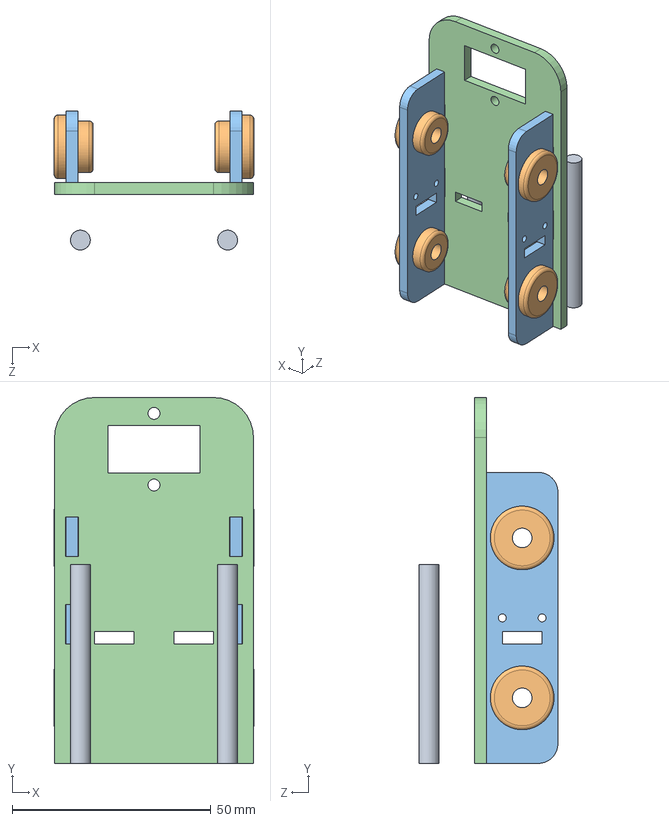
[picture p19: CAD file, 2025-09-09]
SLDPRT/EJE Z.SLDASM
50.2 x 92.0 x 34.9 mm
SoporteZ_CNC
SoporteTZ_CNC x 2
Bujepr_CNC x 4
CilindroY_CNC x 2

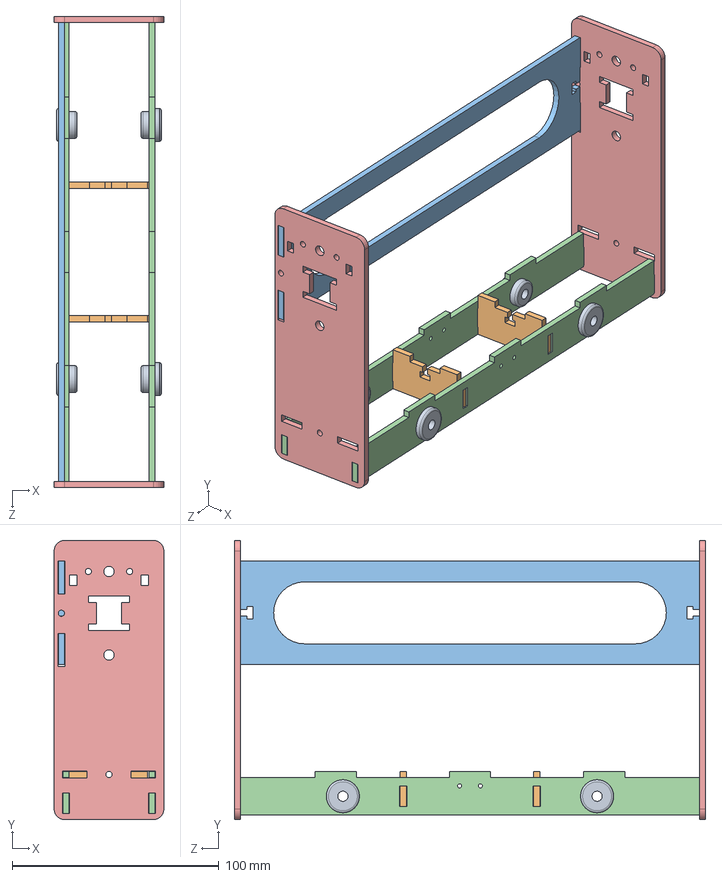
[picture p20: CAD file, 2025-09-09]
SLDPRT/EJE Y.SLDASM
53.1 x 135.0 x 228.0 mm
SoporteY_CNC x 2
SoporteBuje_CNC x 2
FronteY_CNC
SoportePequeno_CNC x 2
Bujepr_CNC x 4

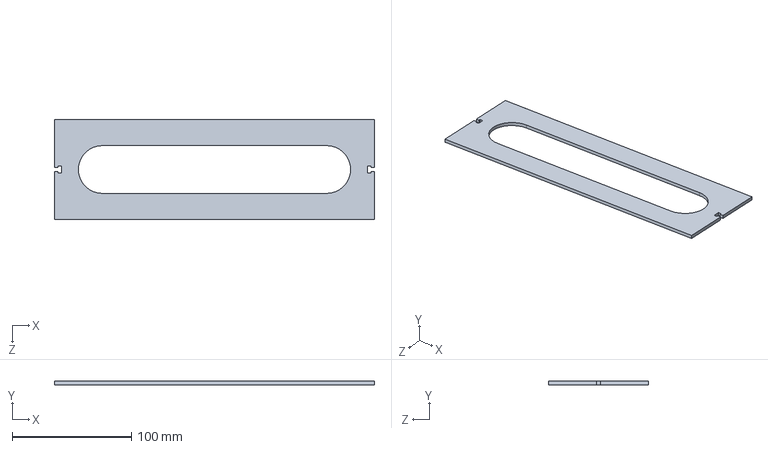
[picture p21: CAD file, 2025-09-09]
SLDPRT/Soporte_CNC.SLDPRT
268.0 x 3.00 x 84.0 mm

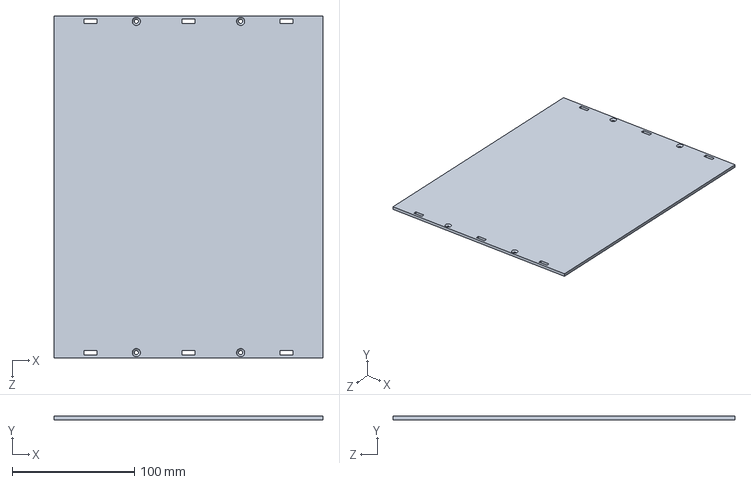
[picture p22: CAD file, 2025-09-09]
SLDPRT/Base_CNC.SLDPRT
220.0 x 3.00 x 280.0 mm

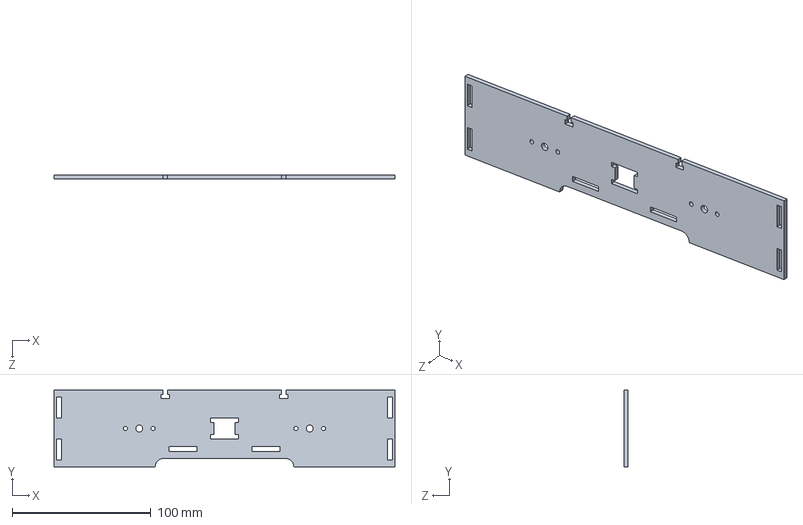
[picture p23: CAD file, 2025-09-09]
SLDPRT/Frontales_CNC.SLDPRT
246.0 x 55.2 x 3.00 mm

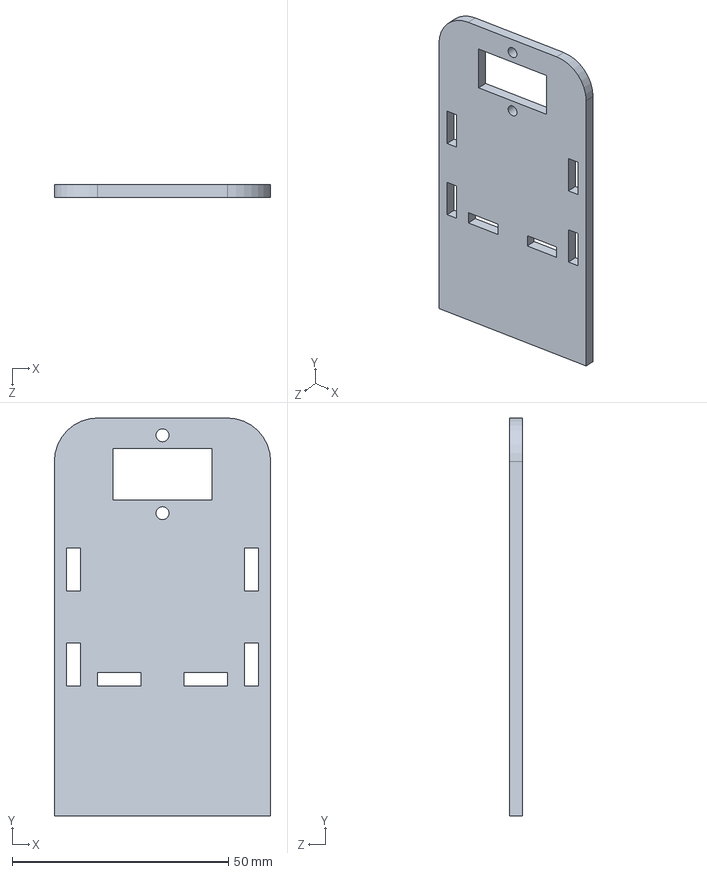
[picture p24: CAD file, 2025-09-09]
SLDPRT/SoporteZ_CNC.SLDPRT
50.0 x 92.0 x 3.00 mm

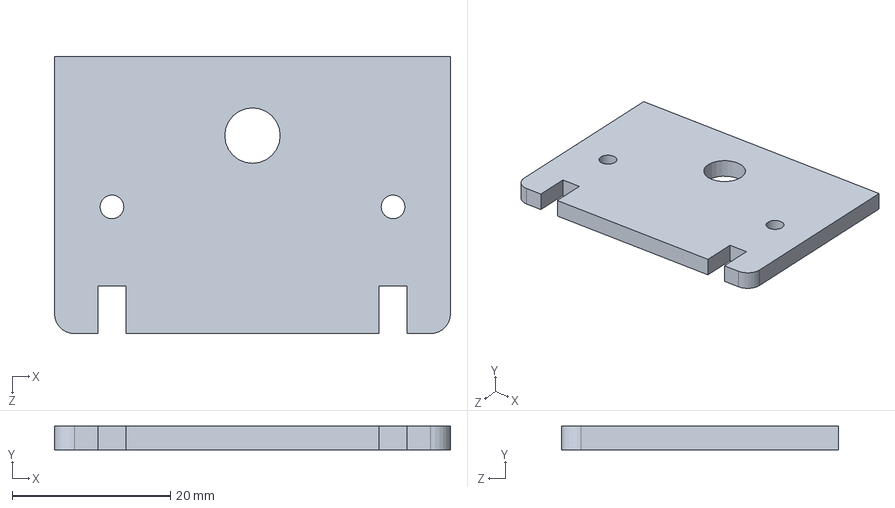
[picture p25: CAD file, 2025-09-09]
SLDPRT/BaseMotor_CNC.SLDPRT
50.0 x 3.00 x 35.0 mm

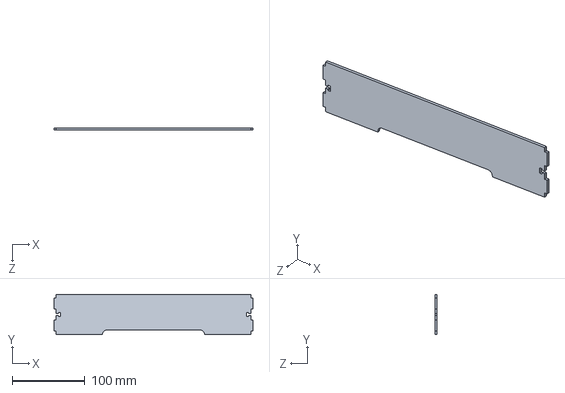
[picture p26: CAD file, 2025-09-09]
SLDPRT/Laterales_CNC.SLDPRT
274.0 x 55.2 x 3.00 mm

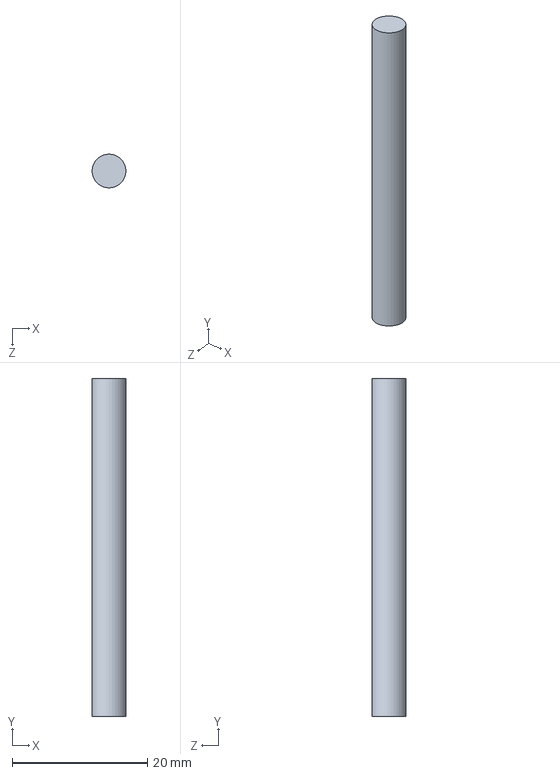
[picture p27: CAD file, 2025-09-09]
SLDPRT/CilindroY_CNC.SLDPRT
4.98 x 50.0 x 5.00 mm

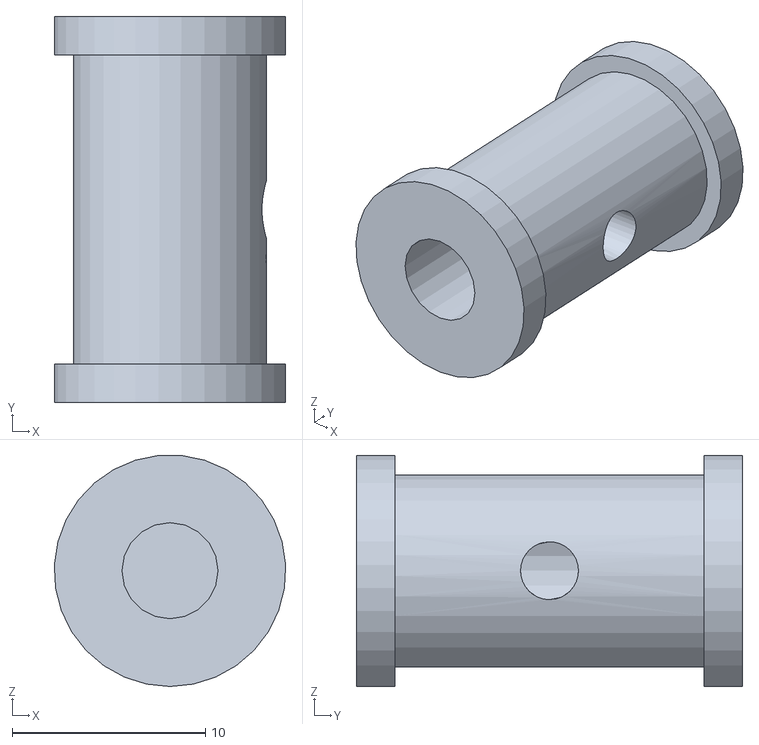
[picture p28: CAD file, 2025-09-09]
SLDPRT/PONCESEX.STL
12.0 x 20.0 x 12.0

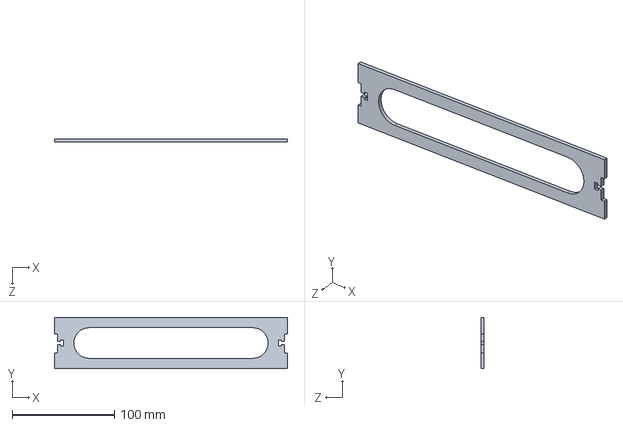
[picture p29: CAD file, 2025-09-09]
SLDPRT/FronteY_CNC.SLDPRT
228.0 x 50.0 x 3.00 mm

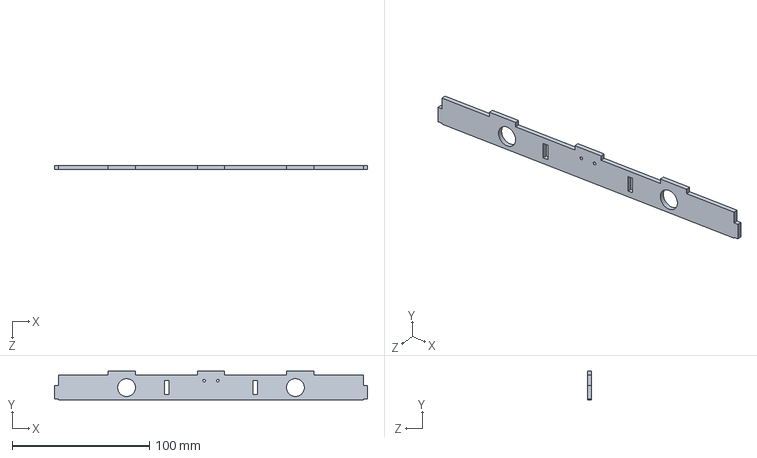
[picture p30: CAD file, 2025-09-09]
SLDPRT/SoporteBuje_CNC.SLDPRT
228.0 x 21.0 x 3.00 mm

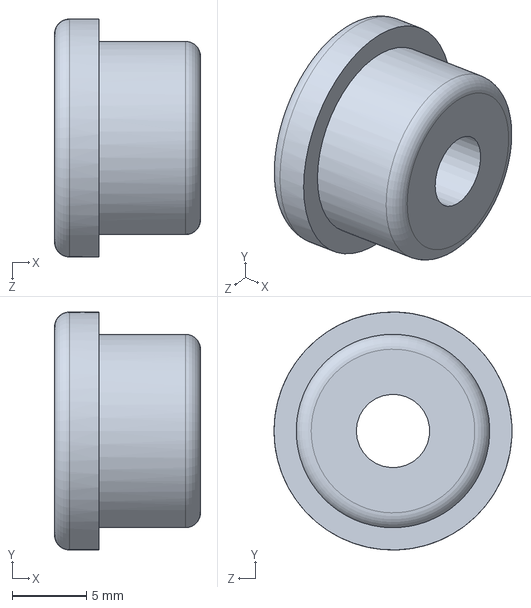
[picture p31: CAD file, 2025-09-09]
SLDPRT/Bujepr_CNC.SLDPRT
9.82 x 16.0 x 16.0 mm

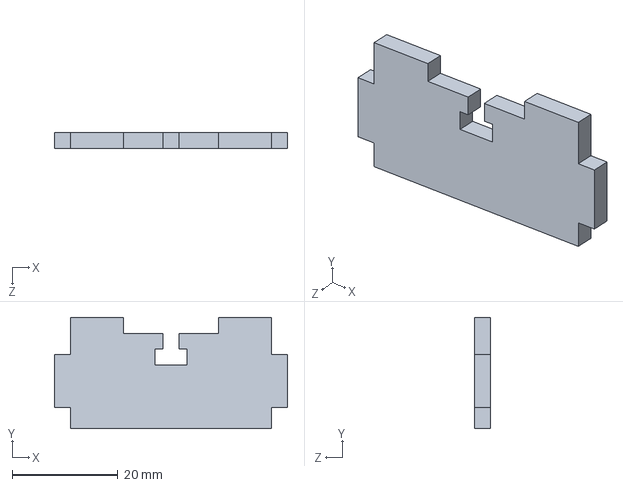
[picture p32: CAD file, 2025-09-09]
SLDPRT/SoportePequeno_CNC.SLDPRT
44.0 x 21.0 x 3.00 mm

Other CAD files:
SLDPRT/CNC_FINAL.SLDASM
SLDPRT/Buje_Motor_CNC.SLDPRT
SLDPRT/SoporteTZ_CNC.SLDPRT
SLDPRT/SoporteY_CNC.SLDPRT
SLDPRT/BASERODAMIENTO_CNC.SLDPRT
SLDPRT/BaseLapiz_CNC.SLDPRT
SLDPRT/BaseY.SLDPRT
SLDPRT/Base_Motor_CNC.SLDPRT
SLDPRT/Blueprints/BASERODAMIENTO_CNC.SLDDRW
SLDPRT/Blueprints/BaseLapiz_CNC.SLDDRW
SLDPRT/Blueprints/BaseY.SLDDRW
SLDPRT/Blueprints/Base_CNC.SLDDRW
SLDPRT/Blueprints/Base_Motor_CNC.SLDDRW
SLDPRT/Blueprints/Buje_Motor_CNC.SLDDRW
SLDPRT/Blueprints/Bujepr_CNC.SLDDRW
SLDPRT/Blueprints/CNC_FINAL.SLDDRW
SLDPRT/Blueprints/CilindroX_CNC.SLDDRW
SLDPRT/Blueprints/CilindroY_CNC.SLDDRW
SLDPRT/Blueprints/EJE Y.SLDDRW
SLDPRT/Blueprints/EJE Z.SLDDRW
SLDPRT/Blueprints/EjeCY_CNC.SLDDRW
SLDPRT/Blueprints/EjeMovil_CNC.SLDDRW
SLDPRT/Blueprints/Frontales_CNC.SLDDRW
SLDPRT/Blueprints/FronteY_CNC.SLDDRW
SLDPRT/Blueprints/Laterales_CNC.SLDDRW
SLDPRT/Blueprints/SoporteBuje_CNC.SLDDRW
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

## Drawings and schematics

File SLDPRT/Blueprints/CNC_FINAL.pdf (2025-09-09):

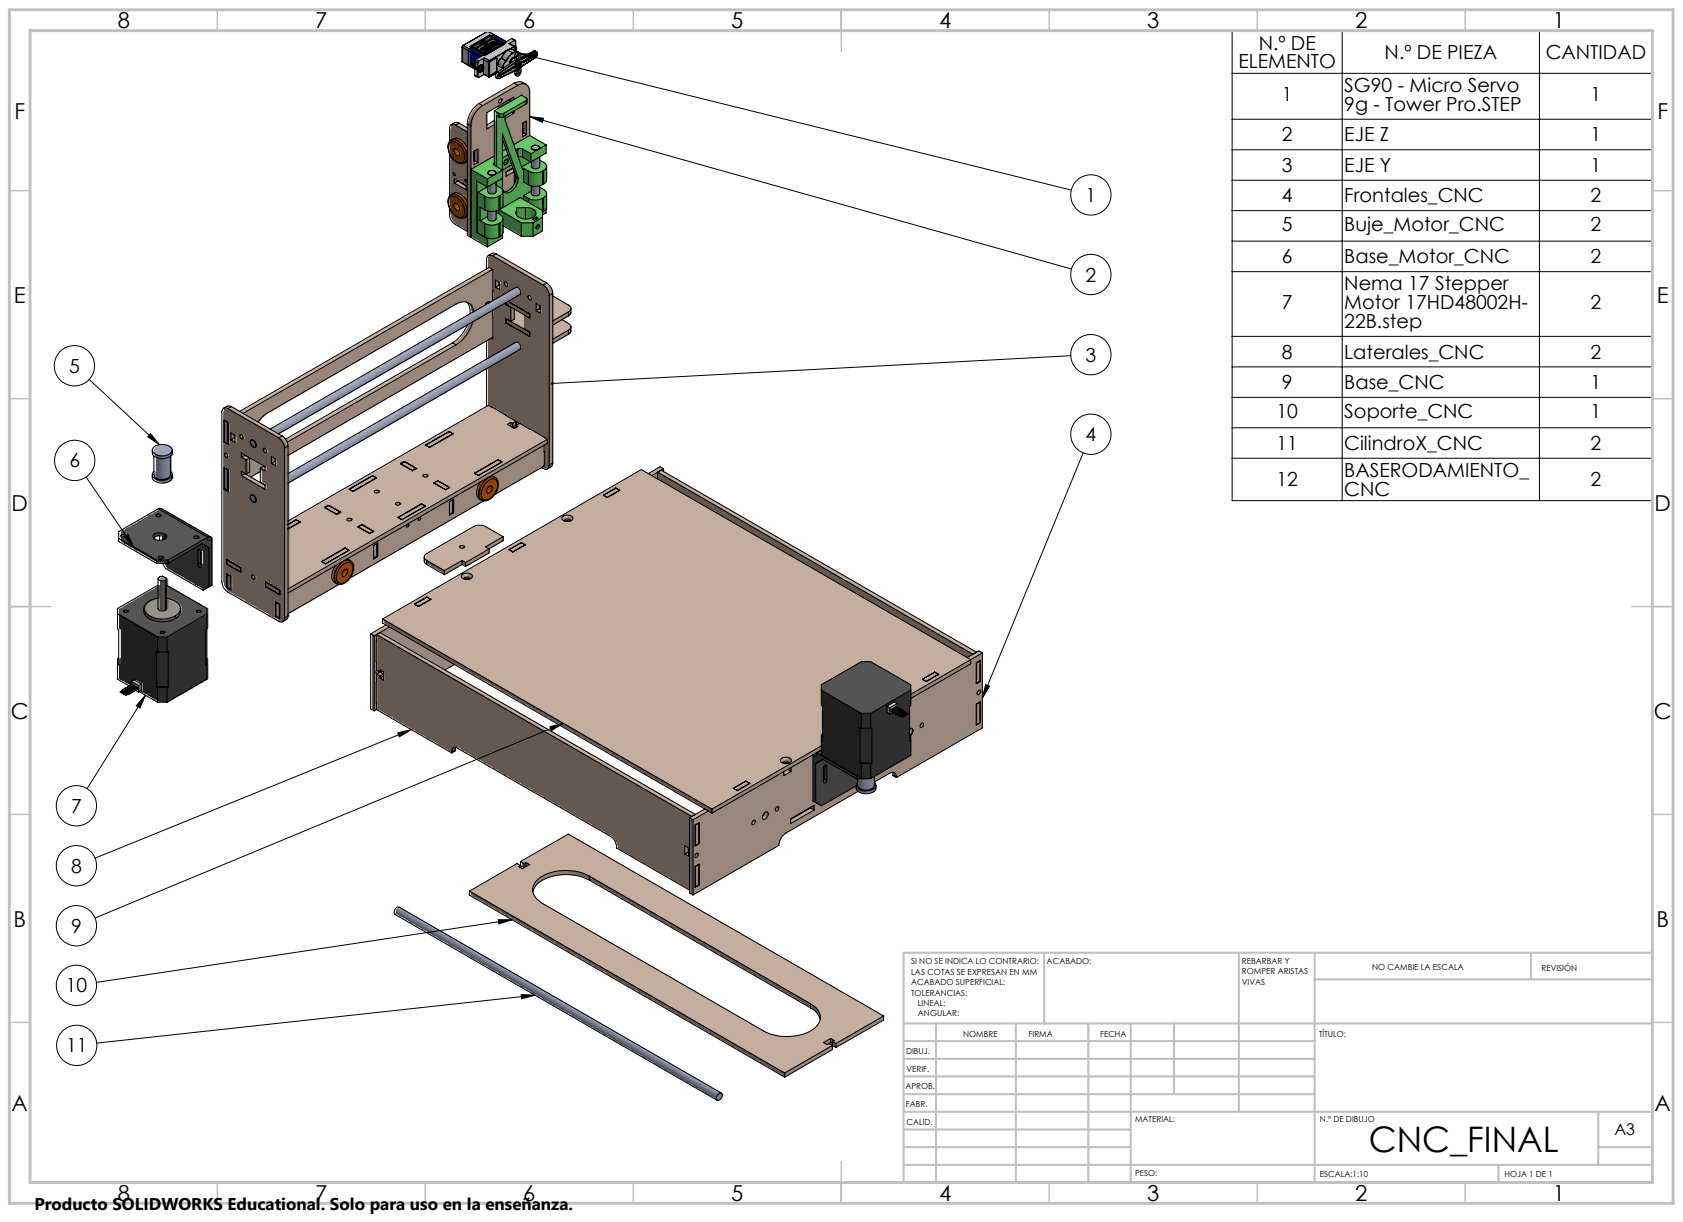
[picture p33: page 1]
ACABADO:; REBARBAR Y; ROMPER ARISTAS; NO CAMBIE LA ESCALA; REVISIÓN; ESCALA:1:10; HOJA 1 DE 1

N.º DE ELEMENTO | N.º DE PIEZA | CANTIDAD
1 | SG90 - Micro Servo 9g - Tower Pro.STEP | 1
2 | EJE Z | 1
3 | EJE Y | 1
4 | Frontales_CNC | 2
5 | Buje_Motor_CNC | 2
6 | Base_Motor_CNC | 2
7 | Nema 17 Stepper Motor 17HD48002H-22B.step | 2

8 | Laterales_CNC | 2
9 | Base_CNC | 1
10 | Soporte_CNC | 1
11 | CilindroX_CNC | 2
12 | BASERODAMIENTO_ CNC | 2

SI NO SE INDICA LO CONTRARIO:
LAS COTAS SE EXPRESAN EN MM
ACABADO SUPERFICIAL:
TOLERANCIAS:
LINEAL:
ANGULAR:

NOMBRE | FIRMA | FECHA | | | | TÍTULO:

DIBUJ.
VERIF.
APROB.
FABR.
CALID. | | | | MATERIAL: | N.º DE DIBUJO CNC_FINAL | A3

Producto SOLIDWORKS Educational. Solo para uso en la enseñanza.

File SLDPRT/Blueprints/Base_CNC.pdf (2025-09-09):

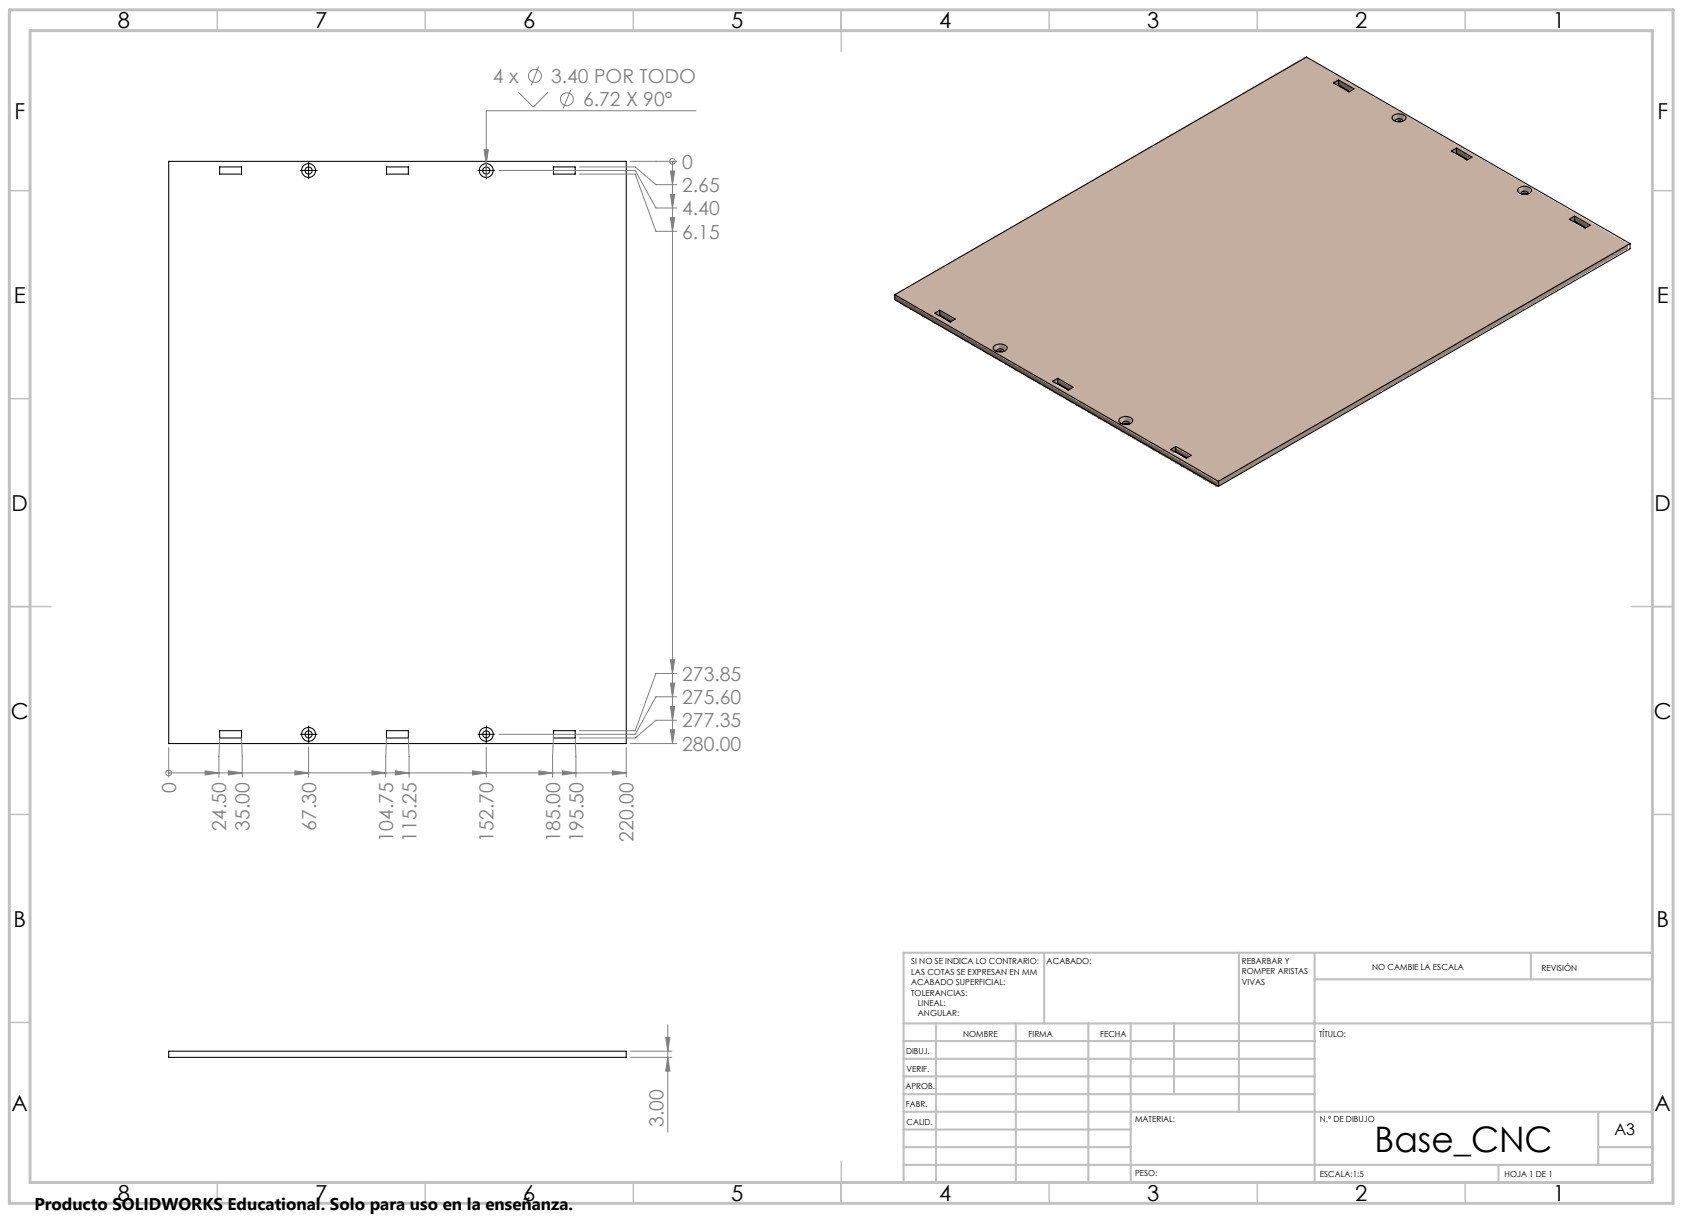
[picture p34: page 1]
3.40 POR TODO; ACABADO:; REBARBAR Y; ROMPER ARISTAS; NO CAMBIE LA ESCALA; REVISIÓN; ESCALA:1:5; HOJA 1 DE 1

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

NOMBRE | FIRMA | FECHA | | | | TÍTULO:

DIBUJ.
VERIF.
APROB.
FABR.
CALID. | | | | MATERIAL: | N.º DE DIBUJO Base_CNC | A3

Producto SOLIDWORKS Educational. Solo para uso en la enseñanza.

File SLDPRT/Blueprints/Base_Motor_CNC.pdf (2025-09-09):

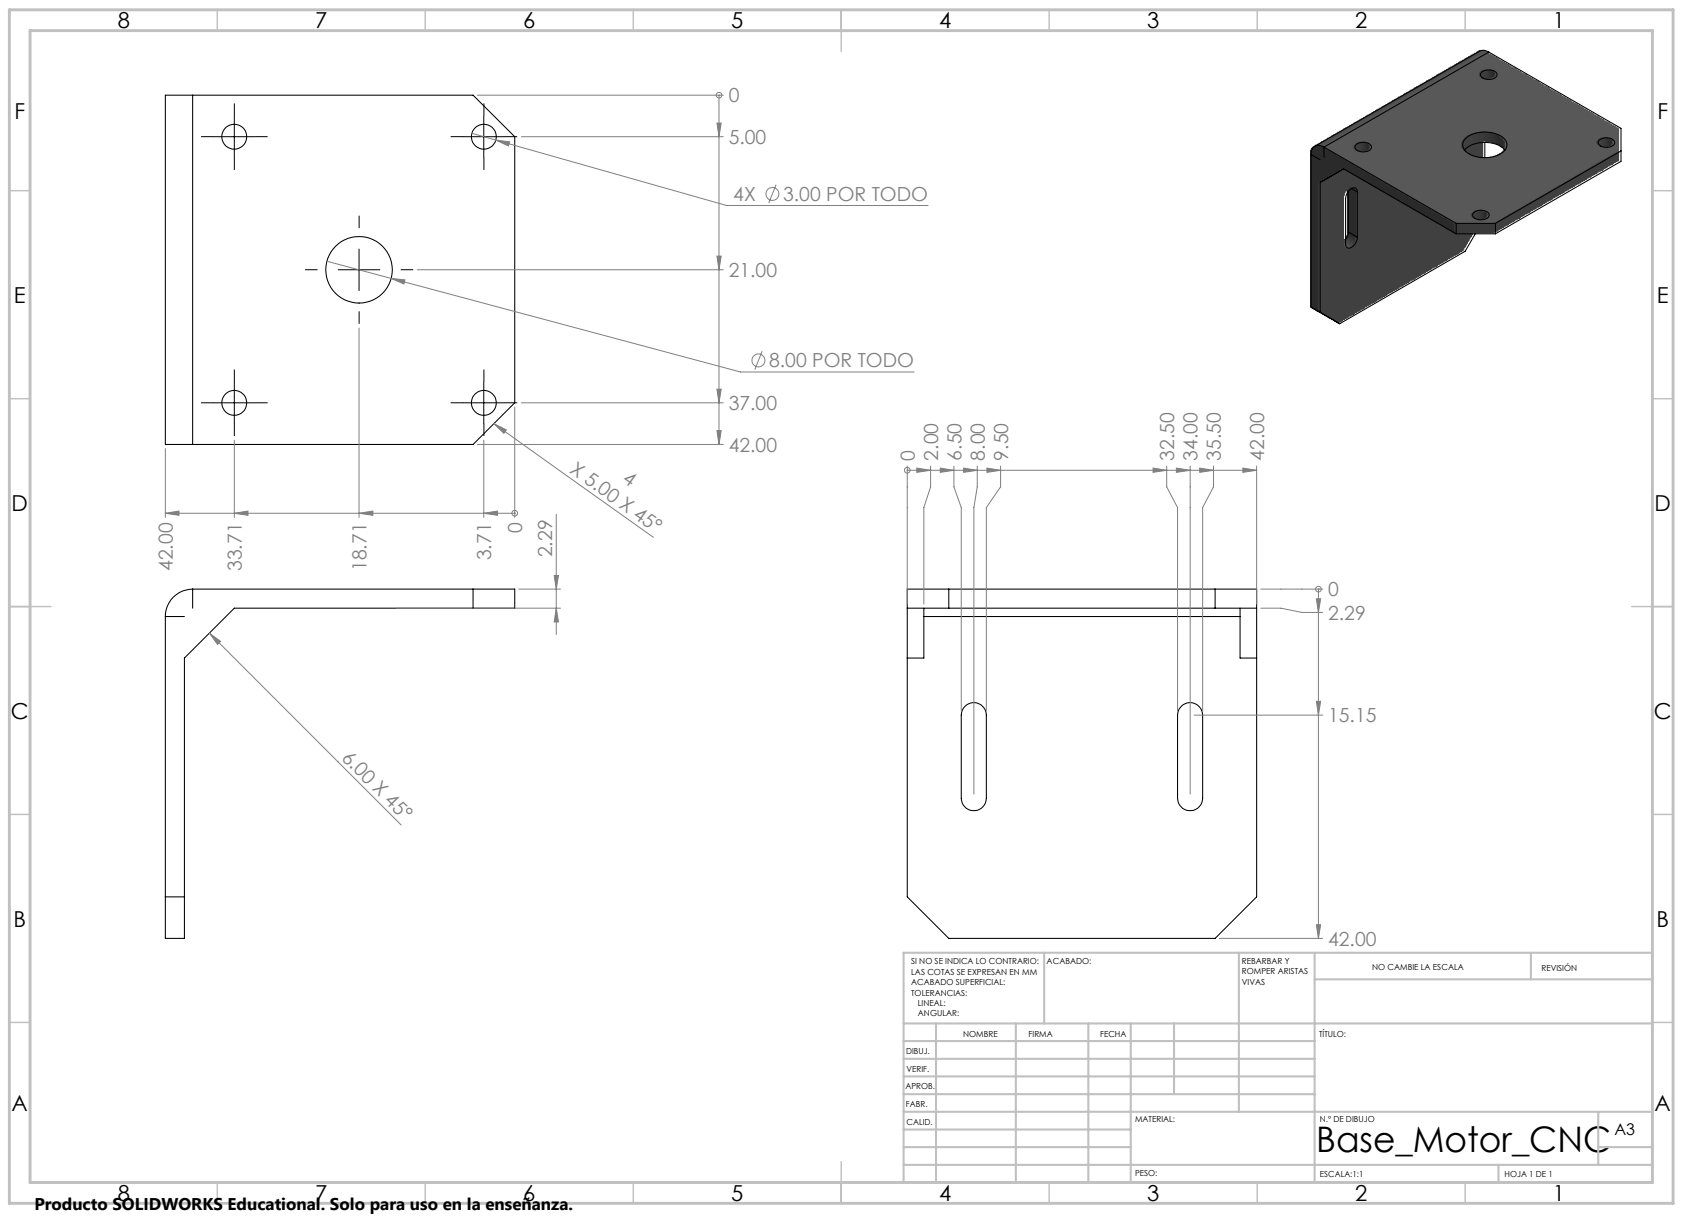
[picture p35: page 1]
4X 3.00 POR TODO; 8.00 POR TODO; ACABADO:; REBARBAR Y; ROMPER ARISTAS; NO CAMBIE LA ESCALA; REVISIÓN; ESCALA:1:1; HOJA 1 DE 1

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

NOMBRE | FIRMA | FECHA | | | | TÍTULO:

DIBUJ.
VERIF.
APROB.
FABR.
CALID. | | | | MATERIAL: | N.º DE DIBUJO Base_Motor_CNC | A3

Producto SOLIDWORKS Educational. Solo para uso en la enseñanza.

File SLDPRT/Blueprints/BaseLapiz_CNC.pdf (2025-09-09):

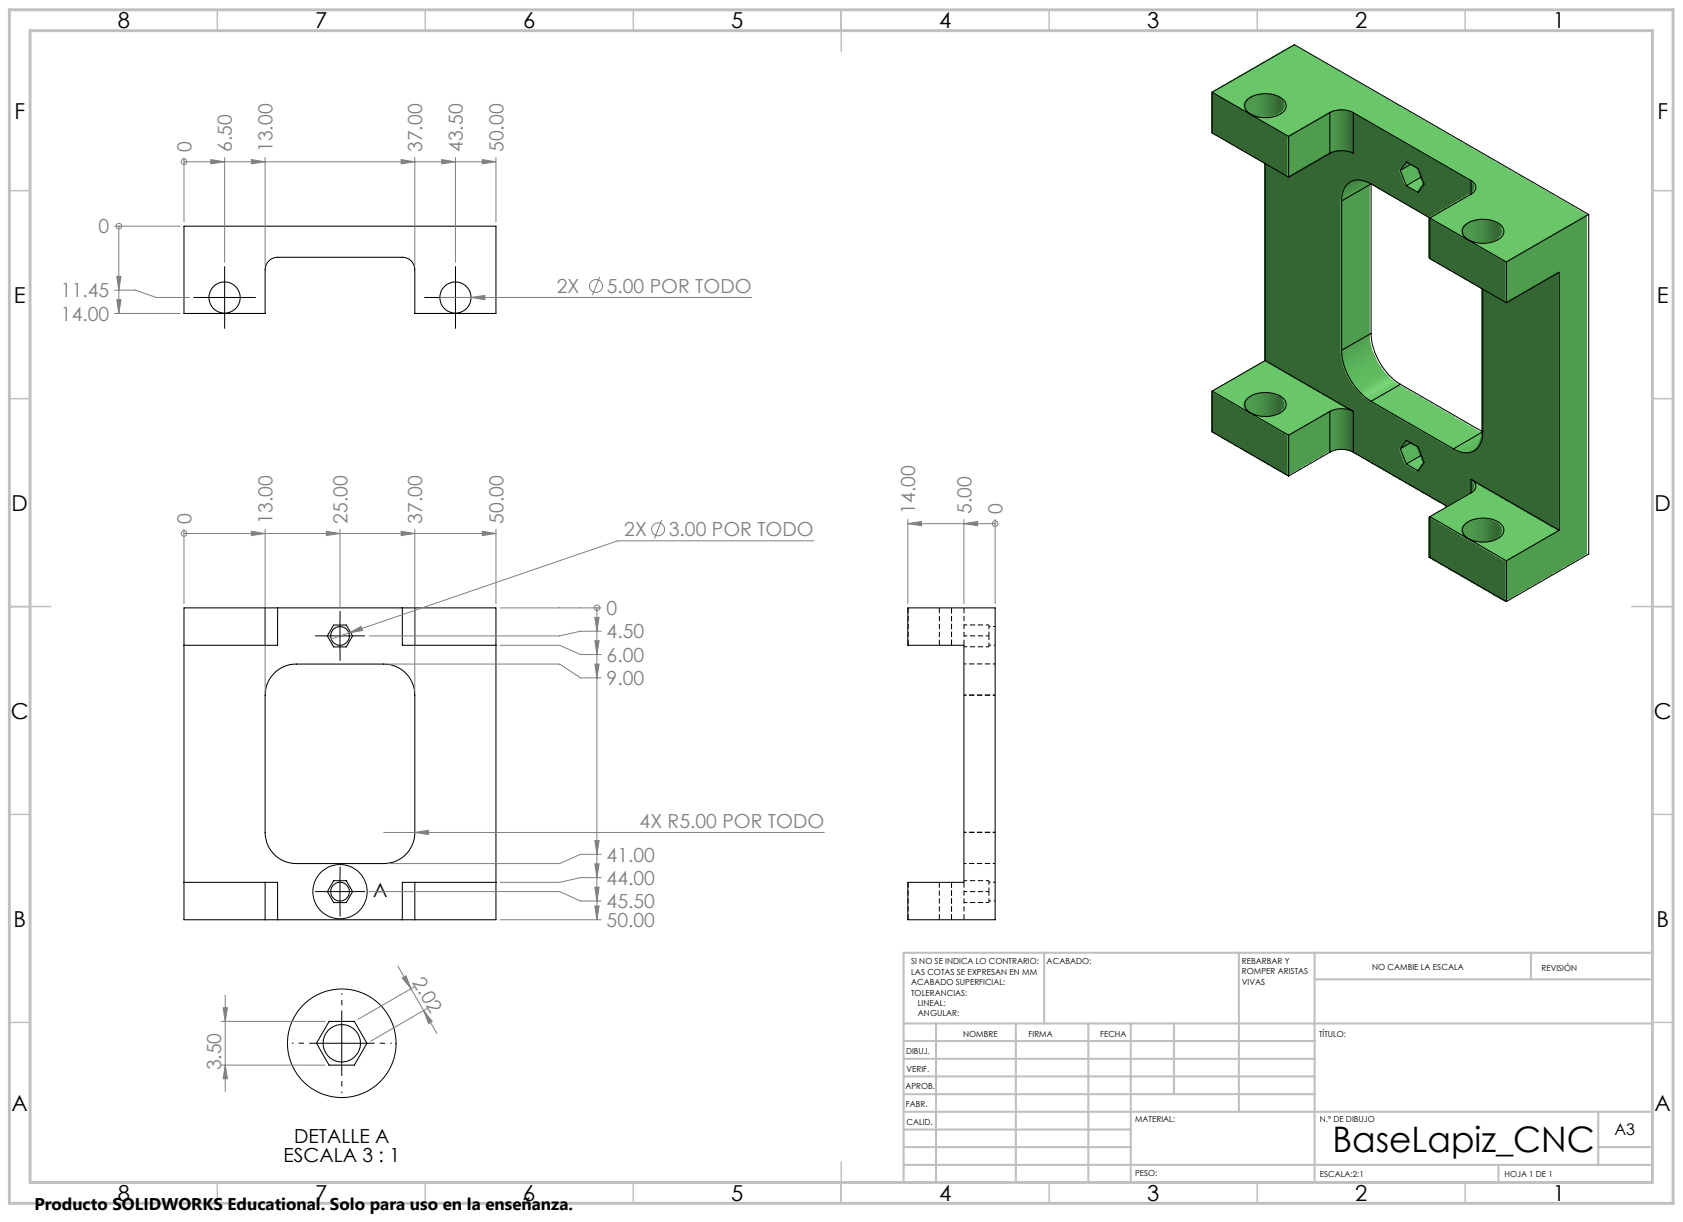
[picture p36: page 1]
4X R5.00 POR TODO; 2X 3.00 POR TODO; 5.00 POR TODO; DETALLE A ESCALA 3 : 1; ACABADO:; REBARBAR Y; ROMPER ARISTAS; NO CAMBIE LA ESCALA; REVISIÓN; ESCALA:2:1; HOJA 1 DE 1

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

NOMBRE | FIRMA | FECHA | | | | TÍTULO:

DIBUJ.
VERIF.
APROB.
FABR.
CALID. | | | | MATERIAL: | N.º DE DIBUJO BaseLapiz_CNC | A3

Producto SOLIDWORKS Educational. Solo para uso en la enseñanza.

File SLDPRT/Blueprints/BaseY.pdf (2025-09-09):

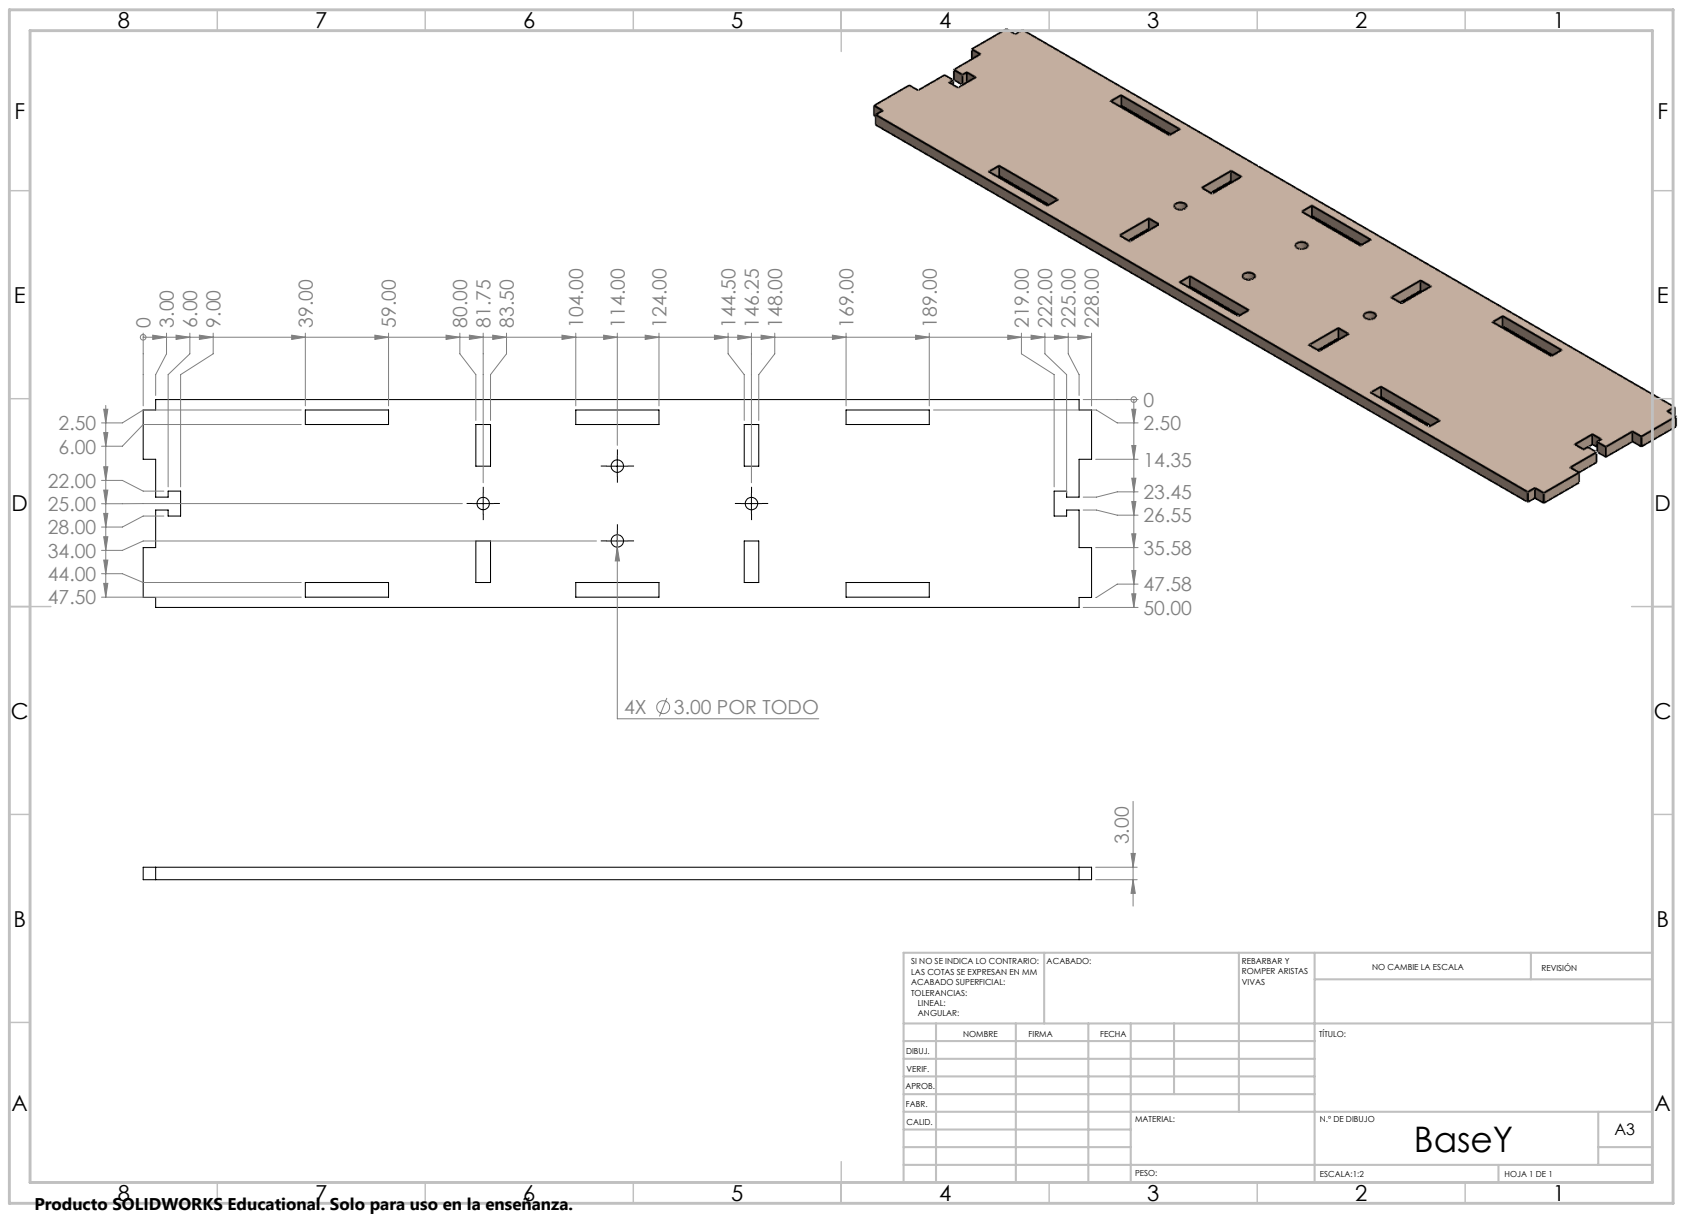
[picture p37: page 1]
4X 3.00 POR TODO; ACABADO:; REBARBAR Y; ROMPER ARISTAS; NO CAMBIE LA ESCALA; REVISIÓN; ESCALA:1:2; HOJA 1 DE 1

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

NOMBRE | FIRMA | FECHA | | | | TÍTULO:

DIBUJ.
VERIF.
APROB.
FABR.
CALID. | | | | MATERIAL: | N.º DE DIBUJO BaseY | A3

Producto SOLIDWORKS Educational. Solo para uso en la enseñanza.

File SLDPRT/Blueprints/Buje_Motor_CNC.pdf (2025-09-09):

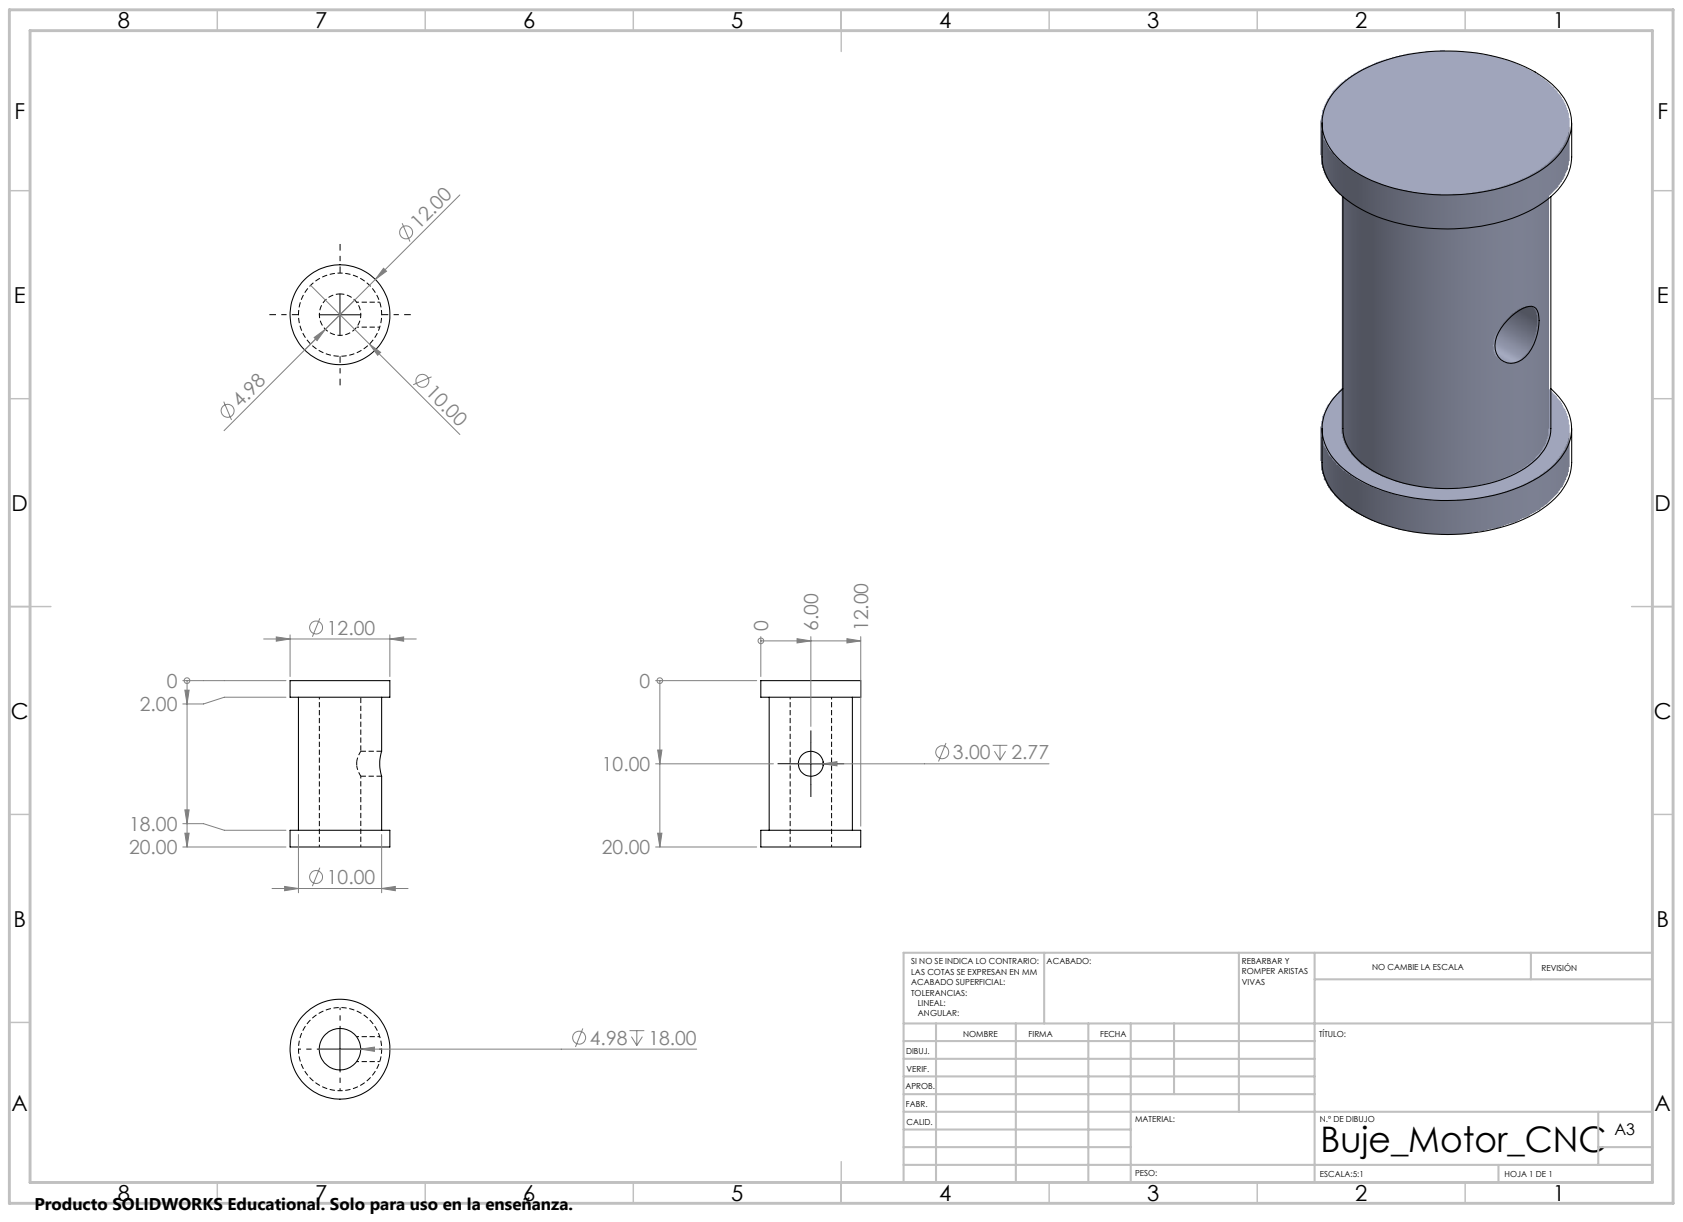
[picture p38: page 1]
ACABADO:; REBARBAR Y; ROMPER ARISTAS; NO CAMBIE LA ESCALA; REVISIÓN; ESCALA:5:1; HOJA 1 DE 1

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

NOMBRE | FIRMA | FECHA | | | | TÍTULO:

DIBUJ.
VERIF.
APROB.
FABR.
CALID. | | | | MATERIAL: | N.º DE DIBUJO Buje_Motor_CNC | A3

Producto SOLIDWORKS Educational. Solo para uso en la enseñanza.

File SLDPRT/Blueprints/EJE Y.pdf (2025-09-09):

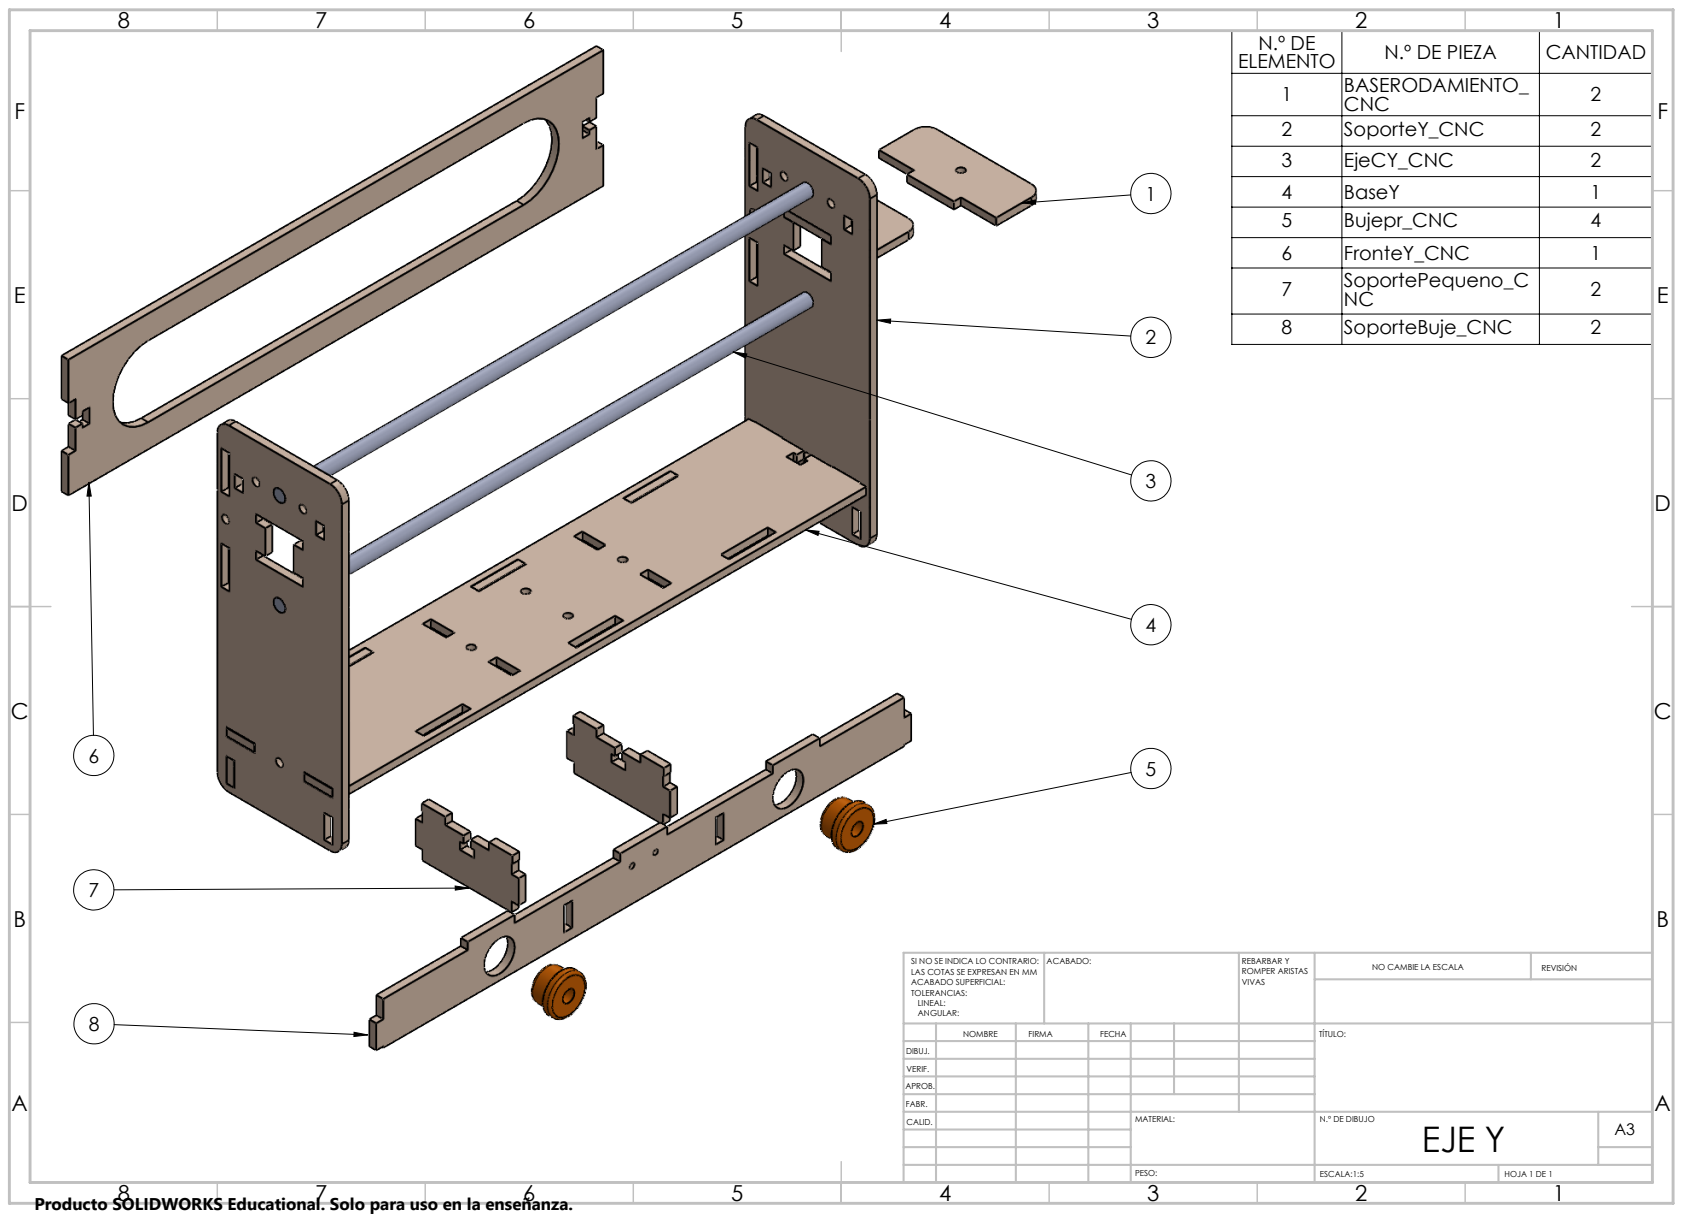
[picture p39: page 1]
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

N.º DE ELEMENTO | N.º DE PIEZA | CANTIDAD
1 | BASERODAMIENTO_ CNC | 2
2 | SoporteY_CNC | 2
3 | EjeCY_CNC | 2
4 | BaseY | 1
5 | Bujepr_CNC | 4
6 | FronteY_CNC | 1
7 | SoportePequeno_C NC | 2
8 | SoporteBuje_CNC | 2

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

NOMBRE | FIRMA | FECHA | | | | TÍTULO:

DIBUJ.
VERIF.
APROB.
FABR.
CALID. | | | | MATERIAL: | N.º DE DIBUJO EJE Y | A3

Producto SOLIDWORKS Educational. Solo para uso en la enseñanza.

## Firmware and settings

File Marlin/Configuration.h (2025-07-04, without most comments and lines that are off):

#define CONFIGURATION_H
#define CONFIGURATION_H_VERSION 010100
#define STRING_CONFIG_H_AUTHOR "(none, default config)" // Who made the changes.
#define SHOW_BOOTSCREEN
#define STRING_SPLASH_LINE1 SHORT_BUILD_VERSION // will be shown during bootup in line 1
#define STRING_SPLASH_LINE2 WEBSITE_URL         // will be shown during bootup in line 2
#define SERIAL_PORT 0
#define BAUDRATE 115200
  #define MOTHERBOARD BOARD_RAMPS_14_EFF
#define EXTRUDERS 2
#define POWER_SUPPLY 0
#define TEMP_SENSOR_0 998
#define TEMP_SENSOR_1 998
#define TEMP_SENSOR_2 0
#define TEMP_SENSOR_3 0
#define TEMP_SENSOR_4 0
#define TEMP_SENSOR_BED 0
#define DUMMY_THERMISTOR_998_VALUE 25
#define DUMMY_THERMISTOR_999_VALUE 100
#define MAX_REDUNDANT_TEMP_SENSOR_DIFF 10
#define TEMP_RESIDENCY_TIME 10  // (seconds)
#define TEMP_HYSTERESIS 3       // (degC) range of +/- temperatures considered "close" to the target one
#define TEMP_WINDOW     1       // (degC) Window around target to start the residency timer x degC early.
#define TEMP_BED_RESIDENCY_TIME 10  // (seconds)
#define TEMP_BED_HYSTERESIS 3       // (degC) range of +/- temperatures considered "close" to the target one
#define TEMP_BED_WINDOW     1       // (degC) Window around target to start the residency timer x degC early.
#define HEATER_0_MINTEMP 5
#define HEATER_1_MINTEMP 5
#define HEATER_2_MINTEMP 5
#define HEATER_3_MINTEMP 5
#define HEATER_4_MINTEMP 5
#define BED_MINTEMP 5
#define HEATER_0_MAXTEMP 275
#define HEATER_1_MAXTEMP 275
#define HEATER_2_MAXTEMP 275
#define HEATER_3_MAXTEMP 275
#define HEATER_4_MAXTEMP 275
#define BED_MAXTEMP 150
#define PIDTEMP
#define BANG_MAX 255 // limits current to nozzle while in bang-bang mode; 255=full current
#define PID_MAX BANG_MAX // limits current to nozzle while PID is active (see PID_FUNCTIONAL_RANGE below); 255=full current
  #define PID_FUNCTIONAL_RANGE 10 // If the temperature difference between the target temperature and the actual temperature
  #define K1 0.95 //smoothing factor within the PID
  #define  DEFAULT_Kp 22.2
  #define  DEFAULT_Ki 1.08
  #define  DEFAULT_Kd 114
#define MAX_BED_POWER 255 // limits duty cycle to bed; 255=full current
#define PREVENT_COLD_EXTRUSION
#define EXTRUDE_MINTEMP 170
#define PREVENT_LENGTHY_EXTRUDE
#define EXTRUDE_MAXLENGTH 200
#define THERMAL_PROTECTION_HOTENDS // Enable thermal protection for all extruders
#define THERMAL_PROTECTION_BED     // Enable thermal protection for the heated bed
#define USE_XMIN_PLUG
#define USE_YMIN_PLUG
#define USE_ZMIN_PLUG
#define USE_ZMAX_PLUG
#define ENDSTOPPULLUPS // Comment this out (using // at the start of the line) to disable the endstop pullup resistors
#define X_MIN_ENDSTOP_INVERTING true // set to true to invert the logic of the endstop.
#define Y_MIN_ENDSTOP_INVERTING true // set to true to invert the logic of the endstop.
#define Z_MIN_ENDSTOP_INVERTING true // set to true to invert the logic of the endstop.
#define X_MAX_ENDSTOP_INVERTING true // set to true to invert the logic of the endstop.
#define Y_MAX_ENDSTOP_INVERTING true // set to true to invert the logic of the endstop.
#define Z_MAX_ENDSTOP_INVERTING true // set to true to invert the logic of the endstop.
#define Z_MIN_PROBE_ENDSTOP_INVERTING false // set to true to invert the logic of the probe.
#define DEFAULT_AXIS_STEPS_PER_UNIT   { 400, 400, 400, 500 }
#define DEFAULT_MAX_FEEDRATE          { 5000, 5000, 5000, 25 }
#define DEFAULT_MAX_ACCELERATION      { 500, 500, 100, 10000 }
#define DEFAULT_ACCELERATION          300    // X, Y, Z and E acceleration for printing moves
#define DEFAULT_RETRACT_ACCELERATION  800    // E acceleration for retracts
#define DEFAULT_TRAVEL_ACCELERATION   200    // X, Y, Z acceleration for travel (non printing) moves
#define DEFAULT_XJERK                 5.0
#define DEFAULT_YJERK                 5.0
#define DEFAULT_ZJERK                  0.4
#define DEFAULT_EJERK                  5.0
#define Z_MIN_PROBE_USES_Z_MIN_ENDSTOP_PIN
#define X_PROBE_OFFSET_FROM_EXTRUDER 10  // X offset: -left  +right  [of the nozzle]
#define Y_PROBE_OFFSET_FROM_EXTRUDER 10  // Y offset: -front +behind [the nozzle]
#define Z_PROBE_OFFSET_FROM_EXTRUDER 0   // Z offset: -below +above  [the nozzle]
#define XY_PROBE_SPEED 8000
#define Z_PROBE_SPEED_FAST HOMING_FEEDRATE_Z
#define Z_PROBE_SPEED_SLOW (Z_PROBE_SPEED_FAST / 2)
#define Z_CLEARANCE_DEPLOY_PROBE   10 // Z Clearance for Deploy/Stow
#define Z_CLEARANCE_BETWEEN_PROBES  5 // Z Clearance between probe points
#define Z_PROBE_OFFSET_RANGE_MIN -20
#define Z_PROBE_OFFSET_RANGE_MAX 20
#define X_ENABLE_ON 0
#define Y_ENABLE_ON 0
#define Z_ENABLE_ON 0
#define E_ENABLE_ON 0 // For all extruders
#define DISABLE_X false
#define DISABLE_Y false
#define DISABLE_Z false
#define DISABLE_REDUCED_ACCURACY_WARNING
#define DISABLE_E false // For all extruders
#define DISABLE_INACTIVE_EXTRUDER true // Keep only the active extruder enabled.
#define INVERT_X_DIR false
#define INVERT_Y_DIR true
#define INVERT_Z_DIR false
#define X_DRIVER_TYPE DRV8825
#define Y_DRIVER_TYPE DRV8825
#define INVERT_E0_DIR false
#define INVERT_E1_DIR false
#define INVERT_E2_DIR false
#define INVERT_E3_DIR false
#define INVERT_E4_DIR false
#define X_HOME_DIR -1
#define Y_HOME_DIR -1
#define Z_HOME_DIR 1
#define X_BED_SIZE 100 // X axis travel after homing 280 120
#define Y_BED_SIZE 80 // Y axis travel after homing 220
#define X_MIN_POS 0
#define Y_MIN_POS 0
#define Z_MIN_POS 0
#define X_MAX_POS X_BED_SIZE
#define Y_MAX_POS Y_BED_SIZE
#define Z_MAX_POS 100 // to see
#define MANUAL_X_HOME_POS 0
#define MANUAL_Y_HOME_POS 0
#define MANUAL_Z_HOME_POS 0
#define HOMING_FEEDRATE_XY (10*60)
#define HOMING_FEEDRATE_Z  (5*60)
#define EEPROM_SETTINGS // Enable for M500 and M501 commands
#define DISABLE_M503    // Saves ~2700 bytes of PROGMEM. Disable for release!
#define EEPROM_CHITCHAT   // Give feedback on EEPROM commands. Disable to save PROGMEM.
#define HOST_KEEPALIVE_FEATURE        // Disable this if your host doesn't like keepalive messages
#define DEFAULT_KEEPALIVE_INTERVAL 2  // Number of seconds between "busy" messages. Set with M113.
#define PREHEAT_1_TEMP_HOTEND 180
#define PREHEAT_1_TEMP_BED     70
#define PREHEAT_1_FAN_SPEED     0 // Value from 0 to 255
#define PREHEAT_2_TEMP_HOTEND 240
#define PREHEAT_2_TEMP_BED    110
#define PREHEAT_2_FAN_SPEED     0 // Value from 0 to 255
#define PRINTJOB_TIMER_AUTOSTART
#define PRINTCOUNTER
#define LCD_LANGUAGE en
#define DISPLAY_CHARSET_HD44780 JAPANESE
#define DOGLCD      // Full graphics display
#define SDSUPPORT
#define REVERSE_MENU_DIRECTION
#define INDIVIDUAL_AXIS_HOMING_MENU
#define SPEAKER
#define LCD_FEEDBACK_FREQUENCY_DURATION_MS 0 //100
#define LCD_FEEDBACK_FREQUENCY_HZ 0 //1000
#define REPRAP_DISCOUNT_FULL_GRAPHIC_SMART_CONTROLLER
#define FAST_PWM_FAN
#define NUM_SERVOS 1 // Servo index starts with 0 for M280 command
#define SERVO_DELAY 300
#define DEFAULT_NOMINAL_FILAMENT_DIA 1.7500   // (mm) Diameter of the filament generally used (3.0 or 1.75mm), also used in the slicer. Used to validate sensor reading.

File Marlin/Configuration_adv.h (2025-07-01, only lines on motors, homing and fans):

#define E0_AUTO_FAN_PIN -1
#define E1_AUTO_FAN_PIN -1
#define E2_AUTO_FAN_PIN -1
#define E3_AUTO_FAN_PIN -1
#define E4_AUTO_FAN_PIN -1
#define X_HOME_BUMP_MM 5
#define Y_HOME_BUMP_MM 5
#define Z_HOME_BUMP_MM 2
#define HOMING_BUMP_DIVISOR {2, 2, 4}  // Re-Bump Speed Divisor (Divides the Homing Feedrate)
#define MICROSTEP_MODES {16,16,16,16,16} // [1,2,4,8,16]
#define DIGIPOT_I2C_MOTOR_CURRENTS { 1.0, 1.0, 1.0, 1.0, 1.0, 1.0, 1.0, 1.0 }  //  AZTEEG_X3_PRO

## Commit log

2025-06-29 Boot display description changed
    [Configuration.h]
2025-07-01 Servo addition and testing
    [Configuration.h, Configuration_adv.h]
2025-07-02 Axis steps and driver DRV8825 declaration
    [Configuration.h]
2025-07-04 Motor, drivers and calibration setup
    [Configuration.h]
2025-07-11 README, documentation and blueprints addition
    [UACJ.g]
2025-09-09 Blueprints directory changed -> SLDPRT and SLDASM files addition
    [BASERODAMIENTO_CNC.SLDDRW, BASERODAMIENTO_CNC.SLDPRT, BaseLapiz_CNC.SLDDRW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]

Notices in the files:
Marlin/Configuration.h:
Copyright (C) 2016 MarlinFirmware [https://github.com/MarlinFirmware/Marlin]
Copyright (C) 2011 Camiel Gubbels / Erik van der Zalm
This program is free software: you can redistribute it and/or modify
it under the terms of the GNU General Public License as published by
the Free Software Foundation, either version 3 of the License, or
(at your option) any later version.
